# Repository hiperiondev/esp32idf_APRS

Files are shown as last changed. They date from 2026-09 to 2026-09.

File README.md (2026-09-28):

<p align="center">
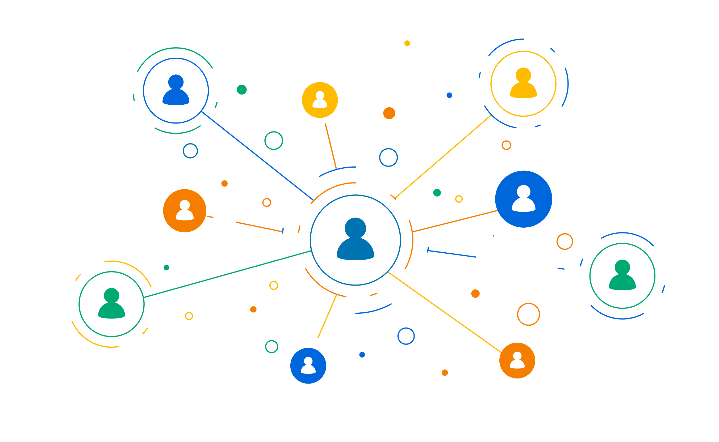
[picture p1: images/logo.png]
  
</p>

<div align="center">

# esp32idf_APRS

### A complete APRS station on a single ESP32 — native ESP-IDF, no Arduino.

**IGate · Digipeater · Tracker · Weather · Telemetry**, with a built-in web admin, an on-chip AFSK/FSK soft-modem, APRS-IS uplink, a runtime sensor-driver framework and OTA firmware updates.






**🌐 Languages:** **English** · [Español](README.es.md) · [Italiano](README.it.md)

</div>

---

## What is this?

`esp32idf_APRS` turns a bare **ESP32 DevKit** plus a cheap audio interface into a complete, self-contained **APRS** station. Everything runs on the ESP32 itself — there is no Arduino core, no PlatformIO, and no external DSP library. The entire signal chain, from the correlator demodulator through DPLL bit recovery, NRZI, the HDLC framer, the AX.25 codec and Reed–Solomon FX.25 forward error correction, executes on the microcontroller using only the SAR-ADC in continuous/DMA mode, the DAC, and a general-purpose timer.

In one sentence, the firmware **demodulates** AFSK/FSK audio from a radio's speaker or discriminator output, **decodes** HDLC/AX.25 (optionally FX.25 error-corrected) frames, **gates** them to APRS-IS over Wi-Fi, **digipeats** them back on RF, **beacons** its own position, weather and telemetry, **modulates** and transmits frames back through the ESP32's 8-bit DAC — and is configured entirely through a web admin served by the device itself. No serial console, no recompilation for ordinary settings.

> 📖 **The full, exhaustive documentation lives at [esp32idf-aprs.readthedocs.io](https://esp32idf-aprs.readthedocs.io/)** — trilingual (English / Español / Italiano), with getting-started guides, hardware wiring, the DSP signal chain, the configuration engine, HTTP routes and troubleshooting. **This README is only a presentation. For anything beyond a first look, go to the docs.**

---

## Highlights

- **On-chip soft-modem.** AFSK 1200 Bd Bell 202 (standard APRS) with up to twelve parallel demodulators (a multi-slicer set on four tilted prefilters covering about 33 dB of tone twist, from discriminator and speaker audio alike, tunable from the web admin, with a tone-band receive level meter), plus AFSK 1200 Bd V.23, AFSK 300 Bd, and **G3RUH 9600 Bd FSK** — all in pure C on the ESP32's own ADC/DAC.
- **FX.25 forward error correction.** Reed–Solomon FEC over AX.25, RX-only or RX+TX, for reliable decodes in weak-signal conditions.
- **Full APRS-IS IGate.** Bidirectional **RF→INET** and **INET→RF** gating with duplicate suppression, `qAR`/`qAO` construction, payload-type gating, callsign budlists, a local range gate (haversine distance), a prefix whitelist and, on the INET→RF side, a position requirement, a locally-heard source test and per-source spacing that keep a wide APRS-IS subscription off the local channel. Up to four APRS-IS servers can be listed, with automatic failover between the enabled ones.
- **BrandMeister APRS interconnect.** Recognises, gates and routes the APRS traffic BrandMeister injects, over the APRS-IS session the IGate already has — an `APBMxx` tocall, a `DMR` path alias or a named entry gateway identifies it. Its own page, off by default. **No DMR connection of any kind is involved.**
- **Digipeater.** A four-row n-N alias table (WIDE1-1 / WIDE2-2 / WIDE#-2 by default), each row with its own hop limit and trace/flood mode, plus hop-count trapping, fill-in-only operation and duplicate suppression.
- **Beacons, messaging & chat.** Fixed-position beacons for tracker/igate/digi, APRS text messaging with ack/retry (RF and/or INET), and an in-browser message chat UI.
- **GNSS receiver & live tracking.** An NMEA module on its own UART (RMC/GGA/GSA/GSV/VTG, multi-constellation) with a master switch, a live view page refreshed once a second, and a *Use GPS* control that fills any page's position fields from the current fix. The Tracker beacon can transmit the live fix instead of a fixed position, with SmartBeaconing making the interval speed-adaptive and pegging it on corners.
- **APRS query responder.** Answers the general `?APRS?`/`?WX?`/`?IGATE?`/`?QRU?` queries and the directed set (`?APRSD`/`?APRSH`/`?APRSM`/`?APRSO`/`?APRSP`/`?APRSS`/`?APRST`/`?PING?`), each with per-type and per-source rate limits, plus an optional periodic station-capabilities beacon.
- **Weather & telemetry.** On-air APRS Weather Reports with 1 Hz sensor refresh and per-field averaging, plus APRS Telemetry (analog A1–A5 + digital B1–B8) with `T#nnn` reports and metadata.
- **Winlink radio e-mail (APRSLink).** The station reads and writes its own `CALLSIGN@winlink.org` mail through the `WLNK-1` service — challenge/response login with the password never on the air, a paced one-command-at-a-time session, and a browser terminal whose mailbox listing carries per-message read/reply/forward/delete buttons — and, separately, relays a neighbouring RF station's own Winlink session through its IGate.
- **Objects, items & bulletins.** Up to five own-station APRS Objects/Items and five bulletins (BLN1–BLN5), each on RF and/or INET with expiry/decay control.
- **Telegram bot.** An optional bot alongside the APRS services — long polling, per-user and per-chat authorization, station-message and bulletin routing to Telegram, and a Mini App button — so the station can be checked on and lightly controlled from a phone.
- **Runtime sensor framework.** A dynamic, self-registering driver registry (`sensors_local`) — includes a BME280/BMP280 (I²C) driver out of the box, plus an optional BMP180 one on the same bus.
- **Web admin, 22 pages.** HTTP Basic auth with two accounts — an administrator and an optional read-only one that sees every page, changes nothing, and may only start and stop the console log viewer —, a live dashboard with a live traffic log (JSON long-poll) and a last-heard JSON feed, LittleFS file management (upload/download/delete/format), Wi-Fi AP/STA/AP+STA with scan and TX-power control, CPU frequency control (80/160/240 MHz), and an on-demand console log viewer that mirrors the serial output into the browser. The whole UI is responsive from one stylesheet — on a tablet or a phone the sidebar becomes a slide-in drawer, form rows collapse to a single column, wide tables scroll within the page and the controls grow to a touch size.
- **OTA updates with auto-rollback.** Dual `ota_0`/`ota_1` app slots; a failed image rolls back automatically on the next boot.
- **Trilingual UI.** English, Spanish and Italian (compile-time, one language per image).

---

## Feature matrix

| Area | Notes |
|---|---|
| AFSK 1200 Bd Bell 202 | Up to twelve parallel demodulators, default profile |
| AFSK 1200 Bd V.23 · AFSK 300 Bd · G3RUH 9600 Bd FSK | Multiple selectable modem profiles |
| HDLC / AX.25 UI frame RX + TX | Full soft-modem TX/RX path |
| FX.25 (Reed–Solomon FEC over AX.25) | RX-only / RX+TX modes |
| PTT keying | Compile-time GPIO + polarity, minimum-unkey hold |
| CSMA / TX time-slot / TXDelay preamble / TXTail | `preamble`, `tx_tail` (TXTail, default 20 ms), `tx_timeslot`, `csma_persist`, `csma_slot_ms` (SlotTime), `csma_busy_max_s` (busy-channel wait, 0 = unlimited) |
| Transmit duty-cycle limiter | Optional ceiling over a rolling 10-minute window |
| APRS-IS IGate RF→INET & INET→RF | Filters, dedup, budlist, third-party unwrap opt-in, INET→RF flood gates |
| APRS-IS multiserver failover | 4 server slots, circular retry over the enabled ones |
| Local range gate & prefix gate | Haversine distance + callsign-prefix whitelist |
| BrandMeister APRS interconnect | Recognition, gating and message routing over the existing APRS-IS session; no DMR link |
| Digipeater | Configurable n-N alias table (trace/flood), hop trapping, dup-suppression |
| Objects / Items · Bulletins | Up to 5 each, RF and/or INET, expiry/decay |
| Telegram bot | Long polling, per-user/chat authorization, message & bulletin routing, Mini App button |
| Messaging + ack/retry · Chat UI | RF and/or INET |
| Winlink radio e-mail (APRSLink) | Own mailbox over `WLNK-1`, plus gateway for local stations |
| GNSS receiver (NMEA, own UART) | Master switch, live view page, *Use GPS* position fill on every page |
| Live GPS tracking + SmartBeaconing | Tracker beacon only; speed-adaptive interval and corner-pegging |
| APRS query responder | General `?APRS?`/`?WX?`/`?IGATE?`/`?QRU?` + directed set, rate-limited; capabilities beacon |
| Weather Report | 1 Hz sensor refresh, optional averaging |
| Telemetry | Analog A1–A5 + digital B1–B8, `T#nnn` + metadata |
| Sensor driver framework | Dynamic registry, BME280/BMP280 driver included |
| Web admin | 22 pages, live dashboard, live traffic log + last-heard feed, console log viewer, per-option contextual help |
| Storage | LittleFS 512 KB, upload/download/delete/format |
| Networking | Wi-Fi AP/STA/AP+STA, scan, TX power, SNTP (UTC clock, selectable timezone for display) |
| CPU frequency control | 80 / 160 / 240 MHz |
| OTA update | `ota_0`/`ota_1` slots, auto-rollback |
| Localization | EN / ES / IT, compile-time, labels and help balloons alike |

---

## Hardware

- **Target:** ESP32 (classic, Xtensa dual-core), 4 MB flash. Dual-core is **required** — the ADC ISR and DAC sample clock are pinned to different cores on purpose.
- **Audio in (ADC):** default `GPIO33` (ADC1). **GPIO 32–39 only** — ADC2 is unusable while Wi-Fi is up.
- **Audio out (DAC):** default `GPIO25`. **GPIO 25 or 26 only** — the ESP32 DAC is hard-wired to those pads.
- **PTT:** default `GPIO26`, polarity selectable at compile time.
- **GNSS (optional):** UART2, default `GPIO16` (RX, from the module's TX) and `GPIO17` (TX). Set in `main/include/gps.h`. **Unusable on an ESP32-WROVER**, where those pins belong to the SPI PSRAM die.
- **Note:** ESP32-S3/C3/C6/H2 have **no DAC** and cannot run the TX path unmodified.

Board wiring (audio pins, PTT pin/polarity, ADC sample rate) is set as compile-time constants in the top-level `CMakeLists.txt`. A KiCad radio-interface schematic is included under `schematics/`.

The audio interface itself can be as small as one coupling capacitor and one level trimmer per direction: the Radiomodem page carries an **Audio interface** section that biases the ADC input from the pad's own pull resistors, sets the transmit output swing and sample rate, warns on receive over-range and bounds how long the transmitter may stay keyed. Every one of those settings defaults to the behaviour an interface board with its own bias network, attenuators and reconstruction filter expects, so an existing build is unaffected. Two buttons next to LOOP TEST — **RX LEVEL** and **TX TEST** — set the two trimmers once a transceiver has replaced the loopback jumper.

> Full pinout tables and wiring constraints are in the [Hardware chapter of the documentation](https://esp32idf-aprs.readthedocs.io/en/latest/en/hardware.html).

---

## Quick start

```bash
# Requires ESP-IDF v6.1 (tested and locked at 6.1)
idf.py set-target esp32
idf.py build
idf.py -p PORT flash monitor
```

On first boot the device brings up a Wi-Fi AP; connect and open the web admin to configure your callsign, radio and services. After the one-time USB/UART flash, all further updates can be done from the web admin's **About / Firmware** page over OTA.

> 📖 The step-by-step first-run guide is in [Getting Started](https://esp32idf-aprs.readthedocs.io/en/latest/en/getting-started.html).

---

## Documentation

**Everything is documented in full at 👉 [esp32idf-aprs.readthedocs.io](https://esp32idf-aprs.readthedocs.io/)**

The documentation is trilingual and organised into *Functionalities* (what the station does), *Capabilities* (cross-cutting properties), *Internals* (how it is built) and a *Reference* section:

- 🇬🇧 [English](https://esp32idf-aprs.readthedocs.io/en/latest/en/index.html)
- 🇪🇸 [Español](https://esp32idf-aprs.readthedocs.io/en/latest/es/index.html)
- 🇮🇹 [Italiano](https://esp32idf-aprs.readthedocs.io/en/latest/it/index.html)

This README is a presentation only — **please consult the documentation for installation, wiring, configuration and internals.**

---

## Credits & license

Created by **Emiliano Augusto González (LU3VEA)**.

Built on ideas from earlier projects — [VP-Digi](https://github.com/sq8vps/vp-digi), [ESP32APRS](https://github.com/nakhonthai/ESP32APRS_Audio) and [LibAPRS](https://github.com/markqvist/LibAPRS); please refer to their authors for more information.

Released under the **GNU General Public License v3**. See [LICENSE](LICENSE).

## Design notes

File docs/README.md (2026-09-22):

# esp32idf_APRS — Documentation

Exhaustive, trilingual (English / Español / Italiano) documentation for the
`esp32idf_APRS` firmware, built with [Sphinx](https://www.sphinx-doc.org/) and
the [Breeze](https://pypi.org/project/sphinx-breeze-theme/) theme, ready to
publish on Read the Docs.

## Layout

```
esp32_APRS_igate/
├── .readthedocs.yaml    Read the Docs build config (repo root, not docs/)
└── docs/
    ├── root/index.html      language-chooser landing page ("first page")
    ├── _shared/conf_base.py shared Sphinx config (theme, extensions, language switcher)
    ├── en/                  English source tree (conf.py + .rst + _static/)
    ├── es/                  Spanish source tree (conf.py + .rst + _static/)
    ├── it/                  Italian source tree (conf.py + .rst + _static/)
    ├── schematics/          radio-interface schematics (TX, RX, PTT) shared by the
    │                        three hardware.rst pages through ../schematics/
    ├── dataflow/, tuning/   master copies of the per-language data-flow and tuning
    │                        figures (each tree embeds its own copy from _static/)
    ├── _static/             master copies of custom.css and logo.png (not read by Sphinx)
    ├── requirements.txt     Sphinx + Breeze theme pins
    └── build_all.py         builds all three trees into ./_site
```
Each language tree carries its own `_static/` (identical copies of `custom.css`,
`logo.png` and `welcome_logo.png`, plus that language's `dataflow/` and `tuning/`
figures) since each is an independent Sphinx project and Sphinx only looks up
`html_static_path` inside its own source tree. The top-level `docs/_static/`,
`docs/dataflow/` and `docs/tuning/` folders are only the master copies those
trees are refreshed from; no build reads them, so an edited image or stylesheet
must be copied into each language's `_static/` to take effect. `logo.png` is the small top-bar brand
logo (set via `light_logo`/`dark_logo` in `_shared/conf_base.py`);
`welcome_logo.png` is the larger centered image at the top of each language's
Welcome page (`index.rst`). The two are independent by design.

Each language tree is a complete, independent Sphinx project. The three are
linked as **siblings** by the per-page language switcher (the globe menu in the
Breeze top bar): from any page in one language you can jump straight to the same
page in another. The `root/index.html` landing page lets a first-time visitor
pick a language.

The chapters are organised by **Functionality** (what the station does),
**Capability** (cross-cutting properties), and **Internals** (how it is built),
plus a **Reference** section.

## Build locally

```bash
python -m venv .venv && . .venv/bin/activate
pip install -r requirements.txt
python build_all.py
# open _site/index.html
```

Or build a single language on its own:

```bash
cd en && python -m sphinx -b html . _build   # then open _build/index.html
```

## Publish on Read the Docs

The included `.readthedocs.yaml` points its `sphinx:` block at the English tree
only to satisfy Read the Docs. Its `post_build` job then wipes that output and
rebuilds all three trees into sibling `en/`, `es/` and `it/` folders, placing
the landing page at the root — reproducing the sibling layout the switcher
needs, exactly like `build_all.py`. No dashboard configuration is required
beyond importing the repository.

Both `build_all.py` and the Read the Docs job run Sphinx with `-W`, so any
warning (a broken cross-reference, a missing image, a malformed table) fails
the build. Run `python build_all.py` locally before pushing a documentation
change.

## Requirements

* Python 3.10+
* Sphinx ≥ 8.1, < 9  (Sphinx 9 is not yet compatible with the Breeze theme)
* sphinx-breeze-theme 0.13.x

Both are pinned in `requirements.txt`.

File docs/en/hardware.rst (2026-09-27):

.. _en-hardware:

========
Hardware
========

Supported target
================

* **ESP32** (classic, Xtensa dual-core) — ``CONFIG_IDF_TARGET=esp32``, 4 MB
  flash.
* Dual-core is **not optional**: the ADC ISR and the DAC sample clock are
  pinned to *different* cores on purpose (see :ref:`en-dsp-signal-chain`).
* ESP32-S2 has DACs on GPIO17/18 and would need the config header adjusted.
  **ESP32-S3/C3/C6/H2 have no DAC at all** and cannot run the TX path
  unmodified.

Pinout / board definition
=========================

The board definition lives in the **top-level** ``CMakeLists.txt``, applied
*before* ``project()`` via ``idf_build_set_property(COMPILE_DEFINITIONS …
APPEND)``:

.. code-block:: cmake

   idf_build_set_property(COMPILE_DEFINITIONS "MODEM_ADC_GPIO=33"       APPEND)
   idf_build_set_property(COMPILE_DEFINITIONS "MODEM_DAC_GPIO=25"       APPEND)
   idf_build_set_property(COMPILE_DEFINITIONS "MODEM_PTT_GPIO=26"       APPEND)
   idf_build_set_property(COMPILE_DEFINITIONS "MODEM_PTT_ACTIVE_HIGH=1" APPEND)
   idf_build_set_property(COMPILE_DEFINITIONS "MODEM_LED_TX_GPIO=-1"    APPEND)
   idf_build_set_property(COMPILE_DEFINITIONS "MODEM_LED_RX_GPIO=-1"    APPEND)

.. list-table::
   :header-rows: 1
   :widths: 20 20 60

   * - Signal
     - Default
     - Hard constraints
   * - **Audio in (ADC)**
     - ``GPIO33`` (ADC1_CH5)
     - **32–39 only.** ADC2 is unusable while Wi-Fi is up, and this firmware
       always has Wi-Fi up. Enforced by a compile-time ``#error``.
   * - **Audio out (DAC)**
     - ``GPIO25`` (DAC_CHAN_0)
     - **25 or 26 only.** The ESP32 DAC is hard-wired to those pads and is not
       routable through the GPIO matrix. Enforced by ``#error``.
   * - **PTT**
     - ``GPIO26``
     - Any output-capable GPIO not equal to the ADC/DAC pins; rejects
       input-only GPIO34–39 and flash/PSRAM GPIO6–11. ``-1`` disables it.
       Both the pin **and its polarity** are compile-time constants.
   * - **TX / RX LEDs**
     - disabled (``-1``)
     - Any output-capable GPIO.
   * - **GNSS receive (UART RX)**
     - ``GPIO16``
     - Wired to the module's TX output. Any input-capable GPIO the UART
       matrix can reach. **Unusable on an ESP32-WROVER**, where GPIO16/17
       belong to the SPI PSRAM die. Set in ``main/include/gps.h``.
   * - **GNSS transmit (UART TX)**
     - ``GPIO17``
     - Wired to the module's RX input. Nothing is ever sent on it — the
       firmware never configures the receiver — but the pin is still
       reserved, since it is physically connected to that input.

Wiring to a radio
=================

Neither end of the audio link can be connected directly to the other. The
ESP32 side is a 3.3 V, DC-biased, sampled-data interface; the radio side is an
AC, ground-referenced, millivolt-level analogue interface. Three things have
to happen in between: **attenuate** (TX), **shift and clamp** (RX), and
**switch** (PTT).

What each end presents
----------------------

Every ESP32-side figure below is derived from the modem component's own
compile-time constants, not from a datasheet ideal.

.. list-table::
   :header-rows: 1
   :widths: 26 50 24

   * - Node
     - What is really there
     - From
   * - **GPIO25 (DAC), transmitting**
     - 1.65 V DC with a ≈1.97 Vpp swing on top ⇒ ≈0.70 Vrms for a sine, plus
       reconstruction images around 38.4 kHz
     - ``DAC_MID=128``, ``AMPLITUDE_PCT=60``, ``DAC_SAMPLERATE=38400``
   * - **GPIO33 (ADC)**
     - Window 0–3.1 V; AGC targets 310 mVrms at the pin, reaches it from as
       little as ≈39 mVrms, holds below ≈3.3 mVrms, clips above ≈1.1 Vrms
     - ``ADC_ATTEN_DB_12``, ``AGC_TARGET_RMS=0.2``
   * - Rig **MIC IN**
     - 5–20 mVrms, often pre-emphasised, DC bias for the electret
     - needs ≈30–40 dB of pad
   * - Rig **DATA IN** (mini-DIN-6)
     - ≈40 mVpp ⇒ ≈14 mVrms, flat, no pre-emphasis
     - needs ≈35 dB of pad
   * - Rig **SPKR / AF OUT**
     - 0.1–3 Vrms, volume-knob dependent, de-emphasised
     - needs a pad + bias
   * - Rig **DATA OUT / DISC**
     - 100–300 mVrms, fixed level, squelch-independent, flat
     - needs bias only — this is the good one

Two consequences worth internalising before soldering:

* **The DAC is ~35 dB too hot** for anything on the radio. A direct
  connection will not merely over-deviate, it will splatter.
* **A DATA OUT port is already inside the AGC window** (100–300 mVrms vs. the
  39 mVrms–1.1 Vrms usable range). If your rig has a data jack, the RX side is
  a bias network and nothing else — no pot, no gain.

Minimal functional schematic
----------------------------

Passive, ~15 parts, no op-amps.

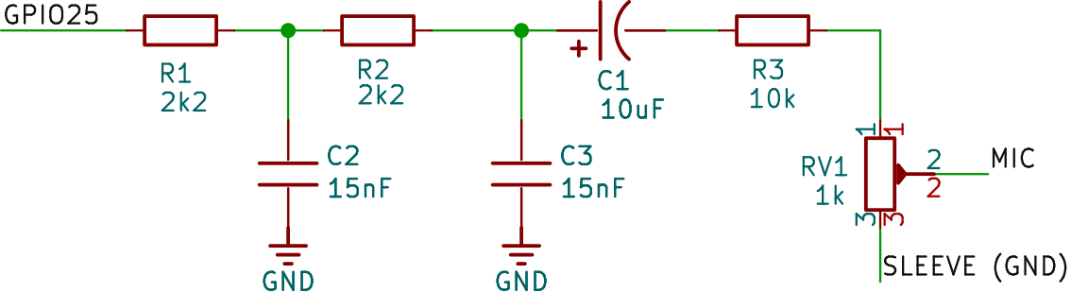
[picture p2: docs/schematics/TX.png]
TX schematic — ESP32 DAC to rig audio input


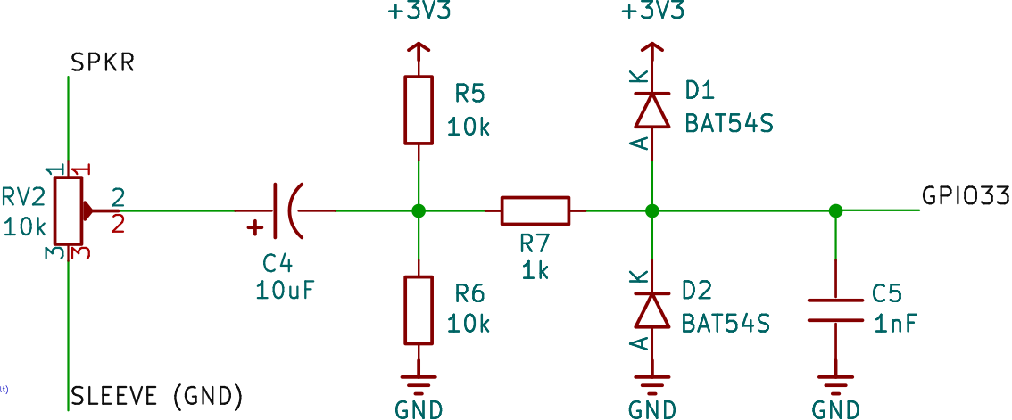
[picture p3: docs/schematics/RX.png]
RX schematic — rig audio output to ESP32 ADC


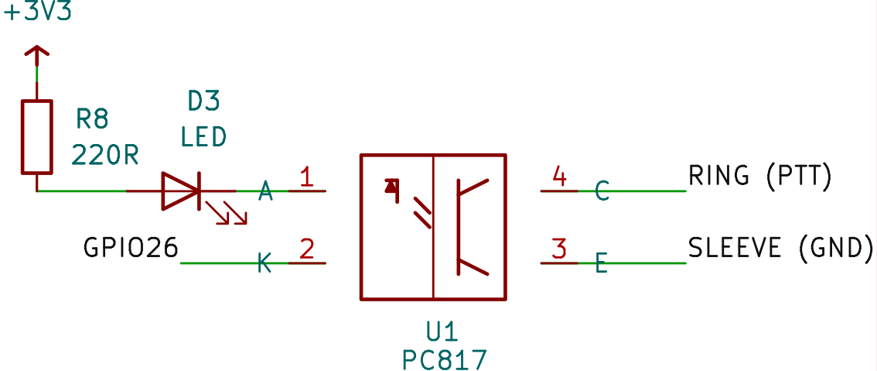
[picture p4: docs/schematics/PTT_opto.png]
PTT schematic, option A — optocoupler (PC817), isolated


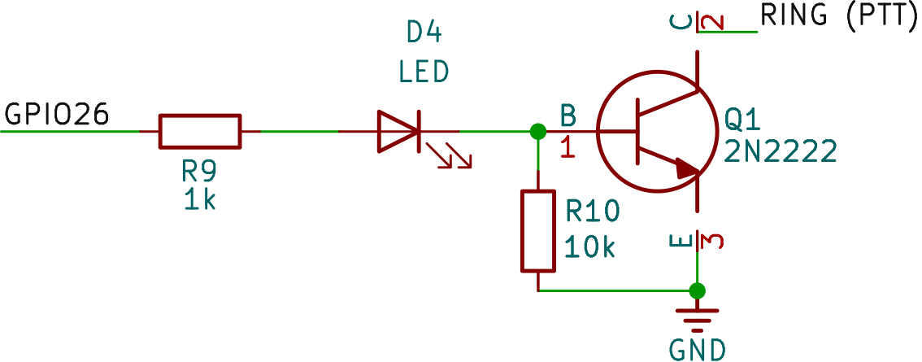
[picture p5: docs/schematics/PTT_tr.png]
PTT schematic, option B — NPN transistor (2N2222/BC547), non-isolated


Key component roles: R1/R2 + C2/C3 form a two-pole reconstruction low-pass
(fc ≈ 4.8 kHz) that kills the 38.4 kHz DAC images; C1 blocks the DAC's 1.65 V
idle bias from the mic input; R3/RV1 pad and trim the TX level; R5/R6 set a
mid-rail 1.65 V bias for the ADC; R7/C5 snubs the SAR sampling-cap charge
kick; D1/D2 clamp the ADC pin to the rails. For **9600 Bd G3RUH** replace
C2/C3 with 10 nF (fc ≈ 7.2 kHz) to keep the audio flat past ~5 kHz.

.. warning::

   **The PTT default is a trap.** The shipped board definition is
   ``MODEM_PTT_ACTIVE_HIGH=1`` in this revision. Pick a PTT driver whose
   polarity matches the config, or change the config to match your driver. An
   opto (option A) inverts and suits ``ACTIVE_HIGH=0``; a plain NPN low-side
   switch (option B) does not invert and needs ``ACTIVE_HIGH=1``. Always
   verify with a meter that the PTT line is *open* through reset, through the
   whole ~5 s boot, and while idle **before connecting the radio** —
   ``modem_init()`` blocks ~5 s calibrating the ADC clock and beacons transmit
   on entry, so a wrong-polarity PTT gives you seconds of unmodulated carrier.
   The firmware drives the PTT pin to its idle level as the first step of
   ``app_main()``. Before that — through the ROM and the second-stage
   bootloader, about 0.3–0.5 s after every reset (EN pin, brownout, OTA or
   remote reboot) — the pin is an unconfigured input with no pull, and only the
   keying stage's own bias on its control input keeps the radio unkeyed.

Reduced interface: one capacitor and one trimmer per direction
--------------------------------------------------------------

The schematic above is the reference build. A reduced interface is also
supported, carrying nothing but a coupling capacitor and a level trimmer in
each audio direction, with PTT unchanged. What the removed parts used to do
is either taken over by a setting on the Radiomodem page or accepted as a
limitation:

.. list-table::
   :header-rows: 1
   :widths: 30 70

   * - Removed
     - Replacement
   * - R5/R6 (ADC bias)
     - **ADC input self-bias**, which connects the pad's own pull-up and
       pull-down in series
   * - R3 (TX pad)
     - the trimmer alone, optionally with **Transmit output swing** lowered to
       spread its useful range
   * - R1/R2 + C2/C3 (reconstruction filter)
     - **Transmit sample rate** set to 76800 Hz, which moves the images an
       octave up
   * - D1/D2 (input clamp)
     - nothing: **Warn on receive over-range** reports the condition, the
       receive trimmer is what limits the fault current
   * - R7/C5 (ADC snubber)
     - nothing; expect slightly more noise

Wiring, per direction: the transmit trimmer is a divider between GPIO25 and
ground with its wiper feeding the coupling capacitor, and the receive trimmer
is a divider across the transceiver's speaker output with its wiper feeding
the other capacitor. **The capacitor goes after the trimmer on both sides.**
Ahead of it the trimmer's lower leg would tie the ADC pin to ground, which
defeats the self-bias, and on the transmit side it would collapse the
microphone input's own bias.

The transmit capacitor should be 1 µF or larger. The receive capacitor forms
a first-order high-pass with the self-bias resistors (about 22 kΩ between the
pad's pull-up and pull-down, which vary from part to part), and its value
depends on the audio the transceiver delivers:

* **Flat (discriminator / data) audio: 1 µF or larger**, corner about 7 Hz.
  The input is left as it is.
* **De-emphasized (speaker) audio: 10 nF**, corner about 700 Hz (roughly
  500–900 Hz with the spread of the internal resistors). De-emphasis lifts
  everything below the tones by 6 dB per octave, so a speaker output carries
  bass well above the tones; through a large capacitor that bass fills the
  converter's range and leaves the tones only a few counts above the ADC's own
  noise, which the high-pass on the Radiomodem page cannot recover because it
  runs after the converter. Ahead of the ADC the 10 nF capacitor removes it,
  and at the same time it takes 1.3 dB off the 1200 Hz mark tone and 0.4 dB off
  the 2200 Hz space tone, a little of the space-tone lift de-emphasized audio
  needs. Use a ceramic or film part: it has no polarity.

A 100 nF capacitor puts the corner at about 70 Hz, which keeps the bass and so
behaves like the 1 µF one.

Use 10 kΩ trimmers: on the transmit side that keeps the load on the DAC
output light, and the attenuation needed there puts the wiper at roughly 1.4 %
of travel, so a multiturn trimmer is what makes it settable at all.

Set the levels with the two buttons next to LOOP TEST, which is what the loop
test cannot do once a transceiver has replaced the jumper: **RX LEVEL**
measures without transmitting — aim for the **good** verdict, a tone-band
level of at least 20 mV RMS (on a flat input, 250 to 350 mV RMS wideband is
a comfortable level), with the raw range well clear of 0 and 4095, and with the self-bias on expect a DC offset between
1200 and 2000 mV — and **TX TEST** keys up so the deviation can be read on
other equipment and trimmed to 2.5 to 3.5 kHz.

.. warning::

   Without D1/D2 the receive trimmer is the only thing limiting current into
   the ADC pin. A hand-held's speaker output at full volume is far outside
   0 to 3.3 V, so set the volume low before plugging in and never wire the
   speaker output to GPIO33 through the capacitor alone.

Baofeng UV-5R and K-plug HTs
----------------------------

The UV-5R (and Kenwood-K1-style two-pin clones: UV-82, BF-888, GT-3, RT-5R…)
exposes two plugs rather than a combined jack:

.. list-table::
   :header-rows: 1
   :widths: 22 22 56

   * - Plug
     - Size
     - Signal
   * - Large
     - 3.5 mm TS
     - Tip = SPKR audio out, Sleeve = GND
   * - Small
     - 2.5 mm TRS
     - Tip = MIC in, Ring = PTT (short to sleeve to key), Sleeve = GND

There is **no separate UV-5R circuit** — build the minimal schematic exactly
as above; only where the three off-board leads land changes, because the rig
splits "rig" across two plugs. Note that these HTs have **no discriminator
jack**, so 9600 Bd G3RUH is out of reach; **AFSK 1200 Bd Bell 202 is the
realistic ceiling** through the stock 2-pin connector. Verify the plug pinout
with a meter before soldering — cheap aftermarket cables sometimes swap mic
and PTT.

Bring-up order
==============

#. **Loop test first, no radio.** Wire GPIO25 → GPIO33 with a plain wire (see
   :ref:`en-web-admin` and the LOOP TEST). If that fails, no external circuit
   will help.
#. **RX next, still no TX.** Open the squelch, feed real traffic in, and watch
   the **AUDIO** column of the live traffic table (the modem's own mVrms at
   the pin). Trim RV2 for **≈300 mVrms on packets** — the AGC's target, where
   the loop sits at unity with the most headroom.
#. **TX last, into a dummy load.** Set RV1 for **≈3.0 kHz deviation**
   (2.5–3.5 kHz). Over-deviation is the single most common cause of "my igate
   hears everyone but nobody hears me".
#. **9600 Bd G3RUH** needs the flat/discriminator path at both ends: DATA
   IN/DATA OUT, 10 nF in C2/C3, and the *Flat / discriminator audio input*
   checkbox ticked.

Isolation and ground loops
==========================

The passive circuit shares a ground with the radio, the normal source of hum,
alternator whine and "it works until I transmit". If you hear any of that, use
600:600 Ω audio isolation transformers in place of C1 and C4, keep the opto
(option A) so the PTT return does not re-create the ground you just broke, and
fight RF ingress with shielded cable, short leads, a clamp-on ferrite at the
rig connector and 47–100 pF from each audio line to the rig's chassis.

.. _en-loop-test-tuning:

Tuning procedure
=================

Reference points
-----------------

.. list-table::
   :header-rows: 1
   :widths: 34 20 46

   * - Signal
     - GPIO
     - Function
   * - DAC (TX audio out)
     - GPIO25
     - AFSK transmit audio
   * - ADC (RX audio in)
     - GPIO33
     - AFSK receive audio
   * - PTT out
     - GPIO26
     - Radio keying

.. list-table::
   :header-rows: 1
   :widths: 12 12 30 46

   * - Trimmer
     - Value
     - Location
     - Function
   * - **RV1**
     - 1 kΩ
     - Between DAC and the interface's ``MIC`` output terminal
     - **TX audio level** — sets drive strength into the radio's mic/audio-in
   * - **RV2**
     - 10 kΩ
     - Between the interface's ``SPKR`` input terminal and the ADC
     - **RX audio level** — attenuates the radio's speaker/audio-out down to
       what the ADC expects

1. Method A — Bare modem loopback test
----------------------------------------

Use this to verify the ESP32's own DAC/ADC/AX.25 chain in isolation, before
involving the interface board.

1.1 Minimal schematic
^^^^^^^^^^^^^^^^^^^^^^

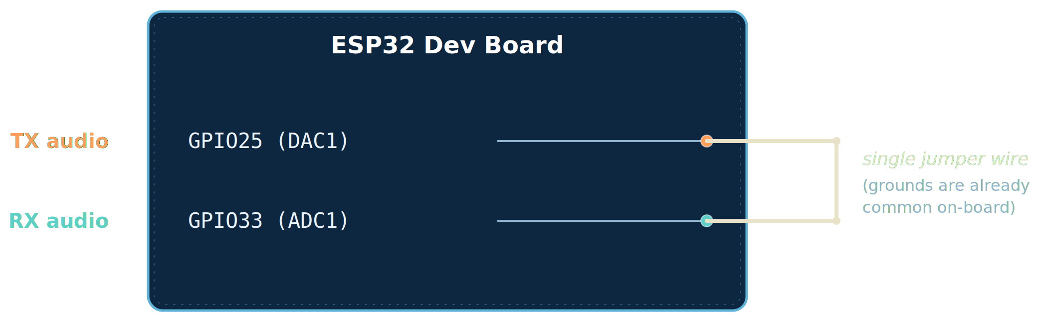
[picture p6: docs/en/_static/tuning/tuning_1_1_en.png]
Minimal loopback schematic — ESP32 GPIO25 (DAC1) jumpered to GPIO33 (ADC1)


One jumper wire, GPIO25 → GPIO33. Both pins are 0–3.3 V single-ended and
share the board's ground plane, so no coupling capacitor or attenuator is
required for a pass/fail result.

1.2 Procedure
^^^^^^^^^^^^^^

#. Wire the jumper as above (power off first).
#. Enable the audio modem in the web UI (Radio/Modem page → "Enable audio
   ADC/DAC modem" → Save → reboot).
#. Open the serial console to observe results.
#. Run the self-test from the Radio/Modem page's **LOOP TEST** button (or the
   equivalent web endpoint).
#. Read the resulting ``PASS``/``FAIL`` line, which reports RX level (mV
   RMS), raw ADC swing, and AGC gain, plus — on failure — a specific
   stage-by-stage diagnosis.
#. Repeat 3–5 times to rule out an intermittent connection before drawing
   conclusions.

1.3 Interpreting the result
^^^^^^^^^^^^^^^^^^^^^^^^^^^^

.. list-table::
   :header-rows: 1
   :widths: 34 66

   * - Result
     - Meaning
   * - ``PASS``
     - Full TX→RX→HDLC→CRC path is functionally correct
   * - ``FAIL``, ADC never sampled
     - ADC driver/init issue, not the jumper
   * - ``FAIL``, flat/near-DC line
     - No signal reaching the ADC — check the jumper and grounds
   * - ``FAIL``, signal present but no lock
     - Tone reaches the ADC but the demodulator's PLL never syncs — check AGC
       gain (near 1.0× points at the AGC path) or the baud-rate/modem-type
       setting
   * - ``FAIL``, PLL locked, no frame (stage < FRAME)
     - Bit-sync never starts a frame — deeper bit-recovery issue
   * - ``FAIL``, PLL locked, no frame (stage = FRAME)
     - Framing works but CRC fails — marginal signal/clipping
   * - ``FAIL``, content mismatch
     - Frame received but corrupted — distortion, clipping, or a loose
       loopback wire

2. Method B — Interface-board loopback (through RV1/RV2)
-----------------------------------------------------------

Use this to validate — and tune — the actual audio interface board,
including both level trimmers, with no radio attached.

2.1 Minimal schematic
^^^^^^^^^^^^^^^^^^^^^^

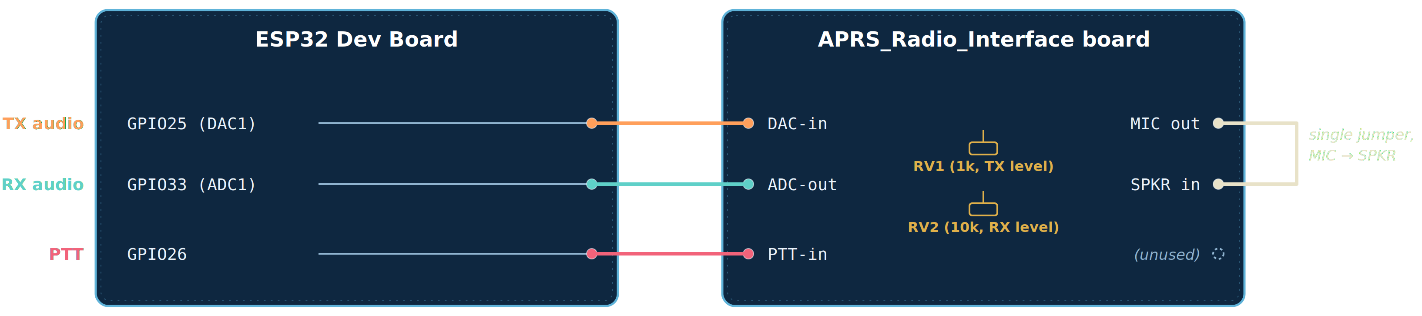
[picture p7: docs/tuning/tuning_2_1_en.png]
Minimal interface-board loopback schematic — ESP32 DAC/ADC/PTT wired to the APRS_Radio_Interface board, with a jumper from MIC out to SPKR in


Wire the interface board to the ESP32 exactly as for normal operation
(DAC/ADC/PTT), then add **one extra jumper on the interface board itself,
from its** ``MIC`` **output terminal to its** ``SPKR`` **input terminal.**
No radio is connected. This closes the loop through the full analog chain —
both trimmers, coupling caps, and level networks.

2.2 What to read
^^^^^^^^^^^^^^^^^^

Each self-test run (§1.2, step 4) now reports, whether it passes or fails:

* **RX level**, in mV RMS
* **Raw ADC swing** (min–max, out of a 0–4095 12-bit range) — the
  clipping-margin indicator
* **AGC peak gain**

These three numbers are what stand in for an oscilloscope trace when tuning
the trimmers below.

3. Trimmer tuning procedure (RV1 then RV2)
----------------------------------------------

Perform this with the loop wired as in §2.1, running the self-test after
every adjustment.

#. **Start low.** Set RV1 (TX level) near minimum and RV2 (RX level) at
   roughly mid-travel.
#. **Sweep RV1 upward**, running the test at each step:

   * **Too low:** ``FAIL`` — weak/no PLL lock, small raw ADC swing, low RMS.
   * **Too high:** raw ADC swing approaches the rails (toward 0 and/or
     4095), eventually causing a content-mismatch or CRC failure.
   * Note the **range of RV1 positions that give a clean** ``PASS`` with the
     swing comfortably clear of both rails.

#. **Set RV1 to the middle of that passing range** — not an edge — so
   there's equal margin against a weak connection on one side and clipping
   on the other.
#. **With RV1 fixed, sweep RV2** the same way:

   * **Too low:** weak RMS, marginal or absent DCD lock.
   * **Too high:** swing nears the rails, distortion/CRC failures.
   * Set RV2 to the middle of its own passing range.

#. **Re-verify.** Run the self-test 3–5 times back to back at the chosen
   settings. All runs should ``PASS``, with the swing staying clear of both
   rails and RMS comfortably above the "no lock" threshold seen during the
   sweep.
#. **Record the final positions** (e.g. "RV1: 40% from minimum, RV2: 55%
   from minimum") for future reference, since trimmers can drift or get
   bumped.

No scope is needed at any point: the swing/RMS/AGC readings from each
self-test run substitute for it, and the PASS/FAIL boundary itself marks the
edges of each trimmer's usable window.

Partition table
===============

The firmware ships an OTA-enabled 4 MB layout (``partitions.csv``):

.. list-table::
   :header-rows: 1
   :widths: 20 12 12 16 14 26

   * - Name
     - Type
     - SubType
     - Offset
     - Size
     - Notes
   * - ``nvs``
     - data
     - nvs
     - 0x9000
     - 24 K
     -
   * - ``otadata``
     - data
     - ota
     - 0xF000
     - 8 K
     -
   * - ``phy_init``
     - data
     - phy
     - 0x11000
     - 4 K
     -
   * - ``ota_0``
     - app
     - ota_0
     - 0x20000
     - **1728 K**
     - first app slot
   * - ``ota_1``
     - app
     - ota_1
     - 0x1D0000
     - **1728 K**
     - second app slot
   * - ``storage``
     - data
     - spiffs
     - 0x380000
     - **512 K**
     - mounted as **LittleFS** at ``/storage``

Two app slots let the web-admin OTA update flash whichever slot is not
currently running and roll back automatically if the new image fails the
post-boot self-check. A device still on the old single-``factory`` table needs
one serial reflash to migrate onto this layout; every update after that can go
through the web admin.

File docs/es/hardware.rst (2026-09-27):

.. _es-hardware:

========
Hardware
========

Objetivo soportado
==================

* **ESP32** (clásico, Xtensa de doble núcleo) — ``CONFIG_IDF_TARGET=esp32``,
  4 MB de flash.
* El doble núcleo **no es opcional**: la ISR del ADC y el reloj de muestreo del
  DAC se fijan a *núcleos distintos* a propósito (véase
  :ref:`es-dsp-signal-chain`).
* El ESP32-S2 tiene DAC en GPIO17/18 y requeriría ajustar la cabecera de
  configuración. **El ESP32-S3/C3/C6/H2 no tiene DAC** y no puede ejecutar la
  ruta de TX sin modificar.

Pinout / definición de placa
============================

La definición de placa vive en el ``CMakeLists.txt`` **de nivel superior**,
aplicada *antes* de ``project()`` mediante
``idf_build_set_property(COMPILE_DEFINITIONS … APPEND)``:

.. code-block:: cmake

   idf_build_set_property(COMPILE_DEFINITIONS "MODEM_ADC_GPIO=33"       APPEND)
   idf_build_set_property(COMPILE_DEFINITIONS "MODEM_DAC_GPIO=25"       APPEND)
   idf_build_set_property(COMPILE_DEFINITIONS "MODEM_PTT_GPIO=26"       APPEND)
   idf_build_set_property(COMPILE_DEFINITIONS "MODEM_PTT_ACTIVE_HIGH=1" APPEND)
   idf_build_set_property(COMPILE_DEFINITIONS "MODEM_LED_TX_GPIO=-1"    APPEND)
   idf_build_set_property(COMPILE_DEFINITIONS "MODEM_LED_RX_GPIO=-1"    APPEND)

.. list-table::
   :header-rows: 1
   :widths: 20 20 60

   * - Señal
     - Por defecto
     - Restricciones estrictas
   * - **Audio in (ADC)**
     - ``GPIO33`` (ADC1_CH5)
     - **Solo 32–39.** El ADC2 es inutilizable con Wi-Fi activo, y este firmware
       siempre tiene Wi-Fi activo. Forzado por un ``#error`` de compilación.
   * - **Audio out (DAC)**
     - ``GPIO25`` (DAC_CHAN_0)
     - **Solo 25 o 26.** El DAC del ESP32 está cableado a esos pads y no es
       enrutable por la matriz GPIO. Forzado por ``#error``.
   * - **PTT**
     - ``GPIO26``
     - Cualquier GPIO de salida distinto de los pines ADC/DAC; rechaza los
       GPIO34–39 solo-entrada y GPIO6–11 flash/PSRAM. ``-1`` lo deshabilita.
       Tanto el pin **como su polaridad** son constantes de compilación.
   * - **LEDs TX / RX**
     - deshabilitados (``-1``)
     - Cualquier GPIO de salida.
   * - **Recepción GNSS (UART RX)**
     - ``GPIO16``
     - Cableado a la salida TX del módulo. Cualquier GPIO de entrada que
       alcance la matriz UART. **Inutilizable en un ESP32-WROVER**, donde
       GPIO16/17 pertenecen al die de PSRAM SPI. Se fija en
       ``main/include/gps.h``.
   * - **Transmisión GNSS (UART TX)**
     - ``GPIO17``
     - Cableado a la entrada RX del módulo. Nunca se envía nada por él — el
       firmware jamás configura el receptor — pero el pin queda igualmente
       reservado, porque está físicamente conectado a esa entrada.

Cableado a una radio
====================

Ningún extremo del enlace de audio puede conectarse directamente al otro. El
lado del ESP32 es una interfaz de 3,3 V, polarizada en DC y de datos
muestreados; el lado de la radio es una interfaz analógica de AC, referida a
tierra y de nivel milivoltio. Tres cosas deben ocurrir en medio: **atenuar**
(TX), **desplazar y limitar** (RX) y **conmutar** (PTT).

Qué presenta cada extremo
-------------------------

Cada cifra del lado del ESP32 se deriva de las propias constantes de
compilación del componente de módem, no de un ideal de hoja de datos.

.. list-table::
   :header-rows: 1
   :widths: 26 50 24

   * - Nodo
     - Qué hay realmente
     - De
   * - **GPIO25 (DAC), transmitiendo**
     - 1,65 V DC con una oscilación ≈1,97 Vpp encima ⇒ ≈0,70 Vrms para una
       sinusoide, más imágenes de reconstrucción en torno a 38,4 kHz
     - ``DAC_MID=128``, ``AMPLITUDE_PCT=60``, ``DAC_SAMPLERATE=38400``
   * - **GPIO33 (ADC)**
     - Ventana 0–3,1 V; el AGC apunta a 310 mVrms en el pin, lo alcanza desde
       tan solo ≈39 mVrms, se mantiene por debajo de ≈3,3 mVrms, recorta por
       encima de ≈1,1 Vrms
     - ``ADC_ATTEN_DB_12``, ``AGC_TARGET_RMS=0.2``
   * - Radio **MIC IN**
     - 5–20 mVrms, a menudo con preénfasis y polarización DC para el electret
     - necesita ≈30–40 dB de atenuación
   * - Radio **DATA IN** (mini-DIN-6)
     - ≈40 mVpp ⇒ ≈14 mVrms, plano, sin preénfasis
     - necesita ≈35 dB de atenuación
   * - Radio **SPKR / AF OUT**
     - 0,1–3 Vrms, dependiente del volumen, con deénfasis
     - necesita atenuación + polarización
   * - Radio **DATA OUT / DISC**
     - 100–300 mVrms, nivel fijo, independiente del squelch, plano
     - solo necesita polarización — este es el bueno

Dos consecuencias que conviene interiorizar antes de soldar:

* **El DAC está ~35 dB demasiado caliente** para cualquier cosa de la radio.
  Una conexión directa no solo sobredesviará, sino que provocará *splatter*.
* **Un puerto DATA OUT ya está dentro de la ventana del AGC** (100–300 mVrms
  frente al rango útil 39 mVrms–1,1 Vrms). Si tu equipo tiene toma de datos, el
  lado de RX es solo una red de polarización — sin potenciómetro, sin ganancia.

Esquema funcional mínimo
------------------------

Pasivo, ~15 componentes, sin amplificadores operacionales.

Esquema TX — DAC del ESP32 a la entrada de audio de la radio

Esquema RX — salida de audio de la radio al ADC del ESP32

Esquema de PTT, opción A — optoacoplador (PC817), aislado

Esquema de PTT, opción B — transistor NPN (2N2222/BC547), no aislado

Funciones clave: R1/R2 + C2/C3 forman un paso-bajo de reconstrucción de dos
polos (fc ≈ 4,8 kHz) que elimina las imágenes del DAC a 38,4 kHz; C1 bloquea la
polarización de reposo de 1,65 V del DAC hacia la entrada de micrófono; R3/RV1
atenúan y ajustan el nivel de TX; R5/R6 fijan una polarización a media tensión
de 1,65 V para el ADC; R7/C5 amortiguan el pico de carga del condensador de
muestreo del SAR; D1/D2 limitan el pin del ADC a los raíles. Para **9600 Bd
G3RUH** reemplaza C2/C3 por 10 nF (fc ≈ 7,2 kHz) para mantener el audio plano
más allá de ~5 kHz.

.. warning::

   **El valor por defecto de PTT es una trampa.** La definición de placa que se
   distribuye es ``MODEM_PTT_ACTIVE_HIGH=1`` en esta revisión. Elige un
   controlador de PTT cuya polaridad coincida con la configuración, o cambia la
   configuración para que coincida con tu controlador. Un opto (opción A)
   invierte y encaja con ``ACTIVE_HIGH=0``; un simple NPN de conmutación por
   lado bajo (opción B) no invierte y necesita ``ACTIVE_HIGH=1``. Verifica
   siempre con un polímetro que la línea de PTT esté *abierta* durante el reset,
   durante todo el arranque de ~5 s, y en reposo **antes de conectar la radio**
   — ``modem_init()`` se bloquea ~5 s calibrando el reloj del ADC y las balizas
   transmiten al entrar, por lo que una polaridad de PTT equivocada te dará
   segundos de portadora sin modular. El firmware lleva el pin de PTT a su
   nivel de reposo como primer paso de ``app_main()``. Antes de eso — durante la
   ROM y el bootloader de segunda etapa, unos 0,3–0,5 s después de cada reset
   (pin EN, brownout, OTA o reinicio remoto) — el pin es una entrada sin
   configurar y sin pull, y solo la polarización propia de la etapa de
   conmutación en su entrada de control mantiene la radio sin transmitir.

Interfaz reducida: un capacitor y un trimmer por sentido
--------------------------------------------------------

El esquema anterior es la versión de referencia. También se admite una
interfaz reducida, que no lleva más que un capacitor de acoplamiento y un
trimmer de nivel en cada sentido de audio, con el PTT sin cambios. Lo que
hacían las piezas suprimidas lo asume un ajuste de la página Radiomodem o se
acepta como limitación:

.. list-table::
   :header-rows: 1
   :widths: 30 70

   * - Suprimido
     - Reemplazo
   * - R5/R6 (polarización del ADC)
     - **Polarización interna de la entrada del ADC**, que conecta en serie el
       pull-up y el pull-down del propio pad
   * - R3 (atenuador de TX)
     - solo el trimmer, opcionalmente con la **Amplitud de salida de
       transmisión** reducida para repartir su rango útil
   * - R1/R2 + C2/C3 (filtro de reconstrucción)
     - **Frecuencia de muestreo de transmisión** en 76800 Hz, que sube una
       octava las imágenes
   * - D1/D2 (recorte de entrada)
     - nada: **Avisar cuando el audio recibido se sale de rango** informa la
       condición y el trimmer de recepción es lo que limita la corriente de
       falla
   * - R7/C5 (amortiguador del ADC)
     - nada; espere algo más de ruido

Cableado, por sentido: el trimmer de transmisión es un divisor entre GPIO25 y
masa cuyo cursor alimenta el capacitor de acoplamiento, y el trimmer de
recepción es un divisor sobre la salida de altavoz del equipo cuyo cursor
alimenta el otro capacitor. **El capacitor va después del trimmer en ambos
lados.** Delante de él, la pata inferior del trimmer dejaría el pin del ADC a
masa, lo que anula la polarización interna, y del lado de transmisión hundiría
la polarización propia de la entrada de micrófono.

El capacitor de transmisión debe ser de 1 µF o más. El de recepción forma un
pasa-altos de primer orden con las resistencias de la autopolarización (unos
22 kΩ entre el pull-up y el pull-down del pad, que varían de una pieza a otra),
y su valor depende del audio que entrega el equipo:

* **Audio plano (discriminador / datos): 1 µF o más**, corte en unos 7 Hz. La
  entrada queda como está.
* **Audio con deénfasis (parlante): 10 nF**, corte en unos 700 Hz (entre 500 y
  900 Hz, según la dispersión de las resistencias internas). El deénfasis
  levanta todo lo que está por debajo de los tonos 6 dB por octava, así que una
  salida de parlante trae graves muy por encima de los tonos; a través de un
  capacitor grande esos graves ocupan el rango del conversor y dejan los tonos
  apenas unas cuentas por encima del propio ruido del ADC, algo que el
  pasa-altos de la página Radiomodem no puede recuperar porque actúa después
  del conversor. Delante del ADC el capacitor de 10 nF los elimina, y a la vez
  quita 1,3 dB al tono de marca de 1200 Hz y 0,4 dB al de espacio de 2200 Hz,
  un poco del realce del tono de espacio que necesita el audio con deénfasis.
  Use uno cerámico o de película: no tiene polaridad.

Un capacitor de 100 nF pone el corte en unos 70 Hz, que conserva los graves y
por lo tanto se comporta como el de 1 µF.

Use trimmers de 10 kΩ: del lado de
transmisión mantienen liviana la carga sobre la salida del DAC, y la
atenuación necesaria deja el cursor cerca del 1,4 % del recorrido, así que un
trimmer multivuelta es lo que lo hace ajustable.

Ajuste los niveles con los dos botones junto a PRUEBA DE BUCLE, que es lo que
el loop test no puede hacer una vez que un equipo reemplaza el puente:
**NIVEL RX** mide sin transmitir — apunte al veredicto **bueno**, un nivel de
la banda de tonos de al menos 20 mV RMS (con una entrada plana, 250 a 350 mV RMS
de banda ancha es un nivel cómodo), con el rango crudo bien lejos de 0 y 4095, y con la polarización interna activada espere un
offset de continua entre 1200 y 2000 mV — y **PRUEBA TX** activa el
transmisor para poder leer la desviación en otro instrumento y ajustarla a
2,5 a 3,5 kHz.

.. warning::

   Sin D1/D2, el trimmer de recepción es lo único que limita la corriente
   hacia el pin del ADC. La salida de altavoz de un portátil a todo volumen
   queda muy fuera de 0 a 3,3 V, así que baje el volumen antes de conectar y
   nunca lleve la salida de altavoz a GPIO33 solo a través del capacitor.

Baofeng UV-5R y HT de conector K
--------------------------------

El UV-5R (y los clones de dos pines estilo Kenwood-K1: UV-82, BF-888, GT-3,
RT-5R…) expone dos conectores en lugar de una toma combinada:

.. list-table::
   :header-rows: 1
   :widths: 22 22 56

   * - Conector
     - Tamaño
     - Señal
   * - Grande
     - 3,5 mm TS
     - Punta = salida de audio SPKR, Manguito = GND
   * - Pequeño
     - 2,5 mm TRS
     - Punta = MIC in, Anillo = PTT (cortocircuitar a manguito para transmitir),
       Manguito = GND

**No hay circuito específico para el UV-5R** — construye el esquema mínimo tal
cual; solo cambia dónde aterrizan los tres cables externos, porque el equipo
divide la "radio" en dos conectores. Estos HT **no tienen toma de
discriminador**, así que el 9600 Bd G3RUH queda fuera de alcance; **AFSK 1200 Bd
Bell 202 es el techo realista** por el conector de 2 pines de serie. Verifica el
pinout del conector con un polímetro antes de soldar — los cables de terceros
baratos a veces intercambian mic y PTT.

Orden de puesta en marcha
=========================

#. **Primero el test de bucle, sin radio.** Cablea GPIO25 → GPIO33 con un cable
   simple (véase :ref:`es-web-admin` y el LOOP TEST). Si eso falla, ningún
   circuito externo ayudará.
#. **Luego el RX, aún sin TX.** Abre el squelch, inyecta tráfico real y observa
   la columna **AUDIO** de la tabla de tráfico en vivo (los mVrms del propio
   módem en el pin). Ajusta RV2 para **≈300 mVrms en los paquetes** — el
   objetivo del AGC, donde el lazo queda en la unidad con el máximo margen.
#. **Por último el TX, sobre una carga fantasma.** Ajusta RV1 para **≈3,0 kHz de
   desviación** (2,5–3,5 kHz). La sobredesviación es la causa más común de "mi
   igate escucha a todos pero nadie me escucha a mí".
#. **9600 Bd G3RUH** necesita la ruta plana/de discriminador en ambos extremos:
   DATA IN/DATA OUT, 10 nF en C2/C3, y la casilla *Entrada de audio plana / de
   discriminador* marcada.

Aislamiento y bucles de tierra
==============================

El circuito pasivo comparte tierra con la radio, la fuente habitual de zumbido,
ruido del alternador y "funciona hasta que transmito". Si oyes algo de eso, usa
transformadores de aislamiento de audio 600:600 Ω en lugar de C1 y C4, mantén el
opto (opción A) para que el retorno de PTT no recree la tierra que acabas de
romper, y combate la entrada de RF con cable apantallado, cables cortos, una
ferrita de pinza en el conector del equipo y 47–100 pF de cada línea de audio al
chasis de la radio.

.. _es-loop-test-tuning:

Procedimiento de ajuste
=========================

Puntos de referencia
----------------------

.. list-table::
   :header-rows: 1
   :widths: 34 20 46

   * - Señal
     - GPIO
     - Función
   * - DAC (salida de audio TX)
     - GPIO25
     - Audio de transmisión AFSK
   * - ADC (entrada de audio RX)
     - GPIO33
     - Audio de recepción AFSK
   * - Salida PTT
     - GPIO26
     - Conmutación del equipo de radio

.. list-table::
   :header-rows: 1
   :widths: 12 12 30 46

   * - Trimmer
     - Valor
     - Ubicación
     - Función
   * - **RV1**
     - 1 kΩ
     - Entre el DAC y el terminal de salida ``MIC`` de la interfaz
     - **Nivel de audio TX** — ajusta la fuerza de excitación hacia la
       entrada de micrófono/audio del equipo de radio
   * - **RV2**
     - 10 kΩ
     - Entre el terminal de entrada ``SPKR`` de la interfaz y el ADC
     - **Nivel de audio RX** — atenúa la salida de altavoz/audio del equipo
       de radio hasta el nivel que espera el ADC

1. Método A — Prueba de bucle del módem sin interfaz
--------------------------------------------------------

Úsalo para verificar de forma aislada la propia cadena DAC/ADC/AX.25 del
ESP32, antes de involucrar la placa de interfaz.

1.1 Esquema mínimo
^^^^^^^^^^^^^^^^^^^^

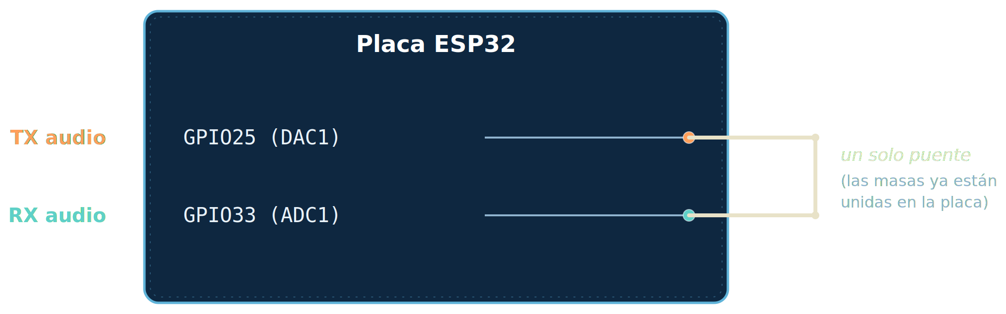
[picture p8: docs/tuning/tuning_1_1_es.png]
Esquema mínimo de bucle — GPIO25 (DAC1) puenteado a GPIO33 (ADC1) en la placa ESP32


Un solo puente, GPIO25 → GPIO33. Ambos pines son de 0–3,3 V asimétricos y
comparten el plano de masa de la placa, por lo que no hace falta ningún
condensador de acoplo ni atenuador para obtener un resultado apto/no apto.

1.2 Procedimiento
^^^^^^^^^^^^^^^^^^^

#. Cablea el puente como se indica arriba (apaga la alimentación primero).
#. Activa el módem de audio en la interfaz web (página Radio/Módem →
   "Habilitar módem ADC/DAC de audio" → Guardar → reiniciar).
#. Abre la consola serie para observar los resultados.
#. Ejecuta la autoprueba desde el botón **LOOP TEST** de la página
   Radio/Módem (o el endpoint web equivalente).
#. Lee la línea resultante ``PASS``/``FAIL``, que informa del nivel RX (mV
   RMS), la excursión bruta del ADC y la ganancia del AGC, además de — en
   caso de fallo — un diagnóstico específico por etapas.
#. Repite la prueba de 3 a 5 veces para descartar una conexión intermitente
   antes de sacar conclusiones.

1.3 Interpretación del resultado
^^^^^^^^^^^^^^^^^^^^^^^^^^^^^^^^^^

.. list-table::
   :header-rows: 1
   :widths: 34 66

   * - Resultado
     - Significado
   * - ``PASS``
     - La cadena completa TX→RX→HDLC→CRC funciona correctamente
   * - ``FAIL``, el ADC nunca muestreó
     - Problema del controlador/inicialización del ADC, no del puente
   * - ``FAIL``, línea plana / casi continua
     - No llega señal al ADC — revisa el puente y las masas
   * - ``FAIL``, hay señal pero no hay enganche
     - El tono llega al ADC, pero el PLL del demodulador nunca se sincroniza
       — revisa la ganancia del AGC (los puntos cercanos a 1,0× indican la
       ruta del AGC) o el ajuste de velocidad en baudios/tipo de módem
   * - ``FAIL``, PLL enganchado, sin trama (etapa < FRAME)
     - La sincronización de bits nunca inicia una trama — problema más
       profundo de recuperación de bits
   * - ``FAIL``, PLL enganchado, sin trama (etapa = FRAME)
     - El encuadre funciona pero falla el CRC — señal marginal o recorte
   * - ``FAIL``, contenido no coincide
     - Se recibió la trama pero está corrupta — distorsión, recorte o un
       puente de bucle flojo

2. Método B — Bucle a través de la placa de interfaz (por RV1/RV2)
------------------------------------------------------------------------

Úsalo para validar — y ajustar — la propia placa de interfaz de audio,
incluidos ambos trimmers de nivel, sin ningún equipo de radio conectado.

2.1 Esquema mínimo
^^^^^^^^^^^^^^^^^^^^

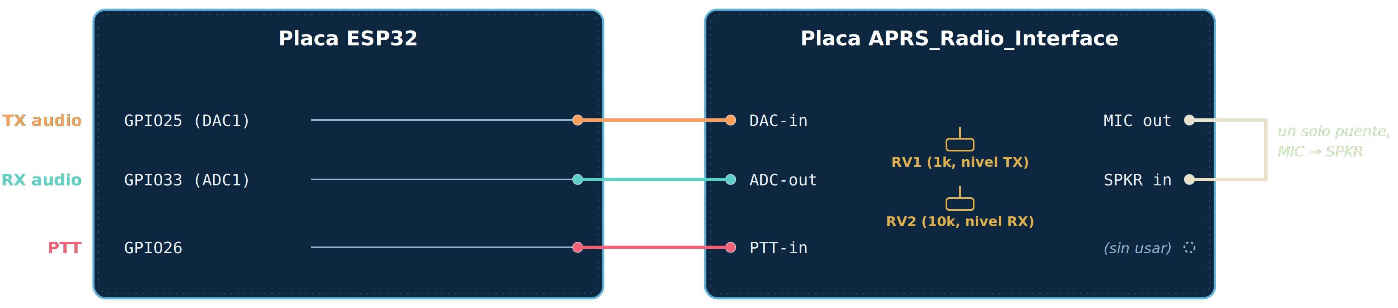
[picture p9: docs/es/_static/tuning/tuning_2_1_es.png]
Esquema mínimo de bucle por la placa de interfaz — ESP32 DAC/ADC/PTT conectados a la placa APRS_Radio_Interface, con un puente de MIC out a SPKR in


Cablea la placa de interfaz al ESP32 exactamente como en el funcionamiento
normal (DAC/ADC/PTT), y añade **un puente adicional en la propia placa de
interfaz, desde su terminal de salida** ``MIC`` **hasta su terminal de
entrada** ``SPKR``. No se conecta ningún equipo de radio. Esto cierra el
lazo a través de toda la cadena analógica — ambos trimmers, condensadores de
acoplo y redes de nivel.

2.2 Qué leer
^^^^^^^^^^^^^^

Cada ejecución de la autoprueba (§1.2, paso 4) informa ahora, tanto si pasa
como si falla:

* **Nivel RX**, en mV RMS
* **Excursión bruta del ADC** (mín-máx, sobre un rango de 12 bits, 0–4095) —
  el indicador de margen frente al recorte
* **Ganancia de pico del AGC**

Estos tres valores son los que sustituyen a una traza de osciloscopio a la
hora de ajustar los trimmers a continuación.

3. Procedimiento de ajuste de los trimmers (primero RV1, luego RV2)
--------------------------------------------------------------------------

Realiza esto con el bucle cableado como en el §2.1, ejecutando la autoprueba
después de cada ajuste.

#. **Empieza bajo.** Pon RV1 (nivel TX) cerca del mínimo y RV2 (nivel RX) a
   aproximadamente la mitad de su recorrido.
#. **Barre RV1 hacia arriba**, ejecutando la prueba en cada paso:

   * **Demasiado bajo:** ``FAIL`` — enganche del PLL débil o nulo, excursión
     bruta del ADC pequeña, RMS bajo.
   * **Demasiado alto:** la excursión bruta del ADC se acerca a los raíles
     (hacia 0 y/o 4095), provocando finalmente un fallo de contenido no
     coincidente o de CRC.
   * Anota el **rango de posiciones de RV1 que dan un** ``PASS`` **limpio**
     con la excursión claramente alejada de ambos raíles.

#. **Fija RV1 en el centro de ese rango válido** — no en un extremo — para
   tener el mismo margen frente a una conexión débil por un lado y frente al
   recorte por el otro.
#. **Con RV1 fijo, barre RV2** de la misma forma:

   * **Demasiado bajo:** RMS bajo, enganche DCD marginal o ausente.
   * **Demasiado alto:** la excursión se acerca a los raíles, fallos de
     distorsión/CRC.
   * Fija RV2 en el centro de su propio rango válido.

#. **Vuelve a verificar.** Ejecuta la autoprueba de 3 a 5 veces seguidas con
   los ajustes elegidos. Todas las ejecuciones deben dar ``PASS``, con la
   excursión manteniéndose alejada de ambos raíles y el RMS cómodamente por
   encima del umbral de "sin enganche" observado durante el barrido.
#. **Registra las posiciones finales** (por ejemplo, "RV1: 40% desde el
   mínimo, RV2: 55% desde el mínimo") para referencia futura, ya que los
   trimmers pueden desajustarse o recibir golpes.

No hace falta osciloscopio en ningún momento: las lecturas de
excursión/RMS/AGC de cada ejecución de la autoprueba lo sustituyen, y el
propio límite entre PASS y FAIL marca los bordes de la ventana utilizable de
cada trimmer.

Tabla de particiones
====================

El firmware distribuye una disposición de 4 MB con OTA habilitado
(``partitions.csv``):

.. list-table::
   :header-rows: 1
   :widths: 20 12 12 16 14 26

   * - Nombre
     - Tipo
     - SubTipo
     - Offset
     - Tamaño
     - Notas
   * - ``nvs``
     - data
     - nvs
     - 0x9000
     - 24 K
     -
   * - ``otadata``
     - data
     - ota
     - 0xF000
     - 8 K
     -
   * - ``phy_init``
     - data
     - phy
     - 0x11000
     - 4 K
     -
   * - ``ota_0``
     - app
     - ota_0
     - 0x20000
     - **1728 K**
     - primera ranura de app
   * - ``ota_1``
     - app
     - ota_1
     - 0x1D0000
     - **1728 K**
     - segunda ranura de app
   * - ``storage``
     - data
     - spiffs
     - 0x380000
     - **512 K**
     - montada como **LittleFS** en ``/storage``

Dos ranuras de app permiten que la actualización OTA de la administración web
grabe la ranura que no está en ejecución y revierta automáticamente si la nueva
imagen falla la autocomprobación posterior al arranque. Un dispositivo aún en la
antigua tabla de ``factory`` único necesita una regrabación por serie para migrar
a esta disposición; todas las actualizaciones posteriores pueden ir por la web.

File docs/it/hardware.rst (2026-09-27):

.. _it-hardware:

========
Hardware
========

Target supportato
=================

* **ESP32** (classico, Xtensa dual-core) — ``CONFIG_IDF_TARGET=esp32``, 4 MB
  di flash.
* Il dual-core **non è opzionale**: l'ISR dell'ADC e il clock di campionamento
  del DAC sono fissati su core *diversi* di proposito (vedi
  :ref:`it-dsp-signal-chain`).
* L'ESP32-S2 ha i DAC su GPIO17/18 e richiederebbe l'adattamento dell'header di
  configurazione. **ESP32-S3/C3/C6/H2 non hanno alcun DAC** e non possono
  eseguire il percorso TX senza modifiche.

Pinout / definizione di scheda
==============================

La definizione di scheda risiede nel ``CMakeLists.txt`` di **livello superiore**,
applicata *prima* di ``project()`` tramite ``idf_build_set_property(COMPILE_DEFINITIONS …
APPEND)``:

.. code-block:: cmake

   idf_build_set_property(COMPILE_DEFINITIONS "MODEM_ADC_GPIO=33"       APPEND)
   idf_build_set_property(COMPILE_DEFINITIONS "MODEM_DAC_GPIO=25"       APPEND)
   idf_build_set_property(COMPILE_DEFINITIONS "MODEM_PTT_GPIO=26"       APPEND)
   idf_build_set_property(COMPILE_DEFINITIONS "MODEM_PTT_ACTIVE_HIGH=1" APPEND)
   idf_build_set_property(COMPILE_DEFINITIONS "MODEM_LED_TX_GPIO=-1"    APPEND)
   idf_build_set_property(COMPILE_DEFINITIONS "MODEM_LED_RX_GPIO=-1"    APPEND)

.. list-table::
   :header-rows: 1
   :widths: 20 20 60

   * - Segnale
     - Predefinito
     - Vincoli assoluti
   * - **Ingresso audio (ADC)**
     - ``GPIO33`` (ADC1_CH5)
     - **Solo 32–39.** L'ADC2 è inutilizzabile mentre il Wi-Fi è attivo, e
       questo firmware ha sempre il Wi-Fi attivo. Imposto da un ``#error`` in
       compilazione.
   * - **Uscita audio (DAC)**
     - ``GPIO25`` (DAC_CHAN_0)
     - **Solo 25 o 26.** Il DAC dell'ESP32 è cablato in modo fisso a quei pad e
       non è instradabile attraverso la matrice GPIO. Imposto da ``#error``.
   * - **PTT**
     - ``GPIO26``
     - Qualsiasi GPIO capace di uscita diverso dai pin ADC/DAC; rifiuta i GPIO
       solo-ingresso 34–39 e i GPIO flash/PSRAM 6–11. ``-1`` lo disabilita.
       Sia il pin **sia la sua polarità** sono costanti di compilazione.
   * - **LED TX / RX**
     - disabilitati (``-1``)
     - Qualsiasi GPIO capace di uscita.
   * - **Ricezione GNSS (UART RX)**
     - ``GPIO16``
     - Cablato all'uscita TX del modulo. Qualsiasi GPIO capace di ingresso
       raggiungibile dalla matrice UART. **Inutilizzabile su un
       ESP32-WROVER**, dove i GPIO16/17 appartengono al die della PSRAM SPI.
       Impostato in ``main/include/gps.h``.
   * - **Trasmissione GNSS (UART TX)**
     - ``GPIO17``
     - Cablato all'ingresso RX del modulo. Non vi si invia mai nulla — il
       firmware non configura mai il ricevitore — ma il pin resta comunque
       riservato, perché è fisicamente collegato a quell'ingresso.

Cablaggio a una radio
=====================

Nessuna delle due estremità del collegamento audio può essere connessa
direttamente all'altra. Il lato ESP32 è un'interfaccia a 3,3 V, polarizzata in
DC, a dati campionati; il lato radio è un'interfaccia analogica in AC,
riferita a massa, a livello di millivolt. Tre cose devono avvenire in mezzo:
**attenuare** (TX), **traslare e limitare** (RX) e **commutare** (PTT).

Cosa presenta ciascuna estremità
--------------------------------

Ogni cifra del lato ESP32 qui sotto è derivata dalle costanti di compilazione
del componente modem stesso, non da un ideale da datasheet.

.. list-table::
   :header-rows: 1
   :widths: 26 50 24

   * - Nodo
     - Cosa c'è davvero
     - Da
   * - **GPIO25 (DAC), in trasmissione**
     - 1,65 V DC con un'oscillazione ≈1,97 Vpp sopra ⇒ ≈0,70 Vrms per una
       sinusoide, più immagini di ricostruzione intorno ai 38,4 kHz
     - ``DAC_MID=128``, ``AMPLITUDE_PCT=60``, ``DAC_SAMPLERATE=38400``
   * - **GPIO33 (ADC)**
     - Finestra 0–3,1 V; l'AGC punta a 310 mVrms al pin, la raggiunge da appena
       ≈39 mVrms, la mantiene sotto ≈3,3 mVrms, satura sopra ≈1,1 Vrms
     - ``ADC_ATTEN_DB_12``, ``AGC_TARGET_RMS=0.2``
   * - **MIC IN** dell'apparato
     - 5–20 mVrms, spesso pre-enfatizzato, bias DC per l'electret
     - richiede ≈30–40 dB di attenuazione
   * - **DATA IN** dell'apparato (mini-DIN-6)
     - ≈40 mVpp ⇒ ≈14 mVrms, piatto, senza pre-enfasi
     - richiede ≈35 dB di attenuazione
   * - **SPKR / AF OUT** dell'apparato
     - 0,1–3 Vrms, dipendente dalla manopola del volume, de-enfatizzato
     - richiede attenuazione + bias
   * - **DATA OUT / DISC** dell'apparato
     - 100–300 mVrms, livello fisso, indipendente dallo squelch, piatto
     - richiede solo bias — questa è quella buona

Due conseguenze da interiorizzare prima di saldare:

* **Il DAC è ~35 dB troppo forte** per qualsiasi cosa sulla radio. Una
  connessione diretta non solo sovra-devia, ma spruzza.
* **Una porta DATA OUT è già dentro la finestra dell'AGC** (100–300 mVrms
  contro il range utile 39 mVrms–1,1 Vrms). Se il tuo apparato ha un jack dati,
  il lato RX è una rete di bias e niente altro — nessun potenziometro, nessun
  guadagno.

Schema funzionale minimo
------------------------

Passivo, ~15 parti, senza amplificatori operazionali.

Schema TX — DAC dell'ESP32 verso l'ingresso audio dell'apparato

Schema RX — uscita audio dell'apparato verso l'ADC dell'ESP32

Schema PTT, opzione A — optoisolatore (PC817), isolato

Schema PTT, opzione B — transistor NPN (2N2222/BC547), non isolato

Ruoli chiave dei componenti: R1/R2 + C2/C3 formano un passa-basso di
ricostruzione a due poli (fc ≈ 4,8 kHz) che elimina le immagini del DAC a
38,4 kHz; C1 blocca il bias di riposo a 1,65 V del DAC dall'ingresso microfono;
R3/RV1 attenuano e regolano il livello TX; R5/R6 impostano un bias a metà
raglio di 1,65 V per l'ADC; R7/C5 smorza il colpo di carica del condensatore di
campionamento SAR; D1/D2 limitano il pin dell'ADC ai rail. Per **9600 Bd
G3RUH** sostituisci C2/C3 con 10 nF (fc ≈ 7,2 kHz) per mantenere l'audio piatto
oltre i ~5 kHz.

.. warning::

   **Il predefinito del PTT è una trappola.** La definizione di scheda fornita
   è ``MODEM_PTT_ACTIVE_HIGH=1`` in questa revisione. Scegli un driver di PTT la
   cui polarità corrisponda alla configurazione, o cambia la configurazione per
   corrispondere al tuo driver. Un opto (opzione A) inverte e si adatta a
   ``ACTIVE_HIGH=0``; un semplice interruttore NPN low-side (opzione B) non
   inverte e richiede ``ACTIVE_HIGH=1``. Verifica sempre con un multimetro che la
   linea PTT sia *aperta* durante il reset, per tutto l'avvio di ~5 s, e mentre è
   in riposo **prima di connettere la radio** — ``modem_init()`` si blocca ~5 s
   calibrando il clock dell'ADC e i beacon trasmettono all'ingresso, quindi un
   PTT di polarità errata ti dà secondi di portante non modulata. Il firmware
   porta il pin PTT al livello di riposo come primo passo di ``app_main()``.
   Prima di allora — durante la ROM e il bootloader di secondo stadio, circa
   0,3–0,5 s dopo ogni reset (pin EN, brownout, OTA o riavvio remoto) — il pin è
   un ingresso non configurato e senza pull, e solo la polarizzazione propria
   dello stadio di commutazione sul suo ingresso di controllo tiene la radio non
   in trasmissione.

Interfaccia ridotta: un condensatore e un trimmer per direzione
----------------------------------------------------------------

Lo schema qui sopra è la versione di riferimento. È supportata anche
un'interfaccia ridotta, che non porta altro che un condensatore di
accoppiamento e un trimmer di livello in ciascuna direzione audio, con il PTT
invariato. Quello che facevano le parti rimosse viene assunto da
un'impostazione della pagina Radiomodem oppure accettato come limite:

.. list-table::
   :header-rows: 1
   :widths: 30 70

   * - Rimosso
     - Sostituzione
   * - R5/R6 (polarizzazione dell'ADC)
     - **Polarizzazione interna dell'ingresso ADC**, che collega in serie il
       pull-up e il pull-down del pad stesso
   * - R3 (attenuatore di TX)
     - il solo trimmer, eventualmente con l'**Ampiezza di uscita in
       trasmissione** ridotta per distribuirne la corsa utile
   * - R1/R2 + C2/C3 (filtro di ricostruzione)
     - **Frequenza di campionamento in trasmissione** a 76800 Hz, che sposta
       le immagini di un'ottava
   * - D1/D2 (clamp di ingresso)
     - niente: **Avvisa quando l'audio ricevuto esce dal fondo scala** segnala
       la condizione e il trimmer di ricezione è ciò che limita la corrente di
       guasto
   * - R7/C5 (snubber dell'ADC)
     - niente; è da attendersi un po' più di rumore

Cablaggio, per direzione: il trimmer di trasmissione è un partitore fra GPIO25
e massa con il cursore che alimenta il condensatore di accoppiamento, e il
trimmer di ricezione è un partitore sull'uscita altoparlante dell'apparato con
il cursore che alimenta l'altro condensatore. **Il condensatore va dopo il
trimmer su entrambi i lati.** Prima di esso la gamba inferiore del trimmer
porterebbe a massa il pin dell'ADC, vanificando la polarizzazione interna, e
sul lato trasmissione affosserebbe la polarizzazione propria dell'ingresso
microfonico.

Il condensatore di trasmissione deve essere da 1 µF o più. Quello di
ricezione forma un passa-alto del primo ordine con le resistenze
dell'autopolarizzazione (circa 22 kΩ tra il pull-up e il pull-down del pad,
che variano da un esemplare all'altro), e il suo valore dipende dall'audio
fornito dall'apparato:

* **Audio piatto (discriminatore / dati): 1 µF o più**, taglio a circa 7 Hz.
  L'ingresso resta com'è.
* **Audio de-enfatizzato (altoparlante): 10 nF**, taglio a circa 700 Hz (tra
  500 e 900 Hz secondo la dispersione delle resistenze interne). La de-enfasi
  solleva tutto ciò che sta sotto i toni di 6 dB per ottava, quindi un'uscita
  altoparlante porta bassi ben sopra i toni; attraverso un condensatore grande
  quei bassi occupano la gamma del convertitore e lasciano i toni appena
  qualche conteggio sopra il rumore proprio dell'ADC, cosa che il passa-alto
  della pagina Radiomodem non può recuperare perché agisce dopo il
  convertitore. Davanti all'ADC il condensatore da 10 nF li elimina, e insieme
  toglie 1,3 dB al tono di mark a 1200 Hz e 0,4 dB a quello di space a
  2200 Hz, un po' dell'esaltazione del tono di space di cui l'audio
  de-enfatizzato ha bisogno. Usare un condensatore ceramico o a film: non ha
  polarità.

Un condensatore da 100 nF porta il taglio a circa 70 Hz, che conserva i bassi
e quindi si comporta come quello da 1 µF.

Usare trimmer da 10 kΩ: sul lato
trasmissione mantengono leggero il carico sull'uscita del DAC, e
l'attenuazione necessaria porta il cursore intorno all'1,4 % della corsa, per
cui è un trimmer multigiro a renderlo regolabile.

Regolare i livelli con i due pulsanti accanto a TEST LOOP, che è ciò che il
loop test non può fare una volta che un apparato ha sostituito il ponticello:
**LIVELLO RX** misura senza trasmettere — puntare al verdetto **buono**, un
livello della banda dei toni di almeno 20 mV RMS (con un ingresso piatto,
250-350 mV RMS a banda larga è un livello comodo), con la gamma grezza ben lontana da 0 e
4095, e con la polarizzazione interna attiva
aspettarsi un offset di continua fra 1200 e 2000 mV — e **TEST TX** manda in
trasmissione per poter leggere la deviazione su altra strumentazione e
regolarla a 2,5-3,5 kHz.

.. warning::

   Senza D1/D2 il trimmer di ricezione è l'unica cosa che limita la corrente
   verso il pin dell'ADC. L'uscita altoparlante di un portatile a tutto volume
   è ben fuori da 0-3,3 V, quindi abbassare il volume prima di collegare e non
   portare mai l'uscita altoparlante a GPIO33 con il solo condensatore.

Baofeng UV-5R e HT con connettore K
-----------------------------------

L'UV-5R (e i cloni a due pin stile Kenwood-K1: UV-82, BF-888, GT-3, RT-5R…)
espone due spine invece di un jack combinato:

.. list-table::
   :header-rows: 1
   :widths: 22 22 56

   * - Spina
     - Dimensione
     - Segnale
   * - Grande
     - 3,5 mm TS
     - Punta = uscita audio SPKR, Manica = GND
   * - Piccola
     - 2,5 mm TRS
     - Punta = MIC in, Anello = PTT (cortocircuita alla manica per attivare),
       Manica = GND

**Non esiste un circuito UV-5R separato** — costruisci lo schema minimo
esattamente come sopra; cambia solo dove atterrano i tre fili fuori scheda,
perché l'apparato divide "rig" su due spine. Nota che questi HT **non hanno un
jack discriminatore**, quindi 9600 Bd G3RUH è irraggiungibile; **AFSK 1200 Bd
Bell 202 è il tetto realistico** attraverso il connettore a 2 pin di serie.
Verifica il pinout della spina con un multimetro prima di saldare — i cavi
economici aftermarket a volte scambiano mic e PTT.

Ordine di messa in funzione
===========================

#. **Prima il loop test, senza radio.** Cabla GPIO25 → GPIO33 con un semplice
   filo (vedi :ref:`it-web-admin` e il LOOP TEST). Se questo fallisce, nessun
   circuito esterno aiuterà.
#. **Poi RX, ancora senza TX.** Apri lo squelch, immetti traffico reale, e
   osserva la colonna **AUDIO** della tabella di traffico in tempo reale (i
   mVrms del modem stesso al pin). Regola RV2 per **≈300 mVrms sui pacchetti** —
   il target dell'AGC, dove il loop si trova all'unità con il massimo margine.
#. **TX per ultimo, su un carico fittizio.** Imposta RV1 per **≈3,0 kHz di
   deviazione** (2,5–3,5 kHz). La sovra-deviazione è la causa singola più comune
   di "il mio igate sente tutti ma nessuno sente me".
#. **9600 Bd G3RUH** richiede il percorso piatto/discriminatore a entrambe le
   estremità: DATA IN/DATA OUT, 10 nF in C2/C3, e la casella *Ingresso audio
   piatto / da discriminatore* spuntata.

Isolamento e loop di massa
==========================

Il circuito passivo condivide una massa con la radio, la normale fonte di ronzio,
sibilo dell'alternatore e "funziona finché non trasmetto". Se senti qualcosa di
tutto ciò, usa trasformatori di isolamento audio 600:600 Ω al posto di C1 e C4,
mantieni l'opto (opzione A) così che il ritorno del PTT non ricrei la massa che
hai appena spezzato, e combatti l'ingresso RF con cavo schermato, fili corti, una
ferrite a clip sul connettore dell'apparato e 47–100 pF da ciascuna linea audio
al telaio dell'apparato.

.. _it-loop-test-tuning:

Procedura di taratura
=======================

Punti di riferimento
----------------------

.. list-table::
   :header-rows: 1
   :widths: 34 20 46

   * - Segnale
     - GPIO
     - Funzione
   * - DAC (uscita audio TX)
     - GPIO25
     - Audio di trasmissione AFSK
   * - ADC (ingresso audio RX)
     - GPIO33
     - Audio di ricezione AFSK
   * - Uscita PTT
     - GPIO26
     - Commutazione dell'apparato radio

.. list-table::
   :header-rows: 1
   :widths: 12 12 30 46

   * - Trimmer
     - Valore
     - Posizione
     - Funzione
   * - **RV1**
     - 1 kΩ
     - Tra il DAC e il terminale di uscita ``MIC`` dell'interfaccia
     - **Livello audio TX** — imposta la forza di pilotaggio verso
       l'ingresso microfono/audio dell'apparato radio
   * - **RV2**
     - 10 kΩ
     - Tra il terminale di ingresso ``SPKR`` dell'interfaccia e l'ADC
     - **Livello audio RX** — attenua l'uscita altoparlante/audio
       dell'apparato radio fino al livello atteso dall'ADC

1. Metodo A — Test in loopback del solo modem
------------------------------------------------

Usalo per verificare in isolamento la catena DAC/ADC/AX.25 propria
dell'ESP32, prima di coinvolgere la scheda di interfaccia.

1.1 Schema minimo
^^^^^^^^^^^^^^^^^^^

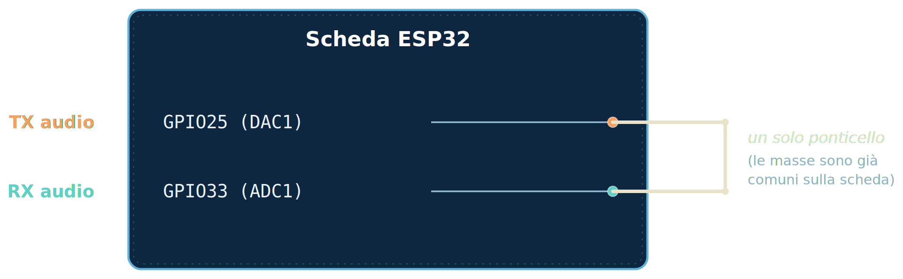
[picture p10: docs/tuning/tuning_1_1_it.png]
Schema minimo di loopback — GPIO25 (DAC1) ponticellato a GPIO33 (ADC1) sulla scheda ESP32


Un solo ponticello, GPIO25 → GPIO33. Entrambi i pin sono a 0–3,3 V
sbilanciati e condividono il piano di massa della scheda, quindi non serve
alcun condensatore di accoppiamento o attenuatore per ottenere un risultato
superato/non superato.

1.2 Procedura
^^^^^^^^^^^^^^

#. Cabla il ponticello come sopra (spegni l'alimentazione prima).
#. Abilita il modem audio nell'interfaccia web (pagina Radio/Modem →
   "Abilita modem ADC/DAC audio" → Salva → riavvia).
#. Apri la console seriale per osservare i risultati.
#. Esegui l'autotest dal pulsante **LOOP TEST** della pagina Radio/Modem (o
   dall'endpoint web equivalente).
#. Leggi la riga ``PASS``/``FAIL`` risultante, che riporta il livello RX (mV
   RMS), l'escursione grezza dell'ADC e il guadagno AGC, più — in caso di
   fallimento — una diagnosi specifica per fasi.
#. Ripeti 3-5 volte per escludere una connessione intermittente prima di
   trarre conclusioni.

1.3 Interpretazione del risultato
^^^^^^^^^^^^^^^^^^^^^^^^^^^^^^^^^^^

.. list-table::
   :header-rows: 1
   :widths: 34 66

   * - Risultato
     - Significato
   * - ``PASS``
     - L'intero percorso TX→RX→HDLC→CRC è funzionalmente corretto
   * - ``FAIL``, l'ADC non ha mai campionato
     - Problema del driver/inizializzazione dell'ADC, non del ponticello
   * - ``FAIL``, linea piatta / quasi continua
     - Nessun segnale raggiunge l'ADC — controlla il ponticello e le masse
   * - ``FAIL``, segnale presente ma nessun aggancio
     - Il tono raggiunge l'ADC ma il PLL del demodulatore non si sincronizza
       mai — controlla il guadagno AGC (i punti vicini a 1,0× indicano il
       percorso dell'AGC) o l'impostazione di velocità in baud/tipo di modem
   * - ``FAIL``, PLL agganciato, nessuna trama (fase < FRAME)
     - La sincronizzazione dei bit non avvia mai una trama — problema più
       profondo di recupero dei bit
   * - ``FAIL``, PLL agganciato, nessuna trama (fase = FRAME)
     - Il framing funziona ma il CRC fallisce — segnale marginale o clipping
   * - ``FAIL``, contenuto non corrispondente
     - Trama ricevuta ma corrotta — distorsione, clipping o un ponticello di
       loopback allentato

2. Metodo B — Loopback attraverso la scheda di interfaccia (via RV1/RV2)
------------------------------------------------------------------------------

Usalo per validare — e tarare — la scheda di interfaccia audio vera e
propria, inclusi entrambi i trimmer di livello, senza alcun apparato radio
collegato.

2.1 Schema minimo
^^^^^^^^^^^^^^^^^^^

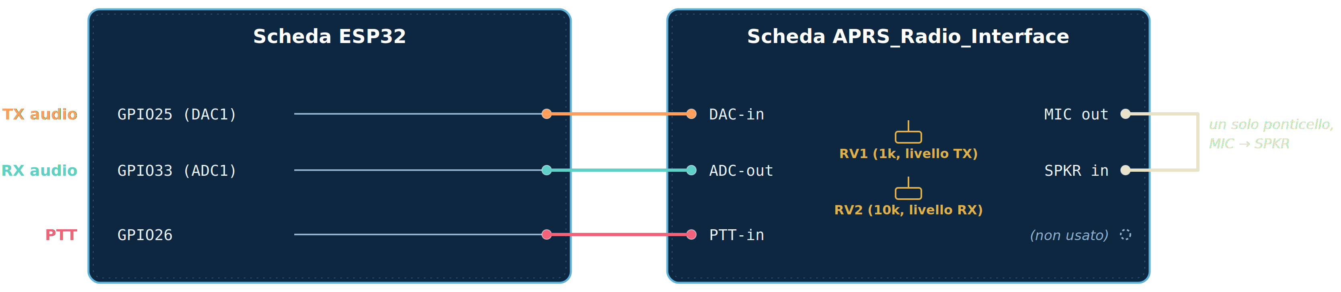
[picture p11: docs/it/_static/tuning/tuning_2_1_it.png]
Schema minimo di loopback tramite la scheda di interfaccia — DAC/ADC/PTT dell'ESP32 collegati alla scheda APRS_Radio_Interface, con un ponticello da MIC out a SPKR in


Cabla la scheda di interfaccia all'ESP32 esattamente come per il
funzionamento normale (DAC/ADC/PTT), poi aggiungi **un ponticello
aggiuntivo sulla scheda di interfaccia stessa, dal suo terminale di uscita**
``MIC`` **al suo terminale di ingresso** ``SPKR``. Nessun apparato radio è
collegato. Questo chiude l'anello attraverso l'intera catena analogica —
entrambi i trimmer, i condensatori di accoppiamento e le reti di livello.

2.2 Cosa leggere
^^^^^^^^^^^^^^^^^^

Ogni esecuzione dell'autotest (§1.2, punto 4) ora riporta, sia che superi
il test sia che fallisca:

* **Livello RX**, in mV RMS
* **Escursione grezza dell'ADC** (min-max, su un intervallo a 12 bit,
  0–4095) — l'indicatore del margine dal clipping
* **Guadagno di picco dell'AGC**

Questi tre valori sostituiscono una traccia dell'oscilloscopio quando si
tarano i trimmer descritti di seguito.

3. Procedura di taratura dei trimmer (prima RV1, poi RV2)
---------------------------------------------------------------

Esegui questa procedura con l'anello cablato come al §2.1, eseguendo
l'autotest dopo ogni regolazione.

#. **Parti dal basso.** Porta RV1 (livello TX) vicino al minimo e RV2
   (livello RX) a circa metà corsa.
#. **Scorri RV1 verso l'alto**, eseguendo il test a ogni passo:

   * **Troppo basso:** ``FAIL`` — aggancio del PLL debole o assente,
     escursione grezza dell'ADC ridotta, RMS basso.
   * **Troppo alto:** l'escursione grezza dell'ADC si avvicina ai binari
     (verso 0 e/o 4095), causando infine un fallimento di contenuto non
     corrispondente o di CRC.
   * Annota l'**intervallo di posizioni di RV1 che dà un** ``PASS`` **pulito**
     con l'escursione chiaramente lontana da entrambi i binari.

#. **Fissa RV1 al centro di quell'intervallo valido** — non a un estremo —
   in modo da avere lo stesso margine sia contro una connessione debole sia
   contro il clipping.
#. **Con RV1 fisso, scorri RV2** allo stesso modo:

   * **Troppo basso:** RMS debole, aggancio DCD marginale o assente.
   * **Troppo alto:** l'escursione si avvicina ai binari, fallimenti di
     distorsione/CRC.
   * Fissa RV2 al centro del suo intervallo valido.

#. **Riverifica.** Esegui l'autotest 3-5 volte di seguito con le
   impostazioni scelte. Tutte le esecuzioni dovrebbero dare ``PASS``, con
   l'escursione che resta lontana da entrambi i binari e l'RMS ben al di
   sopra della soglia di "nessun aggancio" osservata durante la scansione.
#. **Registra le posizioni finali** (ad es. "RV1: 40% dal minimo, RV2: 55%
   dal minimo") per riferimento futuro, poiché i trimmer possono spostarsi o
   subire urti.

Non serve mai un oscilloscopio: le letture di escursione/RMS/AGC di ogni
esecuzione dell'autotest lo sostituiscono, e il confine stesso tra PASS e
FAIL segna i bordi della finestra utilizzabile di ciascun trimmer.

Tabella delle partizioni
========================

Il firmware distribuisce un layout da 4 MB abilitato all'OTA (``partitions.csv``):

.. list-table::
   :header-rows: 1
   :widths: 20 12 12 16 14 26

   * - Nome
     - Tipo
     - SubType
     - Offset
     - Dimensione
     - Note
   * - ``nvs``
     - data
     - nvs
     - 0x9000
     - 24 K
     -
   * - ``otadata``
     - data
     - ota
     - 0xF000
     - 8 K
     -
   * - ``phy_init``
     - data
     - phy
     - 0x11000
     - 4 K
     -
   * - ``ota_0``
     - app
     - ota_0
     - 0x20000
     - **1728 K**
     - primo slot app
   * - ``ota_1``
     - app
     - ota_1
     - 0x1D0000
     - **1728 K**
     - secondo slot app
   * - ``storage``
     - data
     - spiffs
     - 0x380000
     - **512 K**
     - montata come **LittleFS** su ``/storage``

Due slot app permettono all'OTA dell'amministrazione web di scrivere lo slot che
non è attualmente in esecuzione e di eseguire il rollback automaticamente se la
nuova immagine fallisce l'autotest post-avvio. Un dispositivo ancora sulla vecchia
tabella a singolo ``factory`` necessita di una riscrittura seriale per migrare a
questo layout; ogni aggiornamento successivo può passare per l'amministrazione
web.

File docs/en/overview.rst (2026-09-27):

.. _en-overview:

========
Overview
========

What this is
============

``esp32idf_APRS`` is an ESP-IDF **v6.x** project (tested and locked at IDF
**6.1**) that turns a bare ESP32 DevKit plus a cheap audio interface into a
complete, self-contained APRS station. Everything runs on the ESP32 itself —
there is no Arduino core, no ``String``, no PlatformIO, and no external DSP
library. The whole signal chain, from the correlator demodulator through the
DPLL bit recovery, NRZI, HDLC framer, AX.25 codec and Reed–Solomon FX.25
forward-error-correction, executes on the microcontroller using only the
SAR-ADC in continuous/DMA mode, the DAC, and a general-purpose timer.

In one sentence: the firmware

* **demodulates** AFSK/FSK audio from a radio's speaker or discriminator
  output on **ADC1**,
* **decodes** HDLC/AX.25 (optionally FX.25 forward-error-corrected) frames,
* **gates** them to APRS-IS over Wi-Fi (``qAR``/``qAO``),
* **digipeats** them back on RF (WIDEn-N, via an operator-configurable alias
  table),
* **beacons** its own position, weather and telemetry,
* **modulates** and transmits frames back out through the ESP32's **8-bit
  DAC**, keying the radio via a PTT GPIO,
* and is configured entirely through an **HTTP web admin** served by the
  device itself — no serial console, no recompilation for ordinary settings.

Feature matrix
==============

.. list-table::
   :header-rows: 1
   :widths: 40 12 48

   * - Area
     - Status
     - Notes
   * - AFSK 1200 Bd Bell 202 (standard APRS)
     - ✅
     - up to three parallel demodulators, default profile
   * - AFSK 1200 Bd ITU V.23 (1300/2100 Hz)
     - ✅
     -
   * - AFSK 300 Bd (1600/1800 Hz)
     - ✅
     - HF-style
   * - G3RUH FSK 9600 Bd
     - ✅
     - needs flat/discriminator audio
   * - HDLC / AX.25 UI frame RX+TX
     - ✅
     - ``AX25_FRAME_MAX_SIZE = 329``
   * - FX.25 (RS FEC over AX.25)
     - ✅
     - RX-only / RX+TX modes
   * - PTT keying (compile-time GPIO + polarity)
     - ✅
     - validated GPIO; runtime **minimum-unkey** hold time
   * - CSMA / TX time-slot / p-persistence / TXDelay preamble / TXTail
     - ✅
     - ``preamble``, ``tx_tail``, ``tx_timeslot``, ``csma_persist``, ``csma_slot_ms``,
       ``csma_busy_max_s``
   * - DCD (data carrier detect)
     - ✅
     - demodulator-derived; no hardware squelch input
   * - APRS-IS IGate RF→INET
     - ✅
     - filters, dedup, ``qAR``/``qAO``
   * - APRS-IS IGate INET→RF
     - ✅
     - payload-type gating + budlist + third-party unwrap opt-in
   * - BrandMeister APRS interconnect (no DMR link)
     - ✅
     - recognition, gating and message routing over the existing APRS-IS
       session; own page, off by default
   * - Local RF→INET range gate & prefix gate
     - ✅
     - haversine distance + callsign-prefix whitelist
   * - Callsign whitelist / blacklist (budlist)
     - ✅
     - per-direction, composes (AND) with the type filters
   * - Satellite/ISS digipeater gate-call list
     - ✅
     - up to 8 entries, web-configurable (IGate page), no rebuild needed
   * - Duplicate-suppression switch, cache size & window
     - ✅
     - web-configurable (IGate page), shared by IGate and Digipeater
   * - Digipeater
     - ✅
     - WIDEn-N via a configurable alias table, dup-suppression; legacy
       ``RELAY``/``ECHO``/``GATE``/``TRACEn-N`` aliases are not built in but
       can be added as ordinary alias rows
   * - Own-station APRS Objects / Items
     - ✅
     - up to 5, RF and/or INET, interval decay + kill-repeats
   * - APRS bulletins (BLN1..BLN5)
     - ✅
     - up to 5, RF and/or INET, per-bulletin expiry
   * - APRS message chat UI (``/msgchat``)
     - ✅
     - inbox/compose page over the messaging engine
   * - APRS query responder (APRS101 ch.15)
     - ✅
     - general ``?APRS?``/``?WX?``/``?IGATE?``/``?QRU?`` + the directed set
       (``?APRSD``/``?APRSH``/``?APRSM``/``?APRSO``/``?APRSP``/``?APRSS``/
       ``?APRST``/``?PING?``), per-type and per-source rate limits
   * - Fixed-position beacons (tracker / igate / digi)
     - ✅
     - one shared beacon-scheduler task
   * - NMEA GNSS receiver (own UART) + live view page
     - ✅
     - master switch; RMC/GGA/GSA/GSV/VTG, multi-constellation, 1 Hz web view
   * - Live GPS tracking + SmartBeaconing
     - ✅
     - Tracker beacon only; speed-adaptive interval and corner-pegging
   * - APRS messaging + ack/retry
     - ✅
     - RF and/or INET
   * - Web admin (HTTP Basic auth)
     - ✅
     - 22 sidebar pages + symbol picker, live dashboard; administrator and
       optional read-only accounts
   * - Live traffic log (dashboard) + last-heard feed
     - ✅
     - traffic table by JSON long-poll (``?since=<seq>``); the per-station
       last-heard table is a JSON feed (``/lastheard``) and the source the
       message gate and the ``?APRSD``/``?APRSH`` answers read
   * - LittleFS storage, upload/download/delete/format
     - ✅
     - 512 KB partition
   * - SNTP time sync (3 hosts)
     - ✅
     - clock always kept in UTC
   * - CPU frequency control (80/160/240 MHz)
     - ✅
     - ``esp_pm_configure()``
   * - Wi-Fi AP / STA / AP+STA, scan, TX power
     - ✅
     - 5 STA slots (first enabled one is used)
   * - Localization (EN / ES / IT)
     - ✅
     - compile-time, one language per image
   * - OTA update
     - ✅
     - ``ota_0``/``ota_1`` slots, auto-rollback on boot failure
   * - Own-station APRS Weather Report
     - ✅
     - 1 Hz sensor refresh, optional averaging, on-air WX beacon
   * - Local sensor driver framework (``sensors_local``)
     - ✅
     - dynamic run-time registry, auto-registering drivers
   * - APRS Telemetry on-air encode/beacon
     - ✅
     - analog A1–A5 + digital B1–B8, ``T#nnn`` report + metadata
   * - Winlink radio e-mail (APRSLink)
     - ✅
     - own ``CALLSIGN@winlink.org`` mailbox over ``WLNK-1``, plus an optional
       gateway for a neighbouring station's own session; own page, off by
       default
   * - Telegram bot bridge
     - ✅
     - optional; long polling over HTTPS, per-user and per-chat authorization,
       station-message and bulletin routing, ``/status`` and ``/sensors``
       answers; own page and own settings file, off by default
   * - Console log viewer
     - ✅
     - on-demand mirror of the serial console into the browser (Logs page), no
       cable and nothing written to flash

Design philosophy
=================

Several deliberate architectural decisions recur throughout the codebase and
are worth internalising up front:

**One resident configuration, one live copy.**
   A single ``app_config_t g_config`` instance is the source of truth every
   subsystem reads. It persists to one file per web-admin functionality under
   ``/storage``. Subsystems never
   duplicate configuration state; they read ``g_config`` directly. The
   subsystems that need larger, page-specific state of their own keep it in
   separate LittleFS files instead of bloating ``g_config``: telemetry
   (``/storage/telemetry.json``), bulletins (``/storage/bulletins.json``),
   objects/items (``/storage/objitems.json``), the Telegram bot
   (``/storage/telegram.json``, which holds that page's whole configuration)
   and the Winlink mailbox (``/storage/winlink.json``, the replies the service
   has sent back).

**Compile-time board wiring, runtime everything-else.**
   The three audio pins (ADC, DAC, PTT), the PTT polarity, the ADC
   attenuation and the sample rates are *compile-time constants* set in the
   top-level ``CMakeLists.txt``. They are physical wiring choices, so they are
   not exposed on the web admin. Everything an operator legitimately tunes
   without rewiring — modulation profile, preamble, time-slot, FX.25 mode,
   filters, callsigns, intervals — is runtime-editable and, in most cases,
   applied live without a reboot.

**Statistics that reflect reality, not configuration.**
   The dashboard counters (RF RX/TX, RF→INET, INET→RF, digi, drop, error) are
   tracked at the points where frames actually flow, independent of whether the
   IGate or digipeater features are enabled — so a pure RX-only monitor setup
   still shows real decode activity instead of a wall of zeros.

**Fail loud, fail safe.**
   The Wi-Fi bring-up path is heavily instrumented: disconnect reason codes are
   logged, an STA-only device with nothing to join falls back to AP+STA so the
   web admin stays reachable, and reconnects use a growing back-off armed on a
   timer rather than a blocking delay inside the event loop.

Lineage and credits
===================

The project and its modem component are by **Emiliano Augusto González
(LU3VEA)**. The soft-modem's DSP lineage traces to three earlier projects:
**VP-Digi** (SQ8VPS), **ESP32APRS_Audio** (nakhonthai) and **LibAPRS**
(Mark Qvist). The configuration schema, web-admin layout and dashboard
semantics follow the reference **ESP32APRS** project so that JSON key names and
operator expectations carry over. See
:ref:`en-credits` for full attribution and licensing.

The firmware is licensed under the **GNU General Public License v3.0**.

.. warning::

   **Amateur radio disclaimer.** Transmitting on amateur radio frequencies
   requires a valid licence for your country and band. Set a real callsign —
   the default is ``NOCALL`` — use a legitimate APRS-IS passcode, respect your
   local band plan and digipeating conventions (``WIDE1-1,WIDE2-1`` is *not*
   always appropriate), and do not gate ``NOGATE``/``RFONLY`` traffic. You are
   responsible for everything this device transmits.

How this compares to popular APRS software
============================================

APRS is normally assembled from separate pieces of software, each covering
one part of the job: a soundcard TNC/modem, a client with a map and a
messaging UI, and sometimes a dedicated digipeater or IGate program running
on a PC or single-board computer. The table below lines up the most widely
used packages against ``esp32idf_APRS`` feature by feature, to make clear
what a single ESP32 running this firmware does and does not replace.

The comparison covers **Direwolf** (WB2OSZ — the de-facto standard
software soundcard TNC/modem, digipeater and IGate for Linux/Windows/macOS),
**Xastir** (a mature, highly configurable X11/Linux desktop client with
extensive mapping), **YAAC** ("Yet Another APRS Client", KA2DDO — a
cross-platform Java client with a modern UI), **APRSIS32 / UI-View**
(Windows-only desktop clients, historically dominant, UI-View now
unmaintained/legacy), and **APRSdroid** (the common Android mobile client).
Most of these are commonly paired together — e.g. Direwolf as the modem/TNC
feeding Xastir or YAAC as the client — rather than used entirely alone;
``esp32idf_APRS`` is unusual in providing the equivalent of the modem, the
gateway/digipeater logic *and* the operator interface in one single-board
firmware image.

.. list-table::
   :header-rows: 1
   :widths: 26 15 12 12 12 12 27

   * - Feature
     - esp32idf_APRS
     - Direwolf
     - Xastir
     - YAAC
     - APRSIS32 / UI-View
     - Notes
   * - Runs standalone, no host PC
     - ✅
     - ❌ (needs a host OS)
     - ❌
     - ❌
     - ❌
     - This project's core differentiator: modem + logic + UI on one MCU.
   * - Software AFSK/FSK soundcard modem
     - ✅ (on-chip ADC/DAC)
     - ✅ (PC sound card)
     - ➖ (usually via Direwolf)
     - ➖ (usually via Direwolf/AGW)
     - ➖ (via TNC or AGW)
     - Only Direwolf and this project *are* the modem; the others consume one.
   * - Hardware TNC / KISS support
     - ❌
     - ✅
     - ✅
     - ✅
     - ✅
     - This firmware is its own modem; it does not speak to an external TNC.
   * - AX.25 UI frame RX/TX
     - ✅
     - ✅
     - ✅
     - ✅
     - ✅
     - Baseline for all APRS software.
   * - FX.25 (Reed–Solomon FEC)
     - ✅
     - ✅
     - ❌
     - ➖ (client-side only)
     - ❌
     - Direwolf and this project both encode/decode FX.25 directly.
   * - IGate (RF → APRS-IS)
     - ✅
     - ✅
     - ✅
     - ✅
     - ✅
     - Common to nearly every APRS package.
   * - IGate (APRS-IS → RF, "two-way")
     - ✅
     - ✅
     - ✅
     - ✅
     - ✅
     - Usually gated by local/duplicate/type filters everywhere.
   * - Digipeater (WIDEn-N / TRACEn-N)
     - ✅
     - ✅
     - ✅
     - ✅
     - ➖ (limited)
     - 
   * - Built-in web admin UI
     - ✅
     - ❌ (config file + optional 3rd-party web UIs)
     - ❌ (native X11 GUI)
     - ❌ (native Java Swing GUI)
     - ❌ (native Windows GUI)
     - This firmware is the only one configured purely through a browser.
   * - Live map display
     - ❌
     - ❌ (text/log only)
     - ✅ (extensive)
     - ✅
     - ✅
     - Deliberately out of scope — this is a station, not a mapping client.
   * - GPS-based live tracking
     - ✅ (NMEA receiver + SmartBeaconing)
     - ➖ (via connected GPS/tracker)
     - ✅
     - ✅
     - ✅
     - A GNSS module on its own UART feeds the Tracker beacon; the IGate and
       digipeater beacons stay fixed-position. See :ref:`en-beacons`.
   * - Position beaconing (fixed station)
     - ✅
     - ✅ (as config'd)
     - ✅
     - ✅
     - ✅
     - 
   * - APRS messaging (chat, ack/retry)
     - ✅ (web chat UI)
     - ➖ (via connected client)
     - ✅
     - ✅
     - ✅
     - 
   * - Bulletins / announcements
     - ✅
     - ➖ (relays, doesn't compose)
     - ✅
     - ✅
     - ✅
     - 
   * - Objects / items
     - ✅ (up to 5, own-station)
     - ➖ (relays, doesn't compose)
     - ✅
     - ✅
     - ✅
     - 
   * - Weather station reporting
     - ✅ (native sensor framework)
     - ➖ (via external WX software)
     - ✅ (via external feed)
     - ✅ (via external feed)
     - ✅ (via external feed)
     - This firmware reads sensors and encodes WX reports itself, on-chip.
   * - Telemetry (analog/digital channels)
     - ✅ (A1–A5, B1–B8, EQNS/UNIT/BITS)
     - ❌
     - ➖ (display only)
     - ➖ (display only)
     - ➖ (display only)
     - 
   * - APRStt (DTMF-to-APRS gateway)
     - ❌
     - ✅
     - ❌
     - ❌
     - ❌
     - Not implemented in this project.
   * - OTA firmware / software update
     - ✅ (dual OTA slot, auto-rollback)
     - ➖ (OS package manager)
     - ➖ (OS package manager)
     - ➖ (OS package manager)
     - ➖ (manual installer)
     - "OTA" here is specific to the embedded firmware-update model.
   * - Multi-language UI
     - ✅ (EN/ES/IT, compile-time)
     - ❌ (English only)
     - ➖ (partial translations)
     - ❌ (English only)
     - ❌ (English only)
     - 
   * - Cost / hardware footprint
     - Single ~US$5–10 ESP32 board + audio interface
     - PC/RPi + sound card + radio
     - PC/RPi + TNC + radio
     - PC/phone + TNC + radio
     - Windows PC + TNC + radio
     - 

Legend: ✅ implemented / native · ➖ partial, or available only via another
program in the chain · ❌ not implemented / not applicable.

**What this project deliberately does implement**, matching the core of what
a full desktop APRS station provides: the modem itself, AX.25/FX.25 framing,
two-way IGate, digipeating, beacons, messaging, bulletins,
objects, weather and telemetry, all reachable from a self-hosted web UI with
no companion PC software.

**What this project deliberately does not implement**: it has no map
display, and it does not include an APRStt DTMF-to-APRS gateway. These are intentionally out of scope for a headless, browser
configured embedded station — a companion mapping client such as YAAC,
Xastir or `aprs.fi <https://aprs.fi>`__ remains the natural way to
*visualise* the traffic this firmware generates and relays.

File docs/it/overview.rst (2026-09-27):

.. _it-overview:

==========
Panoramica
==========

Che cos'è
=========

``esp32idf_APRS`` è un progetto ESP-IDF **v6.x** (testato e bloccato su IDF
**6.1**) che trasforma un semplice ESP32 DevKit più una interfaccia audio
economica in una stazione APRS completa e autonoma. Tutto gira sull'ESP32 stesso
— non c'è un core Arduino, niente ``String``, niente PlatformIO e nessuna
libreria DSP esterna. L'intera catena di segnale, dal demodulatore a
correlazione attraverso il recupero dei bit DPLL, NRZI, l'incapsulatore HDLC, il
codec AX.25 e la correzione d'errore in avanti FX.25 Reed–Solomon, viene
eseguita sul microcontrollore usando solo il SAR-ADC in modalità continua/DMA,
il DAC e un timer generico.

In una frase: il firmware

* **demodula** l'audio AFSK/FSK dall'uscita altoparlante o discriminatore di una
  radio su **ADC1**,
* **decodifica** i frame HDLC/AX.25 (opzionalmente con correzione FX.25),
* li **inoltra** verso APRS-IS su Wi-Fi (``qAR``/``qAO``),
* li **digipeta** di nuovo in RF (WIDEn-N, tramite una tabella di alias
  configurabile dall'operatore),
* trasmette **beacon** della propria posizione, meteo e telemetria,
* **modula** e ritrasmette i frame attraverso il **DAC a 8 bit** dell'ESP32,
  attivando la radio tramite un GPIO di PTT,
* ed è configurato interamente tramite un'**amministrazione web HTTP** servita
  dal dispositivo stesso — nessuna console seriale, nessuna ricompilazione per le
  impostazioni ordinarie.

Matrice delle funzionalità
==========================

.. list-table::
   :header-rows: 1
   :widths: 40 12 48

   * - Area
     - Stato
     - Note
   * - AFSK 1200 Bd Bell 202 (APRS standard)
     - ✅
     - fino a tre demodulatori in parallelo, profilo predefinito
   * - AFSK 1200 Bd ITU V.23 (1300/2100 Hz)
     - ✅
     -
   * - AFSK 300 Bd (1600/1800 Hz)
     - ✅
     - stile HF
   * - G3RUH FSK 9600 Bd
     - ✅
     - richiede audio piatto/discriminatore
   * - Frame UI HDLC / AX.25 RX+TX
     - ✅
     - ``AX25_FRAME_MAX_SIZE = 329``
   * - FX.25 (RS FEC su AX.25)
     - ✅
     - modalità solo-RX / RX+TX
   * - Attivazione PTT (GPIO + polarità in compilazione)
     - ✅
     - GPIO validato; tempo minimo di **dis-attivazione** a runtime
   * - CSMA / slot temporale TX / p-persistenza / preambolo TXDelay / coda TXTail
     - ✅
     - ``preamble``, ``tx_tail``, ``tx_timeslot``, ``csma_persist``, ``csma_slot_ms``,
       ``csma_busy_max_s``
   * - DCD (rilevamento portante dati)
     - ✅
     - derivato dal demodulatore; nessun ingresso squelch hardware
   * - IGate APRS-IS RF→INET
     - ✅
     - filtri, dedup, ``qAR``/``qAO``
   * - IGate APRS-IS INET→RF
     - ✅
     - gating per tipo + budlist + opzione unwrap di terze parti
   * - Interconnessione APRS con BrandMeister (senza collegamento DMR)
     - ✅
     - riconoscimento, gating e instradamento dei messaggi sulla sessione
       APRS-IS esistente; pagina dedicata, disattivata per impostazione
       predefinita
   * - Gate di portata e di prefisso locale RF→INET
     - ✅
     - distanza haversine + whitelist di prefisso indicativo
   * - Whitelist / blacklist indicativi (budlist)
     - ✅
     - per direzione, si compone (AND) con i filtri di tipo
   * - Elenco digipeater satellitari (ISS)
     - ✅
     - fino a 8 voci, configurabile dal web (pagina IGate), senza ricompilare
   * - Interruttore, dimensione e finestra della cache soppressione duplicati
     - ✅
     - configurabile dal web (pagina IGate), condiviso da IGate e Digipeater
   * - Digipeater
     - ✅
     - WIDEn-N tramite tabella di alias configurabile, soppressione duplicati;
       gli alias legacy ``RELAY``/``ECHO``/``GATE``/``TRACEn-N`` non sono
       integrati, ma possono essere aggiunti come normali righe di alias
   * - Oggetti / Item APRS della propria stazione
     - ✅
     - fino a 5, RF e/o INET, decadimento intervallo + kill-repeat
   * - Bollettini APRS (BLN1..BLN5)
     - ✅
     - fino a 5, RF e/o INET, scadenza per bollettino
   * - Interfaccia chat messaggi APRS (``/msgchat``)
     - ✅
     - pagina inbox/composizione sul motore di messaggistica
   * - Risponditore di query APRS (APRS101 cap.15)
     - ✅
     - generali ``?APRS?``/``?WX?``/``?IGATE?``/``?QRU?`` + l'insieme diretto
       (``?APRSD``/``?APRSH``/``?APRSM``/``?APRSO``/``?APRSP``/``?APRSS``/
       ``?APRST``/``?PING?``), con limiti di frequenza per tipo e per sorgente
   * - Beacon a posizione fissa (tracker / igate / digi)
     - ✅
     - un singolo task pianificatore di beacon condiviso
   * - Ricevitore GNSS NMEA (UART dedicata) + pagina di vista live
     - ✅
     - interruttore principale; RMC/GGA/GSA/GSV/VTG, multicostellazione, vista
       web a 1 Hz
   * - Tracciamento GPS live + SmartBeaconing
     - ✅
     - solo beacon Tracker; intervallo adattivo sulla velocità e corner-pegging
   * - Messaggistica APRS + ack/ritentativo
     - ✅
     - RF e/o INET
   * - Amministrazione web (autenticazione HTTP Basic)
     - ✅
     - 22 pagine nella barra laterale + selettore di simbolo, dashboard in
       tempo reale
   * - Log traffico in tempo reale (dashboard) + feed last-heard
     - ✅
     - tabella di traffico via long-poll JSON (``?since=<seq>``); la tabella
       last-heard per stazione è un feed JSON (``/lastheard``) e la fonte letta
       dal gate dei messaggi e dalle risposte ``?APRSD``/``?APRSH``
   * - Archiviazione LittleFS, upload/download/elimina/formatta
     - ✅
     - partizione da 512 KB
   * - Sincronizzazione oraria SNTP (3 host)
     - ✅
     - orologio sempre mantenuto in UTC
   * - Controllo frequenza CPU (80/160/240 MHz)
     - ✅
     - ``esp_pm_configure()``
   * - Wi-Fi AP / STA / AP+STA, scansione, potenza TX
     - ✅
     - 5 slot STA (si usa il primo abilitato)
   * - Localizzazione (EN / ES / IT)
     - ✅
     - in compilazione, una lingua per immagine
   * - Aggiornamento OTA
     - ✅
     - slot ``ota_0``/``ota_1``, rollback automatico su avvio fallito
   * - Report meteo APRS della propria stazione
     - ✅
     - refresh sensori a 1 Hz, media opzionale, beacon WX in onda
   * - Framework driver sensori locali (``sensors_local``)
     - ✅
     - registro dinamico a runtime, driver auto-registranti
   * - Codifica/beacon telemetria APRS in onda
     - ✅
     - analogici A1–A5 + digitali B1–B8, report ``T#nnn`` + metadati
   * - Posta radio Winlink (APRSLink)
     - ✅
     - casella propria ``NOMINATIVO@winlink.org`` tramite ``WLNK-1``, più un
       gateway opzionale per la sessione di una stazione vicina; pagina
       propria, disattivata di default
   * - Ponte con bot Telegram
     - ✅
     - opzionale; long polling su HTTPS, autorizzazione per utente e per chat,
       instradamento di messaggi di stazione e bollettini, risposte
       ``/status`` e ``/sensors``; pagina e file di impostazioni propri,
       disattivato di default
   * - Visualizzatore del log di console
     - ✅
     - copia su richiesta della console seriale nel browser (pagina Log), senza
       cavo e senza scrivere nulla in flash

Filosofia di progetto
=====================

Diverse decisioni architetturali deliberate ricorrono in tutto il codice e
vale la pena interiorizzarle subito:

**Una configurazione residente, una copia viva.**
   Una singola istanza ``app_config_t g_config`` è la fonte di verità che ogni
   sottosistema legge. Persiste su un file per funzionalità
   dell'amministrazione web sotto ``/storage``. I sottosistemi non
   duplicano mai lo stato di configurazione; leggono ``g_config`` direttamente.
   I sottosistemi che necessitano di uno stato più grande e specifico della
   pagina lo mantengono in file LittleFS separati invece di gonfiare
   ``g_config``: telemetria (``/storage/telemetry.json``), bollettini
   (``/storage/bulletins.json``), oggetti/item (``/storage/objitems.json``), il
   bot Telegram (``/storage/telegram.json``, che contiene l'intera
   configurazione di quella pagina) e la casella Winlink
   (``/storage/winlink.json``, le risposte che il servizio ha rimandato).

**Cablaggio di scheda in compilazione, tutto il resto a runtime.**
   I tre pin audio (ADC, DAC, PTT), la polarità del PTT, l'attenuazione dell'ADC
   e le frequenze di campionamento sono *costanti di compilazione* impostate nel
   ``CMakeLists.txt`` di livello superiore. Sono scelte di cablaggio fisico,
   quindi non sono esposte nell'amministrazione web. Tutto ciò che un operatore
   regola legittimamente senza ricablare — profilo di modulazione, preambolo,
   slot temporale, modalità FX.25, filtri, indicativi, intervalli — è
   modificabile a runtime e, nella maggior parte dei casi, applicato in tempo
   reale senza riavvio.

**Statistiche che riflettono la realtà, non la configurazione.**
   I contatori della dashboard (RF RX/TX, RF→INET, INET→RF, digi, drop, errore)
   sono tracciati nei punti dove i frame effettivamente scorrono,
   indipendentemente dal fatto che le funzioni IGate o digipeater siano
   abilitate — così una configurazione di puro monitoraggio solo-RX mostra
   comunque attività di decodifica reale invece di un muro di zeri.

**Fallire rumorosamente, fallire in sicurezza.**
   Il percorso di avvio del Wi-Fi è pesantemente strumentato: i codici di
   disconnessione sono registrati, un dispositivo solo-STA senza nulla a cui
   unirsi ripiega su AP+STA così l'amministrazione web resta raggiungibile, e le
   riconnessioni usano un back-off crescente armato su un timer invece di un
   ritardo bloccante dentro il loop degli eventi.

Lignaggio e riconoscimenti
==========================

Il progetto e il suo componente modem sono di **Emiliano Augusto González
(LU3VEA)**. Il lignaggio DSP del modem software risale a tre progetti
precedenti: **VP-Digi** (SQ8VPS), **ESP32APRS_Audio** (nakhonthai) e **LibAPRS**
(Mark Qvist). Lo schema di configurazione, la disposizione dell'amministrazione
web e la semantica della dashboard seguono il progetto di riferimento
**ESP32APRS** così che i nomi delle chiavi JSON e le aspettative
dell'operatore vengano mantenuti. Vedi :ref:`it-credits` per l'attribuzione e la
licenza complete.

Il firmware è rilasciato sotto la **GNU General Public License v3.0**.

.. warning::

   **Avviso legale radioamatoriale.** Trasmettere su frequenze radioamatoriali
   richiede una licenza valida per il tuo paese e banda. Imposta un indicativo
   reale — il valore predefinito è ``NOCALL`` — usa un passcode APRS-IS
   legittimo, rispetta il tuo piano di banda locale e le convenzioni di
   digipeating (``WIDE1-1,WIDE2-1`` *non* è sempre appropriato), e non inoltrare
   traffico ``NOGATE``/``RFONLY``. Sei responsabile di tutto ciò che questo
   dispositivo trasmette.

Confronto con il software APRS più diffuso
=============================================

Una stazione APRS viene normalmente assemblata da pezzi di software
separati, ognuno dei quali copre una parte del lavoro: un modem/TNC su
scheda audio, un client con mappa e interfaccia di messaggistica e, a
volte, un programma dedicato di digipeater o IGate eseguito su un PC o su
una scheda a singola board. La tabella seguente mette a confronto i
pacchetti più diffusi con ``esp32idf_APRS``, funzione per funzione, per
chiarire cosa un singolo ESP32 con questo firmware sostituisce e cosa no.

Il confronto copre **Direwolf** (WB2OSZ — il modem/TNC software de facto
standard per Linux/Windows/macOS, con digipeater e IGate inclusi),
**Xastir** (un client desktop X11/Linux maturo e molto configurabile con
mappatura estesa), **YAAC** ("Yet Another APRS Client", KA2DDO — un client
Java multipiattaforma con interfaccia moderna), **APRSIS32 / UI-View**
(client desktop solo Windows, storicamente dominanti, UI-View ormai
legacy/non più mantenuto) e **APRSdroid** (il client mobile Android più
diffuso). Questi programmi vengono spesso combinati tra loro — per
esempio Direwolf come modem/TNC che alimenta Xastir o YAAC come client —
piuttosto che usati completamente da soli; ``esp32idf_APRS`` è insolito
perché fornisce l'equivalente del modem, della logica di
gateway/digipeater *e* dell'interfaccia operatore in un unico firmware su
scheda singola.

.. list-table::
   :header-rows: 1
   :widths: 26 15 12 12 12 12 27

   * - Funzione
     - esp32idf_APRS
     - Direwolf
     - Xastir
     - YAAC
     - APRSIS32 / UI-View
     - Note
   * - Funziona in autonomia, senza PC host
     - ✅
     - ❌ (richiede un SO host)
     - ❌
     - ❌
     - ❌
     - Elemento distintivo di questo progetto: modem + logica + UI su un
       unico MCU.
   * - Modem software AFSK/FSK (scheda audio)
     - ✅ (ADC/DAC sul chip)
     - ✅ (scheda audio del PC)
     - ➖ (solitamente via Direwolf)
     - ➖ (solitamente via Direwolf/AGW)
     - ➖ (via TNC o AGW)
     - Solo Direwolf e questo progetto *sono* il modem; gli altri ne
       consumano uno.
   * - Supporto TNC hardware / KISS
     - ❌
     - ✅
     - ✅
     - ✅
     - ✅
     - Questo firmware è esso stesso il modem; non dialoga con un TNC
       esterno.
   * - Trame UI AX.25 RX/TX
     - ✅
     - ✅
     - ✅
     - ✅
     - ✅
     - Base comune a tutto il software APRS.
   * - FX.25 (FEC Reed–Solomon)
     - ✅
     - ✅
     - ❌
     - ➖ (solo lato client)
     - ❌
     - Direwolf e questo progetto codificano/decodificano FX.25
       direttamente.
   * - IGate (RF → APRS-IS)
     - ✅
     - ✅
     - ✅
     - ✅
     - ✅
     - Comune a quasi tutto il software APRS.
   * - IGate (APRS-IS → RF, "bidirezionale")
     - ✅
     - ✅
     - ✅
     - ✅
     - ✅
     - Generalmente filtrato ovunque da filtri locali/duplicati/di tipo.
   * - Digipeater (WIDEn-N / TRACEn-N)
     - ✅
     - ✅
     - ✅
     - ✅
     - ➖ (limitato)
     -
   * - Amministrazione web integrata
     - ✅
     - ❌ (file di config + interfacce web di terze parti opzionali)
     - ❌ (GUI nativa X11)
     - ❌ (GUI nativa Java Swing)
     - ❌ (GUI nativa Windows)
     - Questo firmware è l'unico configurato interamente da browser.
   * - Mappa in tempo reale
     - ❌
     - ❌ (solo testo/log)
     - ✅ (estesa)
     - ✅
     - ✅
     - Fuori ambito deliberatamente — questa è una stazione, non un client
       di mappatura.
   * - Tracciamento in tempo reale via GPS
     - ✅ (ricevitore NMEA + SmartBeaconing)
     - ➖ (via GPS/tracker collegato)
     - ✅
     - ✅
     - ✅
     - Un modulo GNSS su una UART dedicata alimenta il beacon Tracker; i beacon
       di IGate e digipeater restano a posizione fissa. Vedi
       :ref:`it-beacons`.
   * - Beacon di posizione (stazione fissa)
     - ✅
     - ✅ (secondo configurazione)
     - ✅
     - ✅
     - ✅
     -
   * - Messaggistica APRS (chat, ack/ritentativo)
     - ✅ (UI di chat web)
     - ➖ (via client collegato)
     - ✅
     - ✅
     - ✅
     -
   * - Bollettini / annunci
     - ✅
     - ➖ (ritrasmette, non compone)
     - ✅
     - ✅
     - ✅
     -
   * - Oggetti / item
     - ✅ (fino a 5, della propria stazione)
     - ➖ (ritrasmette, non compone)
     - ✅
     - ✅
     - ✅
     -
   * - Report di stazione meteo
     - ✅ (framework sensori nativo)
     - ➖ (via software meteo esterno)
     - ✅ (via feed esterno)
     - ✅ (via feed esterno)
     - ✅ (via feed esterno)
     - Questo firmware legge i sensori e codifica i report WX da solo, sul
       chip.
   * - Telemetria (canali analogici/digitali)
     - ✅ (A1–A5, B1–B8, EQNS/UNIT/BITS)
     - ❌
     - ➖ (solo visualizzazione)
     - ➖ (solo visualizzazione)
     - ➖ (solo visualizzazione)
     -
   * - APRStt (gateway DTMF-to-APRS)
     - ❌
     - ✅
     - ❌
     - ❌
     - ❌
     - Non implementato in questo progetto.
   * - Aggiornamento firmware/software OTA
     - ✅ (doppio slot OTA, rollback automatico)
     - ➖ (gestore pacchetti del SO)
     - ➖ (gestore pacchetti del SO)
     - ➖ (gestore pacchetti del SO)
     - ➖ (installer manuale)
     - "OTA" qui è specifico del modello di aggiornamento firmware
       embedded.
   * - Interfaccia multilingua
     - ✅ (EN/ES/IT, a tempo di compilazione)
     - ❌ (solo inglese)
     - ➖ (traduzioni parziali)
     - ❌ (solo inglese)
     - ❌ (solo inglese)
     -
   * - Costo / ingombro hardware
     - Una singola scheda ESP32 (~5–10 USD) + interfaccia audio
     - PC/RPi + scheda audio + radio
     - PC/RPi + TNC + radio
     - PC/telefono + TNC + radio
     - PC Windows + TNC + radio
     -

Legenda: ✅ implementato / nativo · ➖ parziale, o disponibile solo tramite
un altro programma della catena · ❌ non implementato / non applicabile.

**Ciò che questo progetto implementa deliberatamente**, eguagliando il
nucleo di ciò che offre una stazione APRS desktop completa: il modem
stesso, il framing AX.25/FX.25, l'IGate bidirezionale, il digipeating, i
beacon, la messaggistica, i bollettini, gli oggetti, il meteo
e la telemetria, tutto raggiungibile da un'interfaccia web self-hosted
senza software companion su PC.

**Ciò che questo progetto deliberatamente non implementa**: non ha
visualizzazione su mappa, e non include un gateway APRStt da DTMF ad APRS. Questi elementi sono intenzionalmente fuori ambito
per una stazione embedded headless configurata via browser — un client di
mappatura complementare come YAAC, Xastir o `aprs.fi <https://aprs.fi>`__
resta il modo naturale per *visualizzare* il traffico che questo firmware
genera e ritrasmette.

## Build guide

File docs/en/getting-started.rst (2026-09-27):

.. _en-getting-started:

===============
Getting Started
===============

Prerequisites
=============

* **ESP-IDF v6.1 or newer** (locked/tested at **6.1** — see
  ``dependencies.lock``).
* An ESP32 with **≥ 4 MB flash**.
* The IDF component manager fetches ``joltwallet/littlefs``, ``espressif/cjson``
  and, via the
  ``sensors_local`` component, ``esp-idf-lib/bmp280`` and
  ``esp-idf-lib/bmp180`` (which pull in ``i2cdev`` +
  ``esp_idf_lib_helpers``) automatically.

Building and flashing
=====================

.. code-block:: bash

   . $IDF_PATH/export.sh

   cd workspace-APRS/esp32_APRS_igate

   idf.py set-target esp32          # sdkconfig already ships with target=esp32
   idf.py build
   idf.py -p /dev/ttyUSB0 flash monitor

Build in Spanish or Italian instead of English (see :ref:`en-localization`):

.. code-block:: bash

   idf.py build -DLANGUAGE=LANG_ES
   idf.py build -DLANGUAGE=LANG_IT

.. tip::

   ``sdkconfig`` ships with ``CONFIG_COMPILER_OPTIMIZATION_DEBUG`` (``-Og``)
   and assertions on, and with ``CONFIG_COMPILER_STACK_CHECK_MODE_NORM`` for
   the stack canary — the configuration every task stack in the project was
   budgeted under. Switching to ``CONFIG_COMPILER_OPTIMIZATION_SIZE`` (``-Os``)
   makes a smaller image with shallower stack frames, but it changes the
   frame sizes those budgets were set against, so re-check the stack
   high-water marks (see :ref:`en-troubleshooting`) after doing so.

Memory budget
=============

The ESP32 on this design has no PSRAM, so every byte of internal DRAM the
build reserves statically is a byte the heap never gets. ``sdkconfig`` is
tuned for that, and the settings below are deliberate - raising any of them
lowers the *Min free heap* figure on the dashboard.

.. list-table::
   :header-rows: 1
   :widths: 44 10 46

   * - Setting
     - Value
     - Why
   * - ``CONFIG_ESP_WIFI_STATIC_RX_BUFFER_NUM``
     - 6
     - ~1.6 KB each, allocated at ``esp_wifi_init()`` and held until Wi-Fi is
       de-initialised. Six matches ``CONFIG_ESP_WIFI_RX_BA_WIN``, which is the
       floor AMPDU RX wants.
   * - ``CONFIG_ESP_WIFI_DYNAMIC_RX_BUFFER_NUM`` / ``..._TX_...``
     - 12 / 24
     - Caps the Wi-Fi driver's peak heap claim. APRS traffic is a few hundred
       bytes per minute; the throughput these buffers buy is never used.
   * - ``CONFIG_LWIP_TCP_SND_BUF_DEFAULT`` / ``CONFIG_LWIP_TCP_WND_DEFAULT``
     - 5760
     - Four MSS (``CONFIG_LWIP_TCP_MSS`` is 1440) per direction per connection.
       The only sustained transfer is an OTA image upload, which still
       saturates a LAN at this window.
   * - ``max_open_sockets`` in ``web_server_start()``
     - 3
     - httpd takes this plus 3 sockets of its own out of the
       ``CONFIG_LWIP_MAX_SOCKETS`` (16) pool. The remaining budget is what the
       APRS-IS uplink, DNS, SNTP and the Telegram bot's HTTPS client need to
       stay up while someone is browsing the admin pages.
   * - HTTPS server, certificate bundle, Wi-Fi Enterprise
     - disabled
     - The web admin is plain HTTP and the APRS-IS uplink is plain TCP, and
       nothing ever listens for TLS: ``CONFIG_ESP_HTTPS_SERVER_ENABLE``,
       ``CONFIG_MBEDTLS_CERTIFICATE_BUNDLE`` and
       ``CONFIG_ESP_WIFI_ENTERPRISE_SUPPORT`` are all off in ``sdkconfig``.
       One code path does open TLS, as a *client*: the Telegram bot talks to
       ``api.telegram.org`` over HTTPS through ``esp_http_client``/``esp_tls``.
       With the certificate bundle off it verifies the server against a PEM
       file the operator uploads to the storage partition
       (``CONFIG_TELEGRAM_BOT_CERT_PATH``, ``/storage/telegram_certificate.pem``
       by default) rather than against a root store compiled into the image —
       a few kilobytes of flash instead of the bundle's tens. A station that
       leaves the bot switched off never allocates any of it.
   * - ``CONFIG_MBEDTLS_SSL_IN_CONTENT_LEN`` / ``..._OUT_CONTENT_LEN``
     - 8192 / 2048
     - The record buffers, allocated per TLS session, so a station with the bot
       off pays nothing for them. Inbound needs the larger figure because a
       server chooses its own record size and the standard allows up to 16384;
       outbound is this device's own choice and its requests are small.
       ``CONFIG_MBEDTLS_DYNAMIC_BUFFER`` is on, so even a live session holds the
       full buffers only while records are actually in flight.
   * - mbedTLS itself
     - enabled
     - Wi-Fi crypto needs it regardless, so ``CONFIG_MBEDTLS_TLS_ENABLED`` and
       its nested ``_SERVER``/``_CLIENT`` options stay at their defaults. HTTP
       Basic auth still decodes its credential pair with a small local RFC 4648
       base64 decoder (``components/webconfig/include/web_base64.h``) instead of
       ``mbedtls_base64_decode()``, so ``webconfig`` declares no mbedTLS
       dependency of its own; ``esp_wifi``/``esp_netif``/``lwip`` pull mbedTLS in
       transitively for WPA2 crypto, which is unaffected by any of these
       settings.

.. note::

   From ESP-IDF v6.0 the mbedTLS port calls ``psa_crypto_init()`` from a
   system startup hook, so PSA Crypto is live in every build that links
   mbedTLS, including this one, regardless of ``CONFIG_MBEDTLS_TLS_ENABLED``.
   That, together with mbedTLS 4.x's larger static footprint, is why the same
   firmware reports a lower free heap under v6.x than it did under v5.2 with
   an otherwise identical configuration. The behaviour was introduced in v6.0
   and is unchanged in the v6.1 this project now builds against.

First boot
==========

#. On a fresh partition, LittleFS auto-formats and ``app_config_load()`` writes
   one configuration file per functionality from factory defaults.
#. The ESP32 comes up as a **Wi-Fi AP**: SSID ``esp32idf_APRS``, password
   ``esp32idf_APRS``, channel 1, WPA2-PSK, max 4 clients.
#. Join it and browse to the device (default ``http://192.168.4.1/``).
#. **Log in:** ``admin`` / ``admin`` — change this on the *System* page. The
   same page carries an optional second account, *Web Read-Only Login*: it sees
   every page but saves nothing, moves no files and transmits nothing, and may
   only start and stop the console log viewer. It is unset out of the box.
#. On *Wireless*: pick **Station** or **AP+STA**, tick **Enable** in a Wi-Fi
   Client block, enter SSID/password, Save.
#. On *IGate*: set your **callsign**, **SSID**, **passcode**, APRS-IS
   **host**/**port**, filter, coordinates, symbol, comment.
#. On *Radio / Modem*: enable the audio modem, pick the modulation, preamble,
   TX time slot; use **LOOP TEST** to verify the audio path.
#. Reboot (or Save — most settings re-apply live).

Notable factory defaults
========================

.. list-table::
   :header-rows: 1
   :widths: 45 55

   * - Setting
     - Default
   * - Wi-Fi mode
     - AP (always reachable)
   * - AP SSID / pass
     - ``esp32idf_APRS`` / ``esp32idf_APRS``
   * - Web login
     - ``admin`` / ``admin``
   * - Web read-only login
     - unset (no read-only account)
   * - CPU frequency
     - 240 MHz
   * - System clock
     - always UTC (TZ=UTC0). The System page's timezone selector (default
       ``UTC``) only changes the local date/time shown on the dashboard; on-air
       timestamps stay zulu
   * - NTP hosts
     - ``pool.ntp.org``, ``time.google.com``, ``time.cloudflare.com``
   * - IGate
     - enabled, ``rf2inet`` on, ``inet2rf`` off
   * - Callsign / SSID
     - ``NOCALL`` / 10, passcode ``-1``
   * - Station coordinates
     - ``0.000`` / ``0.000``; every position beacon and status-report grid
       locator is withheld while a role's coordinates are still at this
       default
   * - APRS-IS servers
     - four failover slots, all preset to ``aprs.dprns.com`` : 14580, with only
       slot 1 enabled
   * - Satellite gate-call list
     - ``RS0ISS``, ``YBOX``, ``YBSAT``, ``PSAT``, ``W3ADO``, ``BJ1SI`` (up to 8, web-configurable)
   * - Duplicate suppression / cache / window
     - enabled / 20 entries / 30000 ms (web-configurable)
   * - Transmit duty-cycle limiter
     - disabled; ceiling 25 % of a rolling 10-minute window when enabled
   * - Path preset 0
     - ``WIDE1-1,WIDE2-1``
   * - Path selection
     - preset 0, for the IGate, digipeater, tracker and weather beacons alike
   * - Digipeater
     - disabled, SSID 1
   * - Tracker
     - disabled, SSID 9
   * - Audio modem
     - enabled, 1200 Bd Bell 202
   * - Preamble / TX slot
     - 300 ms / 2000 ms
   * - CSMA persistence
     - 63 (~25 % transmit chance per clear slot)
   * - CSMA slot time / busy channel max wait
     - 100 ms / 30 s
   * - RF TX buffers
     - 1
   * - Query responder
     - disabled; RF on, Internet off, minimum reply interval 30 s
   * - FX.25
     - off
   * - PTT
     - GPIO26 (polarity is compile-time)
   * - Messaging
     - enabled, RF + INET, alarm GPIO disabled

.. danger::

   **Change** ``NOCALL`` **and set a real passcode before transmitting.**
   Verify you are licensed for the frequency and duty cycle you are about to
   key up on.

   **Set the station coordinates too.** APRS has no "position unknown"
   coordinate, so this firmware treats the factory-default ``0.000`` /
   ``0.000`` pair — Null Island, not a real amateur station site — as "not
   yet configured" and withholds the Tracker, IGate and Digipeater position
   beacons (and the Maidenhead locator of their status reports) rather than
   putting a false fix in the Gulf of Guinea on the air. A beacon whose
   coordinates are still unset stays silent instead of transmitting; check
   the log if it does not seem to be sending anything.

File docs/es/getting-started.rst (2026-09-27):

.. _es-getting-started:

==============
Primeros pasos
==============

Requisitos previos
==================

* **ESP-IDF v6.1 o posterior** (fijado/probado en **6.1** — véase
  ``dependencies.lock``).
* Un ESP32 con **≥ 4 MB de flash**.
* El gestor de componentes de IDF descarga ``joltwallet/littlefs``,
  ``espressif/cjson`` y, a través
  del componente ``sensors_local``, ``esp-idf-lib/bmp280`` y
  ``esp-idf-lib/bmp180`` (que arrastran ``i2cdev`` +
  ``esp_idf_lib_helpers``) automáticamente.

Compilar y grabar
=================

.. code-block:: bash

   . $IDF_PATH/export.sh

   cd workspace-APRS/esp32_APRS_igate

   idf.py set-target esp32          # sdkconfig ya viene con target=esp32
   idf.py build
   idf.py -p /dev/ttyUSB0 flash monitor

Compilar en español o italiano en lugar de inglés (véase :ref:`es-localization`):

.. code-block:: bash

   idf.py build -DLANGUAGE=LANG_ES
   idf.py build -DLANGUAGE=LANG_IT

.. tip::

   ``sdkconfig`` viene con ``CONFIG_COMPILER_OPTIMIZATION_DEBUG`` (``-Og``) y
   las aserciones activadas, y con ``CONFIG_COMPILER_STACK_CHECK_MODE_NORM``
   para el canario de pila: es la configuración bajo la que se dimensionaron
   todas las pilas de tareas del proyecto. Cambiar a
   ``CONFIG_COMPILER_OPTIMIZATION_SIZE`` (``-Os``) produce una imagen más
   pequeña con marcos de pila menos profundos, pero altera los tamaños de marco
   con los que se fijaron esos presupuestos, así que vuelve a comprobar las
   marcas de agua de pila (ver :ref:`es-troubleshooting`) después de hacerlo.

Presupuesto de memoria
======================

El ESP32 de este diseño no lleva PSRAM, así que cada byte de DRAM interna que
la compilación reserva de forma estática es un byte que el heap nunca recibe.
``sdkconfig`` está ajustado para eso, y los valores de abajo son deliberados:
subir cualquiera de ellos baja la cifra *Min free heap* del panel.

.. list-table::
   :header-rows: 1
   :widths: 44 10 46

   * - Opción
     - Valor
     - Por qué
   * - ``CONFIG_ESP_WIFI_STATIC_RX_BUFFER_NUM``
     - 6
     - ~1,6 KB cada uno, reservados en ``esp_wifi_init()`` y retenidos hasta
       que se desinicializa el WiFi. Seis coincide con
       ``CONFIG_ESP_WIFI_RX_BA_WIN``, que es el piso que pide AMPDU RX.
   * - ``CONFIG_ESP_WIFI_DYNAMIC_RX_BUFFER_NUM`` / ``..._TX_...``
     - 12 / 24
     - Acota el pico de heap que reclama el driver WiFi. El tráfico APRS son
       unos cientos de bytes por minuto; el caudal que compran esos búferes no
       se usa nunca.
   * - ``CONFIG_LWIP_TCP_SND_BUF_DEFAULT`` / ``CONFIG_LWIP_TCP_WND_DEFAULT``
     - 5760
     - Cuatro MSS (``CONFIG_LWIP_TCP_MSS`` es 1440) por sentido y por conexión.
       La única transferencia sostenida es la subida de una imagen OTA, que
       con esta ventana sigue saturando una LAN.
   * - ``max_open_sockets`` en ``web_server_start()``
     - 3
     - httpd toma este número más 3 sockets propios del pool de
       ``CONFIG_LWIP_MAX_SOCKETS`` (16). El resto del cupo es lo que necesitan
       el enlace APRS-IS, DNS, SNTP y el cliente HTTPS del bot de Telegram
       para seguir en pie mientras alguien navega las páginas de
       administración.
   * - Servidor HTTPS, paquete de certificados, WiFi Enterprise
     - desactivados
     - La administración web es HTTP plano y el enlace APRS-IS es TCP plano, y
       nada queda nunca a la escucha de TLS:
       ``CONFIG_ESP_HTTPS_SERVER_ENABLE``,
       ``CONFIG_MBEDTLS_CERTIFICATE_BUNDLE`` y
       ``CONFIG_ESP_WIFI_ENTERPRISE_SUPPORT`` están todos desactivados en
       ``sdkconfig``. Un camino de código sí abre TLS, como *cliente*: el bot de
       Telegram habla con ``api.telegram.org`` por HTTPS mediante
       ``esp_http_client``/``esp_tls``. Con el paquete de certificados
       desactivado, verifica al servidor contra un archivo PEM que el operador
       sube a la partición de almacenamiento
       (``CONFIG_TELEGRAM_BOT_CERT_PATH``, ``/storage/telegram_certificate.pem``
       por defecto) en lugar de contra un almacén de raíces compilado en la
       imagen — unos pocos kilobytes de flash en vez de las decenas del
       paquete. Una estación que deje el bot apagado no reserva nada de esto.
   * - ``CONFIG_MBEDTLS_SSL_IN_CONTENT_LEN`` / ``..._OUT_CONTENT_LEN``
     - 8192 / 2048
     - Los búferes de registro, reservados por sesión TLS, así que una estación
       con el bot apagado no paga nada por ellos. La entrada necesita la cifra
       mayor porque el servidor elige su propio tamaño de registro y el estándar
       permite hasta 16384; la salida es decisión de este dispositivo y sus
       peticiones son pequeñas. ``CONFIG_MBEDTLS_DYNAMIC_BUFFER`` está activo,
       así que incluso una sesión viva mantiene los búferes completos solo
       mientras hay registros realmente en curso.
   * - mbedTLS en sí
     - habilitado
     - La criptografía Wi-Fi lo necesita de todos modos, así que
       ``CONFIG_MBEDTLS_TLS_ENABLED`` y sus opciones anidadas
       ``_SERVER``/``_CLIENT`` quedan en sus valores por defecto. La
       autenticación HTTP Basic sigue decodificando su par de credenciales con
       un pequeño decodificador local RFC 4648
       (``components/webconfig/include/web_base64.h``) en lugar de
       ``mbedtls_base64_decode()``, así que ``webconfig`` no declara ninguna
       dependencia propia de mbedTLS; ``esp_wifi``/``esp_netif``/``lwip``
       arrastran mbedTLS de forma transitiva para la criptografía WPA2, que no
       se ve afectada por ninguno de estos ajustes.

.. note::

   Desde ESP-IDF v6.0 el port de mbedTLS llama a ``psa_crypto_init()`` desde
   un hook de arranque del sistema, así que PSA Crypto está vivo en toda
   compilación que enlace mbedTLS, incluida esta, sin importar
   ``CONFIG_MBEDTLS_TLS_ENABLED``. Eso, junto con la mayor huella estática de
   mbedTLS 4.x, es la razón de que el mismo firmware informe menos heap libre
   bajo v6.x que bajo v5.2 con una configuración por lo demás idéntica. La
   conducta se introdujo en v6.0 y no cambia en la v6.1 contra la que este
   proyecto compila ahora.

Primer arranque
===============

#. En una partición nueva, LittleFS se autoformatea y ``app_config_load()``
   escribe un archivo de configuración por funcionalidad con los valores de
   fábrica.
#. El ESP32 arranca como **AP Wi-Fi**: SSID ``esp32idf_APRS``, contraseña
   ``esp32idf_APRS``, canal 1, WPA2-PSK, máx. 4 clientes.
#. Únete a él y navega al dispositivo (por defecto ``http://192.168.4.1/``).
#. **Inicia sesión:** ``admin`` / ``admin`` — cámbialo en la página *System*.
   Esa misma página lleva una segunda cuenta opcional, *Acceso web de solo
   lectura*: ve todas las páginas pero no guarda nada, no mueve archivos y no
   transmite nada, y solo puede iniciar y detener el visor de registro de
   consola. Viene sin configurar de fábrica.
#. En *Wireless*: elige **Station** o **AP+STA**, marca **Enable** en un bloque
   de Cliente Wi-Fi, introduce SSID/contraseña, Guarda.
#. En *IGate*: pon tu **indicativo**, **SSID**, **passcode**, **host**/**puerto**
   de APRS-IS, filtro, coordenadas, símbolo, comentario.
#. En *Radio / Modem*: habilita el módem de audio, elige la modulación,
   preámbulo, ranura de tiempo TX; usa **LOOP TEST** para verificar la ruta de
   audio.
#. Reinicia (o Guarda — la mayoría de los ajustes se aplican en vivo).

Valores de fábrica destacados
=============================

.. list-table::
   :header-rows: 1
   :widths: 45 55

   * - Ajuste
     - Por defecto
   * - Modo Wi-Fi
     - AP (siempre accesible)
   * - SSID / contraseña del AP
     - ``esp32idf_APRS`` / ``esp32idf_APRS``
   * - Login web
     - ``admin`` / ``admin``
   * - Login web de solo lectura
     - sin configurar (sin cuenta de solo lectura)
   * - Frecuencia de CPU
     - 240 MHz
   * - Reloj del sistema
     - siempre UTC (TZ=UTC0). El selector de zona horaria de la página System
       (por defecto ``UTC``) solo cambia la fecha/hora local mostrada en el
       panel; las marcas de tiempo al aire siguen siendo zulú
   * - Hosts NTP
     - ``pool.ntp.org``, ``time.google.com``, ``time.cloudflare.com``
   * - IGate
     - habilitado, ``rf2inet`` activo, ``inet2rf`` inactivo
   * - Indicativo / SSID
     - ``NOCALL`` / 10, passcode ``-1``
   * - Coordenadas de la estación
     - ``0.000`` / ``0.000``; toda baliza de posición y el locator Maidenhead
       de los informes de estado se omiten mientras las coordenadas de un rol
       sigan en este valor por defecto
   * - Servidores APRS-IS
     - cuatro ranuras de failover, todas preconfiguradas a ``aprs.dprns.com`` :
       14580, con solo la ranura 1 habilitada
   * - Lista de satélites digipetidores
     - ``RS0ISS``, ``YBOX``, ``YBSAT``, ``PSAT``, ``W3ADO``, ``BJ1SI`` (hasta 8, configurable desde la web)
   * - Supresión de duplicados / caché / ventana
     - habilitada / 20 entradas / 30000 ms (configurable desde la web)
   * - Limitador de ciclo de trabajo de transmisión
     - deshabilitado; techo del 25 % de una ventana deslizante de 10 minutos
       cuando se habilita
   * - Preset de ruta 0
     - ``WIDE1-1,WIDE2-1``
   * - Selección de ruta
     - preset 0, igual para las balizas de IGate, digipetidor, tracker y meteo
   * - Digipeater
     - deshabilitado, SSID 1
   * - Tracker
     - deshabilitado, SSID 9
   * - Módem de audio
     - habilitado, 1200 Bd Bell 202
   * - Preámbulo / ranura TX
     - 300 ms / 2000 ms
   * - Persistencia CSMA
     - 63 (~25 % de probabilidad de transmitir por ranura libre)
   * - Ranura de tiempo CSMA / espera máx. con canal ocupado
     - 100 ms / 30 s
   * - Búferes de TX de RF
     - 1
   * - Respondedor de consultas
     - deshabilitado; RF activo, Internet apagado, intervalo mínimo de
       respuesta 30 s
   * - FX.25
     - desactivado
   * - PTT
     - GPIO26 (la polaridad es de compilación)
   * - Mensajería
     - habilitada, RF + INET, GPIO de alarma deshabilitado

.. danger::

   **Cambia** ``NOCALL`` **y establece un passcode real antes de transmitir.**
   Verifica que tienes licencia para la frecuencia y el ciclo de trabajo que vas
   a activar.

   **Configura también las coordenadas de la estación.** APRS no tiene una
   coordenada de "posición desconocida", así que este firmware trata el par
   por defecto ``0.000`` / ``0.000`` — la Isla Null, no la ubicación real de
   ninguna estación de radioaficionado — como "aún no configurado" y omite
   las balizas de posición de Tracker, IGate y Digipeater (y el locator
   Maidenhead de sus informes de estado) en lugar de poner una posición falsa
   en el golfo de Guinea al aire. Una baliza cuyas coordenadas siguen sin
   configurar queda en silencio en vez de transmitir; revisa el registro si
   parece que no está enviando nada.

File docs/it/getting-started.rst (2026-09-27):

.. _it-getting-started:

===========
Primi passi
===========

Prerequisiti
============

* **ESP-IDF v6.1 o successivo** (bloccato/testato su **6.1** — vedi
  ``dependencies.lock``).
* Un ESP32 con **≥ 4 MB di flash**.
* Il gestore dei componenti di IDF scarica ``joltwallet/littlefs``,
  ``espressif/cjson`` e, tramite il
  componente ``sensors_local``, ``esp-idf-lib/bmp280`` e ``esp-idf-lib/bmp180``
  (che trascinano ``i2cdev`` + ``esp_idf_lib_helpers``) automaticamente.

Compilazione e scrittura
========================

.. code-block:: bash

   . $IDF_PATH/export.sh

   cd workspace-APRS/esp32_APRS_igate

   idf.py set-target esp32          # sdkconfig arriva già con target=esp32
   idf.py build
   idf.py -p /dev/ttyUSB0 flash monitor

Compila in spagnolo o italiano invece che in inglese (vedi :ref:`it-localization`):

.. code-block:: bash

   idf.py build -DLANGUAGE=LANG_ES
   idf.py build -DLANGUAGE=LANG_IT

.. tip::

   ``sdkconfig`` arriva con ``CONFIG_COMPILER_OPTIMIZATION_DEBUG`` (``-Og``) e le
   asserzioni attive, e con ``CONFIG_COMPILER_STACK_CHECK_MODE_NORM`` per il
   canary dello stack: è la configurazione sotto cui è stato dimensionato ogni
   stack di task del progetto. Passare a
   ``CONFIG_COMPILER_OPTIMIZATION_SIZE`` (``-Os``) produce un'immagine più
   piccola con frame di stack meno profondi, ma cambia le dimensioni di frame
   rispetto a cui quei budget sono stati fissati, quindi ricontrolla i
   watermark degli stack (vedi :ref:`it-troubleshooting`) dopo averlo fatto.

Budget di memoria
=================

L'ESP32 di questo progetto non ha PSRAM, quindi ogni byte di DRAM interna che
la build riserva staticamente è un byte che l'heap non riceve mai.
``sdkconfig`` è tarato per questo, e i valori qui sotto sono deliberati:
alzarne uno qualsiasi abbassa la cifra *Min free heap* del pannello.

.. list-table::
   :header-rows: 1
   :widths: 44 10 46

   * - Opzione
     - Valore
     - Perché
   * - ``CONFIG_ESP_WIFI_STATIC_RX_BUFFER_NUM``
     - 6
     - ~1,6 KB ciascuno, allocati in ``esp_wifi_init()`` e trattenuti finché il
       Wi-Fi non viene de-inizializzato. Sei coincide con
       ``CONFIG_ESP_WIFI_RX_BA_WIN``, che è il minimo richiesto da AMPDU RX.
   * - ``CONFIG_ESP_WIFI_DYNAMIC_RX_BUFFER_NUM`` / ``..._TX_...``
     - 12 / 24
     - Limita il picco di heap richiesto dal driver Wi-Fi. Il traffico APRS è
       di qualche centinaio di byte al minuto; la banda che questi buffer
       comprano non viene mai usata.
   * - ``CONFIG_LWIP_TCP_SND_BUF_DEFAULT`` / ``CONFIG_LWIP_TCP_WND_DEFAULT``
     - 5760
     - Quattro MSS (``CONFIG_LWIP_TCP_MSS`` è 1440) per direzione e per
       connessione. L'unico trasferimento prolungato è il caricamento di
       un'immagine OTA, che con questa finestra satura comunque una LAN.
   * - ``max_open_sockets`` in ``web_server_start()``
     - 3
     - httpd prende questo numero più 3 socket propri dal pool di
       ``CONFIG_LWIP_MAX_SOCKETS`` (16). Il resto della quota serve al
       collegamento APRS-IS, al DNS, a SNTP e al client HTTPS del bot
       Telegram per restare attivi mentre qualcuno naviga le pagine di
       amministrazione.
   * - Server HTTPS, bundle di certificati, Wi-Fi Enterprise
     - disattivati
     - L'amministrazione web è HTTP in chiaro e il collegamento APRS-IS è TCP
       in chiaro, e nulla si mette mai in ascolto di TLS:
       ``CONFIG_ESP_HTTPS_SERVER_ENABLE``,
       ``CONFIG_MBEDTLS_CERTIFICATE_BUNDLE`` e
       ``CONFIG_ESP_WIFI_ENTERPRISE_SUPPORT`` sono tutti disattivati in
       ``sdkconfig``. Un percorso di codice apre però TLS, come *client*: il bot
       Telegram parla con ``api.telegram.org`` via HTTPS attraverso
       ``esp_http_client``/``esp_tls``. Con il bundle di certificati
       disattivato, verifica il server rispetto a un file PEM che l'operatore
       carica sulla partizione di archiviazione
       (``CONFIG_TELEGRAM_BOT_CERT_PATH``, ``/storage/telegram_certificate.pem``
       di default) invece che rispetto a uno store di radici compilato
       nell'immagine — pochi kilobyte di flash al posto delle decine del
       bundle. Una stazione che lascia il bot spento non alloca nulla di tutto
       questo.
   * - ``CONFIG_MBEDTLS_SSL_IN_CONTENT_LEN`` / ``..._OUT_CONTENT_LEN``
     - 8192 / 2048
     - I buffer di record, allocati per sessione TLS, quindi una stazione con il
       bot spento non paga nulla per essi. L'ingresso richiede la cifra maggiore
       perché il server sceglie la propria dimensione di record e lo standard
       consente fino a 16384; l'uscita è una scelta di questo dispositivo e le
       sue richieste sono piccole. ``CONFIG_MBEDTLS_DYNAMIC_BUFFER`` è attivo,
       quindi anche una sessione viva tiene i buffer completi solo mentre ci
       sono record realmente in transito.
   * - mbedTLS stesso
     - abilitato
     - La crittografia Wi-Fi ne ha bisogno comunque, quindi
       ``CONFIG_MBEDTLS_TLS_ENABLED`` e le sue opzioni annidate
       ``_SERVER``/``_CLIENT`` restano ai valori predefiniti. L'autenticazione
       HTTP Basic continua a decodificare la propria coppia di credenziali con
       un piccolo decodificatore locale RFC 4648
       (``components/webconfig/include/web_base64.h``) invece di
       ``mbedtls_base64_decode()``, quindi ``webconfig`` non dichiara alcuna
       dipendenza propria da mbedTLS; ``esp_wifi``/``esp_netif``/``lwip``
       trascinano mbedTLS in modo transitivo per la crittografia WPA2, che non è
       influenzata da nessuna di queste impostazioni.

.. note::

   Da ESP-IDF v6.0 il port di mbedTLS chiama ``psa_crypto_init()`` da un hook
   di avvio di sistema, quindi PSA Crypto è attivo in ogni build che collega
   mbedTLS, questa compresa, indipendentemente da
   ``CONFIG_MBEDTLS_TLS_ENABLED``. Questo, insieme alla maggiore impronta
   statica di mbedTLS 4.x, è il motivo per cui lo stesso firmware riporta meno
   heap libero sotto v6.x rispetto a v5.2 con una configurazione per il resto
   identica. Il comportamento è stato introdotto in v6.0 ed è invariato nella
   v6.1 con cui questo progetto compila ora.

Primo avvio
===========

#. Su una partizione nuova, LittleFS si auto-formatta e ``app_config_load()``
   scrive un file di configurazione per funzionalità con i valori di fabbrica.
#. L'ESP32 si avvia come **AP Wi-Fi**: SSID ``esp32idf_APRS``, password
   ``esp32idf_APRS``, canale 1, WPA2-PSK, max 4 client.
#. Uniscici e naviga al dispositivo (predefinito ``http://192.168.4.1/``).
#. **Accedi:** ``admin`` / ``admin`` — cambialo nella pagina *System*. La
   stessa pagina porta un secondo account facoltativo, *Accesso web in sola
   lettura*: vede ogni pagina ma non salva nulla, non sposta file e non
   trasmette nulla, e può solo avviare e fermare il visore del registro di
   console. Di fabbrica non è impostato.
#. In *Wireless*: scegli **Station** o **AP+STA**, spunta **Enable** in un blocco
   Client Wi-Fi, inserisci SSID/password, Salva.
#. In *IGate*: imposta il tuo **indicativo**, **SSID**, **passcode**,
   **host**/**porta** APRS-IS, filtro, coordinate, simbolo, commento.
#. In *Radio / Modem*: abilita il modem audio, scegli la modulazione, il
   preambolo, lo slot temporale TX; usa **LOOP TEST** per verificare il percorso
   audio.
#. Riavvia (o Salva — la maggior parte delle impostazioni si riapplica in tempo
   reale).

Valori di fabbrica notevoli
===========================

.. list-table::
   :header-rows: 1
   :widths: 45 55

   * - Impostazione
     - Predefinito
   * - Modalità Wi-Fi
     - AP (sempre raggiungibile)
   * - SSID / password AP
     - ``esp32idf_APRS`` / ``esp32idf_APRS``
   * - Login web
     - ``admin`` / ``admin``
   * - Login web in sola lettura
     - non impostato (nessun account di sola lettura)
   * - Frequenza CPU
     - 240 MHz
   * - Orologio di sistema
     - sempre UTC (TZ=UTC0). Il selettore di fuso orario della pagina System
       (default ``UTC``) cambia solo la data/ora locale mostrata nella
       dashboard; i timestamp in onda restano zulu
   * - Host NTP
     - ``pool.ntp.org``, ``time.google.com``, ``time.cloudflare.com``
   * - IGate
     - abilitato, ``rf2inet`` attivo, ``inet2rf`` inattivo
   * - Indicativo / SSID
     - ``NOCALL`` / 10, passcode ``-1``
   * - Coordinate della stazione
     - ``0.000`` / ``0.000``; ogni beacon di posizione e il locator Maidenhead
       dei report di stato vengono omessi finché le coordinate di un ruolo
       restano su questo valore predefinito
   * - Server APRS-IS
     - quattro slot di failover, tutti preimpostati a ``aprs.dprns.com`` :
       14580, con il solo slot 1 abilitato
   * - Elenco digipeater satellitari
     - ``RS0ISS``, ``YBOX``, ``YBSAT``, ``PSAT``, ``W3ADO``, ``BJ1SI`` (fino a 8, configurabile dal web)
   * - Soppressione duplicati / cache / finestra
     - abilitata / 20 voci / 30000 ms (configurabile dal web)
   * - Limitatore di duty cycle di trasmissione
     - disabilitato; tetto del 25 % di una finestra scorrevole di 10 minuti
       quando abilitato
   * - Preset di percorso 0
     - ``WIDE1-1,WIDE2-1``
   * - Selezione del percorso
     - preset 0, uguale per i beacon IGate, digipeater, tracker e meteo
   * - Digipeater
     - disabilitato, SSID 1
   * - Tracker
     - disabilitato, SSID 9
   * - Modem audio
     - abilitato, 1200 Bd Bell 202
   * - Preambolo / slot TX
     - 300 ms / 2000 ms
   * - Persistenza CSMA
     - 63 (~25 % di probabilità di trasmettere per slot libero)
   * - Slot temporale CSMA / attesa max. canale occupato
     - 100 ms / 30 s
   * - Buffer di TX RF
     - 1
   * - Risponditore di query
     - disabilitato; RF attivo, Internet spento, intervallo minimo di
       risposta 30 s
   * - FX.25
     - disattivato
   * - PTT
     - GPIO26 (la polarità è di compilazione)
   * - Messaggistica
     - abilitata, RF + INET, GPIO di allarme disabilitato

.. danger::

   **Cambia** ``NOCALL`` **e imposta un passcode reale prima di trasmettere.**
   Verifica di essere autorizzato per la frequenza e il ciclo di lavoro che stai
   per attivare.

   **Imposta anche le coordinate della stazione.** APRS non ha una coordinata
   di "posizione sconosciuta", perciò questo firmware tratta la coppia
   predefinita ``0.000`` / ``0.000`` — Null Island, non la sede reale di
   alcuna stazione radioamatoriale — come "non ancora configurata" e omette i
   beacon di posizione di Tracker, IGate e Digipeater (e il locator
   Maidenhead dei loro report di stato) invece di mettere in aria una
   posizione falsa nel golfo di Guinea. Un beacon le cui coordinate non sono
   ancora impostate resta silenzioso invece di trasmettere; controlla il log
   se sembra non inviare nulla.

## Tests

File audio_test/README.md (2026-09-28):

# esp32idf_APRS audio test bench — user manual

🌐 **English** · [Español](README_es.md) · [Italiano](README_it.md)

Test the AFSK 1200 baud APRS receiver of the **esp32idf_APRS** firmware with
**real APRS traffic recorded off the air**, and measure how many packets the
ESP32 decodes compared with a reference decoder (**multimon-ng**).

---

## Contents

1. [What this test does](#1-what-this-test-does)
2. [What you need](#2-what-you-need)
3. [Build the audio cable (hardware)](#3-build-the-audio-cable-hardware)
4. [Prepare the ESP32 (firmware settings)](#4-prepare-the-esp32-firmware-settings)
5. [Prepare the PC](#5-prepare-the-pc)
6. [Get audio files with real APRS traffic](#6-get-audio-files-with-real-aprs-traffic)
7. [Set the audio level](#7-set-the-audio-level) ([auto-volume calibration](#71-automatic-volume-calibration), [normalisation](#72-normalisation-and-gains-above-10))
8. [First run: check the whole chain with synthetic packets](#8-first-run-check-the-whole-chain-with-synthetic-packets)
9. [Run the real test](#9-run-the-real-test)
10. [Command-line reference](#10-command-line-reference) ([language](#101-language), [graphical interface](#102-graphical-interface---gui), [self-test](#103-self-test---selftest))
11. [Reading the results](#11-reading-the-results)
12. [How packets are compared](#12-how-packets-are-compared)
13. [Suggested test plan with the WA8LMF tracks](#13-suggested-test-plan-with-the-wa8lmf-tracks)
14. [`gen_test_wav.py` in detail](#14-gen_test_wavpy-in-detail)
15. [Troubleshooting](#15-troubleshooting)
16. [Limitations](#16-limitations)
17. [Cheat sheet](#17-cheat-sheet)
18. [Glossary](#18-glossary)
19. [PC replay of the receiver (`rx_replay`, `rx_diag.py`)](#19-pc-replay-of-the-receiver-rx_replay-rx_diagpy)

---

## 1. What this test does

The ESP32 firmware decodes APRS packets from an audio signal on its ADC input
and prints every packet it decodes on its serial console (`RX: SRC>DST,PATH:payload`).
The question is: **of all the packets that are really in the audio, how many did
the ESP32 decode, and did it decode them correctly?**

The program answers it by feeding the **same audio to two decoders at the same
time**:

```
                       ┌─► sox (resample to 22050 Hz mono) ─► multimon-ng ──────────► packets A  (reference)
                       │                                                                  │
 WAV file ─────────────┤                                                                  ▼
 (real APRS traffic)   │                                                          test_aprs_wavs.py
                       │                                                          compares A and B
                       │                                                                  ▲ 
                       └─► play ─► PC sound card ─► RV1 + C1 ─► ESP32 ADC (GPIO33)        │
                                                                   │                      │ 
                                                            ESP32 AFSK modem              │
                                                                   │                      │
                                                             console log ─► USB serial ───┴► packets B
```

* **multimon-ng** is a well-known software decoder. Whatever it decodes from the
  file is used as the *list of packets that are really there*.
* The **ESP32** hears the same audio through the sound card and a small
  attenuator/coupling circuit, and reports what it decoded on the serial port.
* For every packet multimon-ng decodes, the program looks for the same packet in
  the ESP32 log. It prints the packet together with a verdict:
  **OK**, **DIFFERENT** or **NOT DECODED**.
* At the end it prints a summary: total packets, percent decoded correctly,
  percent decoded with different content, percent missing.

**Any WAV file with real APRS traffic (AFSK 1200 baud) can be used** — a recording
from a radio, from an SDR, or a published test track. Section 6 explains where to
get good ones and proposes the free **WA8LMF TNC test tracks**.

The test is **receive-only**: nothing is transmitted, and nothing needs to be
connected from the ESP32 back to the PC.

---

## 2. What you need

### Hardware

| Item | Notes |
|---|---|
| ESP32 board running the esp32idf_APRS firmware | Powered and connected to the PC by USB (this USB link is also the serial console). |
| PC with a sound card output | Headphone or line-out. A cheap dedicated USB sound card is a good idea (see section 5). |
| Audio cable, 3.5 mm plug | Tip = left channel, sleeve = ground. Either channel works: the program sends the same audio to both. |
| RV1: 2 kΩ multi-turn trimmer | Sets the level. Multi-turn allows fine adjustment. **Optional** — section 3.1 gives a fixed-resistor alternative if you don't have a trimmer. |
| C1: capacitor, 10 nF ceramic or film (or 1 µF for flat recordings only) | Section 3, *Component rules*, explains the choice. A 1 µF electrolytic is fine (mind the polarity!), rated 10 V or more. |
| Jumper wires | |

### Software (Linux)

The program is written for **Linux with ALSA** and needs:

| Software | Why | Install (Debian/Ubuntu) |
|---|---|---|
| Python 3.7+ | runs the program | usually already installed |
| pyserial | reads the ESP32 console | `sudo apt install python3-serial` |
| multimon-ng | reference decoder | `sudo apt install multimon-ng` |
| sox (with `play`) | plays the WAV and converts audio | `sudo apt install sox libsox-fmt-all` |
| alsa-utils | `aplay -l` to find the sound card | `sudo apt install alsa-utils` |
| coreutils (`stdbuf`) | **strongly recommended.** Without it multimon-ng's output is block-buffered on the pipe, its packets arrive in bursts and are timestamped late, which produces spurious *NOT DECODED* verdicts. The program warns at start-up when it is missing. | usually already installed |
| python3-tk | only for the graphical front-end (`--gui`, section 10.2) | `sudo apt install python3-tk` |

Install everything at once:

```bash
sudo apt install python3-serial multimon-ng sox libsox-fmt-all alsa-utils coreutils python3-tk
```

(If you prefer pip: `pip install pyserial`, inside a virtual environment on
recent distributions.)

---

## 3. Build the audio cable (hardware)

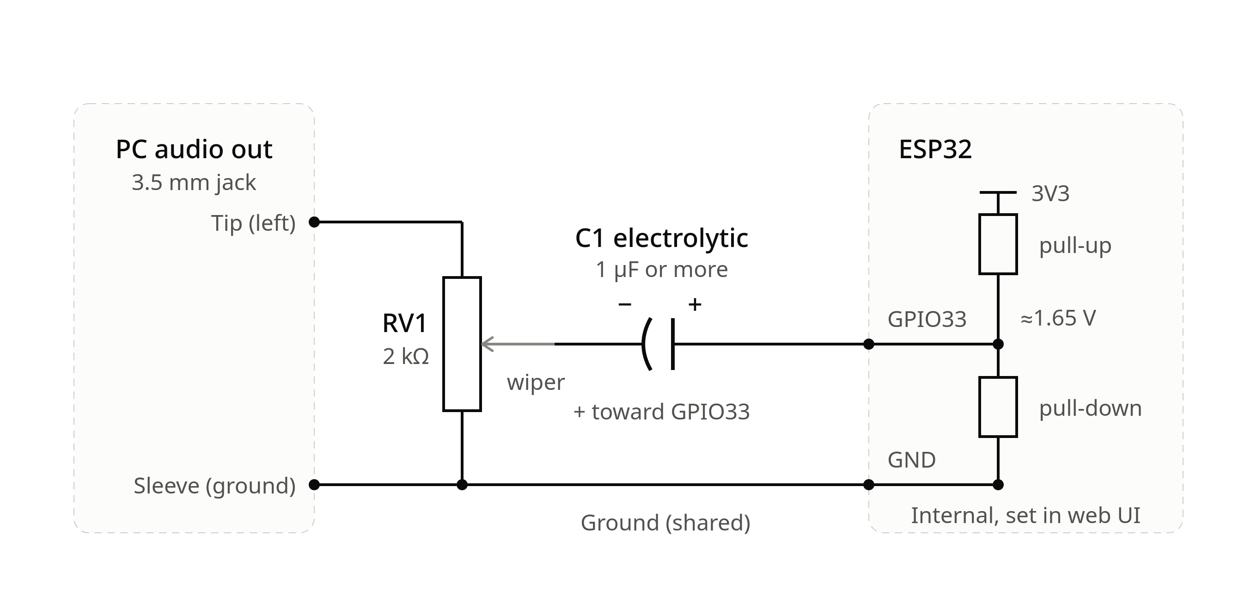
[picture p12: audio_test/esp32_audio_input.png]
Minimal audio input circuit


### What the circuit does

* The PC sound card output is a signal that swings **both above and below 0 V**
  (it can reach roughly ±1 V or more). The ESP32 ADC only accepts **0 to 3.3 V**
  and must never see a negative voltage.
* **RV1** (the trimmer) is a **volume control / voltage divider** across the PC
  output. Its wiper takes only a fraction of the signal.
* **C1** (the capacitor) **blocks DC** and passes the audio. On the ESP32 side it
  connects to GPIO33, whose DC level is set by the ESP32 itself.
* The ESP32 can bias its own ADC pin: it connects the pad's internal **pull-up
  and pull-down resistors** so that the pin rests at about **1.65 V** (half of
  3.3 V). The audio then rides on that DC level. This is the firmware option
  **ADC input self-bias** (section 4). That is why the whole circuit needs no
  resistors of its own.
* **Ground** of the jack (sleeve) goes to ESP32 **GND**.

### Wiring, step by step

Power everything off first.

1. **Jack tip** → top end of **RV1**.
2. **Jack sleeve** → bottom end of **RV1** **and** ESP32 **GND**.
3. **RV1 wiper** (the middle terminal) → **C1, minus (−) side**.
4. **C1, plus (+) side** → ESP32 **GPIO33**.

### Capacitor polarity (important if C1 is an electrolytic)

An electrolytic capacitor has a **polarity**. GPIO33 rests at about 1.65 V and the
PC side rests at about 0 V, so the ESP32 side is the positive one:

| Lead of C1 | Goes to | How to recognize it |
|---|---|---|
| **+** (plus) | **GPIO33** (ESP32) | the **longer** lead of a new part |
| **−** (minus) | **RV1 wiper** (PC side) | the lead under the **stripe with minus signs** printed on the can |

In the drawing the straight plate (marked +) faces GPIO33 and the curved plate
(marked −) faces the trimmer wiper. Connecting it backwards makes it leak and
add noise. A ceramic or film 1 µF has no polarity, if you have one.

### Component rules

* **C1 is 10 nF for de-emphasized recordings, and works for flat ones too.** C1
  and the ESP32's self-bias resistors (about 22 kΩ, varying from part to part)
  form a high-pass filter. With **10 nF** its corner is about 700 Hz (roughly
  500–900 Hz): a de-emphasized recording such as WA8LMF track 2 carries bass
  well above the tones, and without this filter that bass fills the ADC's
  range and leaves the tones only a few counts above the converter's noise.
  The high-pass on the Radiomodem page cannot recover that, because it runs
  after the converter. The filter also takes 1.3 dB off the 1200 Hz tone and
  0.4 dB off the 2200 Hz tone, which de-emphasized audio welcomes; on a flat
  recording it makes no measurable difference. A ceramic or film 10 nF has no
  polarity. **1 µF** (corner about 7 Hz) suits flat recordings only; 100 nF
  (about 70 Hz) behaves like 1 µF.
* **The trimmer must be *before* the capacitor**, as drawn. If RV1 were placed
  between the capacitor and the pin, its lower leg would tie GPIO33 to ground and
  destroy the bias.
* **RV1 = 2 kΩ** is a low value. It presents a 2 kΩ load to the PC output, which
  most headphone-type outputs handle easily. If the sound from the PC output
  becomes distorted, use a 10 kΩ trimmer instead (the firmware documentation
  recommends 10 kΩ mainly to keep the load on the source light).
* **The ESP32 pin has no protection diodes here.** RV1 is the only thing limiting
  what reaches GPIO33. Before connecting, set the PC volume low and RV1 near the
  ground end (section 7). A headphone output at full volume can swing well beyond
  the 0 – 3.3 V the pin tolerates.
* The firmware's reference schematic (the full-size RX interface in the project
  documentation) adds two **clamp diodes, D1/D2**, that hold the ADC pin inside
  the supply rails, plus a small R/C snubber. This minimal circuit leaves them out
  on purpose: the firmware then relies on the **Warn on receive over-range**
  option instead. If you will leave the bench connected for a long time, or use a
  strong source, consider adding the clamp diodes as drawn in that schematic.
* Only **GPIO32 and GPIO33** can use the built-in self-bias. The default input of
  the firmware is GPIO33; if you changed the ADC pin in your build, use that pin
  (it must be GPIO32 or GPIO33 for this circuit).

### 3.1 Alternative: fixed resistors instead of the trimmer

If you don't have a 2 kΩ trimmer, RV1 can be replaced with **two fixed
resistors** wired as a permanent voltage divider. You lose the ability to turn a
knob, but section 7.1 shows how the program's own **auto-volume calibration**
makes up for that in software.

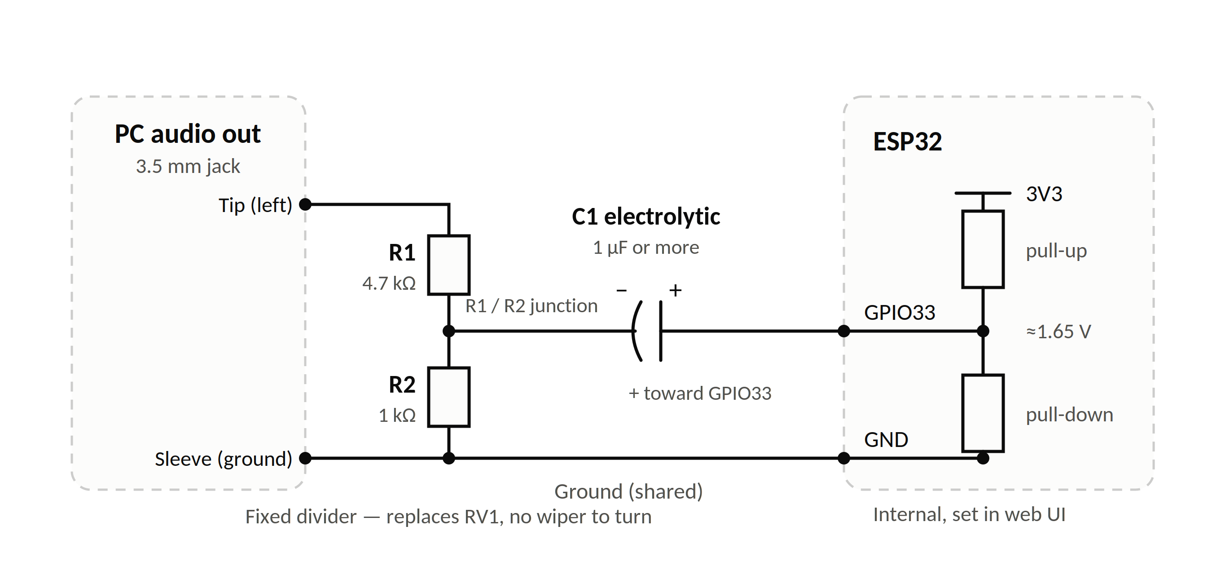
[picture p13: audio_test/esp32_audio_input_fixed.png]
Fixed-resistor alternative to RV1


More plainly: **R1** goes from the jack **tip** to a middle node; **R2** goes
from that same middle node to the jack **sleeve** (ground, tied to ESP32 GND).
The middle node — where R1 and R2 meet — replaces the trimmer's wiper and goes
to **C1's minus (−) side**, exactly as in the wiring steps above. Everything
else (C1, the connection to GPIO33, the shared ground) stays the same.

* **Suggested starting values: R1 = 4.7 kΩ, R2 = 1 kΩ.** This divides the PC
  output by about 5.7×, presenting a light ≈5.7 kΩ load. It is only a starting
  point: line-out levels vary a lot between sound cards, so the actual voltage
  reaching GPIO33 still depends on the PC's own volume setting.
* **This divider is fixed — it cannot be nudged like a trimmer.** Use the PC's
  volume control for the coarse setting (as in section 7), and let the
  program's `--volume` software gain (applied automatically by the auto-volume
  calibration described in section 7.1, unless you pass `--no_auto_volume`)
  take care of fine-tuning. That is precisely the situation the calibration
  feature is meant for.
* If, even at low PC volume, the level is always too high (over-range) or
  always too low (raw values glued to 0 or 4095, `--volume` alone can't fix
  it), swap in a divider with more or less attenuation — for example R1 = 10 kΩ
  / R2 = 1 kΩ (more attenuation) or R1 = 2.2 kΩ / R2 = 1 kΩ (less) — and
  re-check with RX LEVEL (section 7) or another auto-volume run.
* A trimmer is still the more convenient choice if you expect to reuse the
  bench with different sound cards or recordings: it lets you fix the analog
  level once, in hardware, rather than depending on software gain every time.

---

## 4. Prepare the ESP32 (firmware settings)

Join the ESP32's Wi-Fi access point (factory default SSID `esp32idf_APRS`,
password `esp32idf_APRS`) and open `http://192.168.4.1/` in a browser (factory
login `admin` / `admin`, unless you changed it). The interface may be shown in
several languages; English labels are given below.

### 4.1 Audio settings — *Radiomodem* page

| Label | Set to |
|---|---|
| Enable audio ADC/DAC modem | **ON** |
| Audio interface → **ADC input self-bias** | **ON** (this is what makes the capacitor-coupled circuit work) |
| Audio interface → **Warn on receive over-range** | **ON** (warns when the signal is too strong; the circuit has no clamp diodes) |

Save (reboot the ESP32 if the page asks for it).

### 4.2 ⚠ Safety settings — do this BEFORE playing any recorded traffic

Recorded off-air traffic contains **real callsigns and real positions**. The
WA8LMF test tracks even contain his own callsign in the beacons, and he
explicitly warns that if they are igated they create false reports of where he
was decades ago. Your ESP32 is an **IGate/digipeater** firmware, so make sure
that nothing decoded from a recording can leave the ESP32:

| Page | Label | Set to |
|---|---|---|
| IGate | **Enable IGate** | **OFF** |
| IGate | **RF to Internet** | **OFF** |
| IGate | **Duplicate Suppression** | **OFF** |
| Digipeater | **Enable Digipeater** | **OFF** |
| Beacon pages | beacon / tracker / weather / telemetry enables | **OFF** |

> **⚠ IGate Duplicate Suppression must be disabled.** This firmware feature
> recognises a packet with the same source/destination/payload seen again
> within a short interval and suppresses the repeat so it is not gated (and,
> depending on firmware version, not logged) twice. Several of the test WAVs —
> most importantly **WA8LMF track 3 (section 6.2), 100 identical Mic-E bursts
> only 3 seconds apart** — consist of the *same* packet repeated many times on
> purpose, precisely to measure the ESP32's raw decode rate. With duplicate
> suppression ON, the repeats after the first would never print a fresh `RX:`
> line, and the bench would score every one of them as **NOT DECODED** even
> though the demodulator decoded it correctly. Turn it OFF before running any
> test in this bench.

Extra safety, recommended:

* Leave the ESP32 in its factory **Wi-Fi AP-only** mode (no Station/client
  connection) so it has **no Internet path at all** while testing.
* **Do not connect a transmitter or radio** to the ESP32 during the test.

The receive lines you need on the console (`RX: …`) are still printed with the
IGate disabled: the documentation states that a receive-only station's log is
narrowed by the filters, not emptied. If you ever see no `RX:` lines with the
IGate off, see [Troubleshooting](#15-troubleshooting).

### 4.3 Log settings

| Label | Set to | Why |
|---|---|---|
| IGate page → **Log after filters** | **OFF** (the default) | If ON, the console only prints packets that pass your IGate filters, and every filtered packet would be counted as *NOT DECODED*. |

The console log level must be **INFO** (the firmware default), which is the level
that prints the `RX:` lines.

> **Firmware requirement:** the firmware must **escape non-printable bytes — above
> all LF (0x0A) — before it logs the `RX:` line**. The bench splits the console
> stream on LF only (splitting on CR would truncate payloads that legitimately
> contain CR), so a raw LF inside an information field cuts the console line in two
> and the frame is scored as a content mismatch even though the demodulator was
> right. Mic-E, telemetry and binary-ish payloads are the ones that hit this.

### 4.4 The console

The ESP32 USB port is also the serial console: **115200 baud, 8 data bits, no
parity, 1 stop bit (8N1)**. Only one program can use the serial port at a time,
so **close** `idf.py monitor`, minicom, screen, PuTTY, etc. before running the test.

---

## 5. Prepare the PC

### 5.1 Serial port permission

On Debian/Ubuntu your user must be in the `dialout` group:

```bash
sudo usermod -aG dialout $USER
# then log out and log in again
```

Find the port of the ESP32:

```bash
ls /dev/ttyUSB* /dev/ttyACM* 2>/dev/null
```

The program defaults to `/dev/ttyUSB0`; use `--serial_port` for another one.

### 5.2 Find the sound card that feeds the ESP32

```bash
./test_aprs_wavs.py --list_audio      # same as: aplay -l
```

Example output:

```
card 0: PCH [HDA Intel PCH], device 0: ALC3246 Analog [ALC3246 Analog]
card 1: Device [USB Audio Device], device 0: USB Audio [USB Audio]
```

The USB sound card above is **card 1, device 0**, which is the ALSA name
`hw:1,0`. You will pass it as `--audio_device hw:1,0`. Without `--audio_device`
the system default output is used.

### 5.3 Sound-card advice (it matters for the results)

* **Use a dedicated USB sound card** if possible. A cheap one is fine. It keeps
  desktop sounds out of the test.
* **Never let system sounds play** during a test: a notification beep goes
  through the same output and into the ESP32 input, and can corrupt a packet.
  Disable notification sounds, or use a dedicated card that the desktop does not use.
* Turn off any **audio "enhancements"**, equalizers, loudness or volume
  normalization in the sound settings.
* Set the mixer volume **once** and don't touch it during a run. The audio level
  at the ESP32 depends on it (section 7). `alsamixer` (choose the sound card
  with F6) is the usual tool.
* Play **lossless** audio only (WAV/FLAC). WA8LMF notes that lossy compression
  such as MP3 mangles the data waveforms, and that low-cost software-based PC
  sound systems can introduce timing errors or a wrong playback sample rate. If
  results look strange, a different sound card is the first thing to try.
* Do not use Bluetooth audio.

---

## 6. Get audio files with real APRS traffic

### 6.1 What files can be used

**Any WAV file that contains APRS traffic at 1200 baud AFSK** (the normal VHF APRS
modulation, Bell 202 tones 1200/2200 Hz). The program accepts any:

* sample rate (8000, 11025, 22050, 44100, 48000 Hz …),
* mono or stereo,
* bit depth (8, 16, 24 bit).

`sox` converts the audio for multimon-ng (22050 Hz, mono, 16 bit) automatically.

Rules:

* If the WAV is **stereo**, only its **left channel** is sent to the ESP32 (the
  reference decoder receives the mix of both). Convert stereo recordings whose two
  channels differ to mono first: `sox in.wav -c 1 mono.wav`.
* The extension must be `.wav` (`.WAV` and `.Wav` are accepted too). The program
  looks only at those files **directly inside** the directory you give it (it does
  not search subdirectories). FLAC, MP3 etc. must be converted first (section 6.3).
* The audio must be **lossless** and have **no clipping**.
* The file can be of any length. Files are processed **one after another, in
  alphabetical order** (upper- and lower-case names sort together), and each is played in **real time** (a 25-minute file takes
  25 minutes).
* Best audio: taken straight from a receiver's **discriminator / "data" output**.
  Audio taken from the **speaker** is de-emphasized; it also works, but decoding
  is somewhat different. Testing both is useful.

### 6.2 Recommended source: the WA8LMF TNC test tracks

**WA8LMF** publishes, on
**<http://www.wa8lmf.net/TNCtest/>**, a free "TNC Test CD" built to compare 1200
baud packet TNCs "under fire" in real conditions. It contains real off-air
recordings, which makes it an ideal test set for this bench.

**Two versions are offered; both have identical audio:**

| Version | File | Size | Format |
|---|---|---|---|
| 2.0 (recommended) | <http://www.wa8lmf.net/TNCtest/TNC_Test_2.iso> | ≈ 250 MB | CD-ROM image with lossless **FLAC** files |
| 1.1 | <http://www.wa8lmf.net/TNCtest/TNC_Test_CD_Ver-1.1.zip> | ≈ 530 MB | Audio-CD image (BIN/CUE) — needs to be burned or ripped |

Use **version 2.0**: the audio is already in files.

**The tracks** (as described on that page):

| Track | What it is | Length | Packets | Use it here? |
|---|---|---|---|---|
| **1** | Real traffic on **144.39 MHz, Los Angeles**, at the afternoon rush hour: the channel is saturated. 40 minutes of activity with pauses removed, compressed to ≈ 25 minutes. Discriminator audio, **not** de-emphasized. Has over- and under-deviated signals, collisions, back-to-back packets with almost no gap, raw NMEA trackers, TinyTraks, CW ID on packet … | ≈ 25 min | many (hundreds) | **Yes — the main stress test** |
| **2** | Real traffic recorded **de-emphasized** (simulates audio taken from a radio's speaker / volume control). WB2OSZ's analysis of the CD describes it as a flat transmitter heard through a de-emphasizing receiver, with a sharp notch at 3100 Hz, and compares it with track 1 segment by segment. In version 2.0 its file is named `02_100-Mic-E-Bursts-DE-emphasized`; take the packet count from Direwolf rather than from the name. | see Direwolf | many | **Yes** — the speaker-audio test; run it on its own (`--wav_files`) with `--flat_audio off` or `auto` |
| **3** | A **Kenwood D700 Mic-E** position report, clean, from a service monitor, copied 100 times: **20 bursts per minute for 5 minutes = exactly 100 identical packets**. | ≈ 5 min | exactly **100** | **Yes — gives an exact percentage** |
| **4** | 25 minutes of **one mobile D700 beaconing every 12 s** while driving, on a quiet channel, 8–10 miles from the receiver: flutter, multipath, weak signals. The page says several packets are audible but fail to decode with the AGW packet engine. | ≈ 25 min | up to ≈ 125 sent | **Yes — weak-signal test** |
| 5, 6, 7 | KPC3+ "CAL" alternating 1200/2200 Hz tones: flat, de-emphasized, pre-emphasized. For TNC *alignment* (tone level ratio). | ≈ 1 min each | **0** | **No** — they contain no packets. Keep them out of the test directory. |

Also from the page: each track begins and ends with DTMF cue tones (track 1 starts with
"1" and ends with "6", track 2 with "2"/"7", and so on). They are harmless.

> **⚠ WA8LMF's warning:** *do not play these tracks over the air.* His callsign is
> embedded in the beacons and they would be igated, creating false position reports.
> **This bench never transmits**, but keep the ESP32 IGate disabled as described in
> section 4.2 for exactly the same reason.

These tracks are third-party material published by WA8LMF for testing; they are not
distributed with this bench. Credit the source if you publish results.

### 6.3 Download, extract and convert (Version 2.0)

```bash
mkdir -p ~/audio_test && cd ~/audio_test

# 1) download (≈ 250 MB)
wget http://www.wa8lmf.net/TNCtest/TNC_Test_2.iso

# 2) open the ISO — either mount it (needs sudo) ...
mkdir -p TNC_Test_2
sudo mount -o loop,ro TNC_Test_2.iso TNC_Test_2
#    ... or extract it without root:  sudo apt install p7zip-full
# 7z x TNC_Test_2.iso -oTNC_Test_2
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

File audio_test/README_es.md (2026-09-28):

# Banco de pruebas de audio de esp32idf_APRS — manual de usuario

🌐 [English](README.md) · **Español** · [Italiano](README_it.md)

Pruebe el receptor APRS AFSK de 1200 baudios del firmware **esp32idf_APRS** con
**tráfico APRS real grabado del aire** y mida cuántos paquetes decodifica el
ESP32 en comparación con un decodificador de referencia (**multimon-ng**).

---

## Contenido

1. [Qué hace esta prueba](#1-qué-hace-esta-prueba)
2. [Qué necesita](#2-qué-necesita)
3. [Construir el cable de audio (hardware)](#3-construir-el-cable-de-audio-hardware)
4. [Preparar el ESP32 (ajustes del firmware)](#4-preparar-el-esp32-ajustes-del-firmware)
5. [Preparar la PC](#5-preparar-la-pc)
6. [Obtener archivos de audio con tráfico APRS real](#6-obtener-archivos-de-audio-con-tráfico-aprs-real)
7. [Ajustar el nivel de audio](#7-ajustar-el-nivel-de-audio) ([calibración automática de volumen](#71-calibración-automática-de-volumen), [normalización](#72-normalización-y-ganancias-por-encima-de-10))
8. [Primera ejecución: verificar toda la cadena con paquetes sintéticos](#8-primera-ejecución-verificar-toda-la-cadena-con-paquetes-sintéticos)
9. [Ejecutar la prueba real](#9-ejecutar-la-prueba-real)
10. [Referencia de la línea de comandos](#10-referencia-de-la-línea-de-comandos) ([idioma](#101-idioma), [interfaz gráfica](#102-interfaz-gráfica---gui), [autoprueba](#103-autoprueba---selftest))
11. [Interpretar los resultados](#11-interpretar-los-resultados)
12. [Cómo se comparan los paquetes](#12-cómo-se-comparan-los-paquetes)
13. [Plan de pruebas sugerido con las pistas de WA8LMF](#13-plan-de-pruebas-sugerido-con-las-pistas-de-wa8lmf)
14. [`gen_test_wav.py` en detalle](#14-gen_test_wavpy-en-detalle)
15. [Solución de problemas](#15-solución-de-problemas)
16. [Limitaciones](#16-limitaciones)
17. [Hoja de referencia rápida](#17-hoja-de-referencia-rápida)
18. [Glosario](#18-glosario)
19. [Replay en PC del receptor (`rx_replay`, `rx_diag.py`)](#19-replay-en-pc-del-receptor-rx_replay-rx_diagpy)

---

## 1. Qué hace esta prueba

El firmware del ESP32 decodifica paquetes APRS a partir de una señal de audio en
su entrada ADC e imprime cada paquete decodificado en su consola serie
(`RX: SRC>DST,PATH:payload`). La pregunta es: **de todos los paquetes que
realmente hay en el audio, ¿cuántos decodificó el ESP32 y los decodificó
correctamente?**

El programa lo responde enviando **el mismo audio a dos decodificadores al mismo
tiempo**:

```
                       ┌─► sox (remuestreo a 22050 Hz, mono) ─► multimon-ng ───────────► paquetes A  (referencia)
                       │                                                                            │
 Archivo WAV ──────────┤                                                                            ▼
 (tráfico APRS real)   │                                                                   test_aprs_wavs.py
                       │                                                                     compara A y B
                       │                                                                            ▲
                       └─► play ─► placa de sonido de la PC ─► RV1 + C1 ─► ADC del ESP32 (GPIO33)   │
                                                                   │                                │
                                                          módem AFSK del ESP32                      │
                                                                   │                                │
                                                           log de consola ─► serie USB ─────────────┴► paquetes B
```

* **multimon-ng** es un conocido decodificador por software. Lo que decodifica
  del archivo se usa como *la lista de paquetes que realmente están allí*.
* El **ESP32** oye el mismo audio a través de la placa de sonido y de un pequeño
  circuito atenuador/de acoplamiento, e informa lo que decodificó por el puerto serie.
* Para cada paquete que decodifica multimon-ng, el programa busca el mismo paquete
  en el log del ESP32. Imprime el paquete junto con un veredicto:
  **OK**, **DIFFERENT** (distinto) o **NOT DECODED** (no decodificado).
* Al final imprime un resumen: total de paquetes, porcentaje decodificado
  correctamente, porcentaje decodificado con contenido distinto y porcentaje faltante.

**Se puede usar cualquier archivo WAV con tráfico APRS real (AFSK 1200 baudios)**:
una grabación de un equipo de radio, de una SDR o una pista de prueba publicada. La
sección 6 explica dónde conseguir buenos archivos y propone las pistas de prueba
gratuitas de **WA8LMF**.

La prueba es **solo de recepción**: no se transmite nada y no hace falta conectar
nada del ESP32 hacia la PC.

---

## 2. Qué necesita

### Hardware

| Elemento | Notas |
|---|---|
| Placa ESP32 con el firmware esp32idf_APRS | Alimentada y conectada a la PC por USB (este enlace USB es también la consola serie). |
| PC con salida de placa de sonido | Salida de auriculares o de línea. Una placa de sonido USB económica y dedicada es una buena idea (ver sección 5). |
| Cable de audio, plug de 3,5 mm | Punta = canal izquierdo, manga = masa. Sirve cualquiera de los dos canales: el programa envía el mismo audio a ambos. |
| RV1: trimmer multivuelta de 2 kΩ | Ajusta el nivel. El multivuelta permite un ajuste fino. **Opcional** — la sección 3.1 da una alternativa con resistencias fijas si no tiene un trimmer. |
| C1: condensador de 10 nF cerámico o de película (o de 1 µF solo para grabaciones planas) | La sección 3, *Reglas para los componentes*, explica la elección. Uno electrolítico de 1 µF sirve (¡cuide la polaridad!), de 10 V o más. |
| Cables de conexión | |

### Software (Linux)

El programa está escrito para **Linux con ALSA** y necesita:

| Software | Para qué | Instalación (Debian/Ubuntu) |
|---|---|---|
| Python 3.7+ | ejecuta el programa | normalmente ya está instalado |
| pyserial | lee la consola del ESP32 | `sudo apt install python3-serial` |
| multimon-ng | decodificador de referencia | `sudo apt install multimon-ng` |
| sox (con `play`) | reproduce el WAV y convierte el audio | `sudo apt install sox libsox-fmt-all` |
| alsa-utils | `aplay -l` para encontrar la placa de sonido | `sudo apt install alsa-utils` |
| coreutils (`stdbuf`) | **muy recomendable.** Sin él la salida de multimon-ng queda con búfer de bloque en la tubería, sus paquetes llegan a ráfagas y se marcan con una hora tardía, lo que produce veredictos *NOT DECODED* falsos. El programa avisa al arrancar si falta. | normalmente ya está instalado |
| python3-tk | solo para la interfaz gráfica (`--gui`, sección 10.2) | `sudo apt install python3-tk` |

Instalar todo de una vez:

```bash
sudo apt install python3-serial multimon-ng sox libsox-fmt-all alsa-utils coreutils python3-tk
```

(Si prefiere pip: `pip install pyserial`, dentro de un entorno virtual en las
distribuciones recientes.)

---

## 3. Construir el cable de audio (hardware)

Circuito mínimo de entrada de audio

### Qué hace el circuito

* La salida de la placa de sonido de la PC es una señal que oscila **tanto por
  encima como por debajo de 0 V** (puede llegar a más o menos 1 V o más). El ADC
  del ESP32 solo acepta **de 0 a 3,3 V** y nunca debe recibir una tensión negativa.
* **RV1** (el trimmer) es un **control de volumen / divisor de tensión** sobre la
  salida de la PC. Su cursor toma solo una fracción de la señal.
* **C1** (el condensador) **bloquea la continua** y deja pasar el audio. Del lado
  del ESP32 se conecta a GPIO33, cuyo nivel de continua lo fija el propio ESP32.
* El ESP32 puede polarizar su propio pin de ADC: conecta las **resistencias
  internas pull-up y pull-down** del pad para que el pin quede en reposo en
  aproximadamente **1,65 V** (la mitad de 3,3 V). El audio viaja entonces sobre
  ese nivel de continua. Esta es la opción del firmware **ADC input self-bias**
  (sección 4). Por eso todo el circuito no necesita resistencias propias.
* La **masa** del jack (manga) va a **GND** del ESP32.

### Conexión, paso a paso

Apague todo primero.

1. **Punta del jack** → extremo superior de **RV1**.
2. **Manga del jack** → extremo inferior de **RV1** **y** **GND** del ESP32.
3. **Cursor de RV1** (el terminal del medio) → **C1, lado menos (−)**.
4. **C1, lado más (+)** → **GPIO33** del ESP32.

### Polaridad del condensador (importante si C1 es electrolítico)

Un condensador electrolítico tiene **polaridad**. GPIO33 queda en reposo en
aproximadamente 1,65 V y el lado de la PC en aproximadamente 0 V, por lo que el
lado del ESP32 es el positivo:

| Terminal de C1 | Va a | Cómo reconocerlo |
|---|---|---|
| **+** (más) | **GPIO33** (ESP32) | el terminal **más largo** de una pieza nueva |
| **−** (menos) | **cursor de RV1** (lado PC) | el terminal bajo la **franja con signos menos** impresa en el cuerpo |

En el dibujo, la placa recta (marcada +) mira hacia GPIO33 y la placa curva
(marcada −) mira hacia el cursor del trimmer. Conectarlo al revés hace que tenga
fugas y agregue ruido. Un condensador cerámico o de película de 1 µF no tiene
polaridad, si dispone de uno.

### Reglas para los componentes

* **C1 es de 10 nF para las grabaciones con deénfasis, y sirve también para las
  planas.** C1 y las resistencias de autopolarización del ESP32 (unos 22 kΩ, que
  varían de una pieza a otra) forman un filtro pasa-altos. Con **10 nF** su corte
  queda en unos 700 Hz (entre 500 y 900 Hz): una grabación con deénfasis como la
  pista 2 de WA8LMF trae graves muy por encima de los tonos, y sin este filtro
  esos graves ocupan el rango del ADC y dejan los tonos apenas unas cuentas por
  encima del ruido del conversor. El pasa-altos de la página Radiomodem no puede
  recuperarlo, porque actúa después del conversor. El filtro además quita 1,3 dB
  al tono de 1200 Hz y 0,4 dB al de 2200 Hz, lo que le viene bien al audio con
  deénfasis; en una grabación plana no produce una diferencia medible. Un 10 nF
  cerámico o de película no tiene polaridad. **1 µF** (corte en unos 7 Hz) sirve
  solo para grabaciones planas; 100 nF (unos 70 Hz) se comporta como 1 µF.
* **El trimmer debe estar *antes* del condensador**, como en el dibujo. Si RV1 se
  pusiera entre el condensador y el pin, su pata inferior conectaría GPIO33 a masa
  y destruiría la polarización.
* **RV1 = 2 kΩ** es un valor bajo. Presenta una carga de 2 kΩ a la salida de la PC,
  que la mayoría de las salidas tipo auricular soportan sin problema. Si el sonido
  de la salida de la PC se distorsiona, use un trimmer de 10 kΩ (la documentación
  del firmware recomienda 10 kΩ, sobre todo para mantener liviana la carga sobre la
  fuente).
* **El pin del ESP32 no tiene diodos de protección aquí.** RV1 es lo único que
  limita lo que llega a GPIO33. Antes de conectar, ponga el volumen de la PC bajo y
  RV1 cerca del extremo de masa (sección 7). Una salida de auriculares a volumen
  máximo puede oscilar muy por encima de los 0 – 3,3 V que tolera el pin.
* El esquema de referencia del firmware (la interfaz RX completa de la
  documentación del proyecto) agrega dos **diodos de fijación, D1/D2**, que
  mantienen el pin del ADC dentro de los rieles de alimentación, además de un
  pequeño snubber R/C. Este circuito mínimo los omite a propósito: el firmware se
  apoya entonces en la opción **Warn on receive over-range**. Si va a dejar el
  banco conectado mucho tiempo, o usa una fuente fuerte, considere agregar los
  diodos de fijación como se dibujan en ese esquema.
* Solo **GPIO32 y GPIO33** pueden usar la autopolarización incorporada. La entrada
  predeterminada del firmware es GPIO33; si cambió el pin del ADC en su
  compilación, use ese pin (debe ser GPIO32 o GPIO33 para este circuito).

### 3.1 Alternativa: resistencias fijas en lugar del trimmer

Si no dispone de un trimmer de 2 kΩ, RV1 puede reemplazarse por **dos
resistencias fijas** conectadas como un divisor de tensión permanente. Se
pierde la posibilidad de girar una perilla, pero la sección 7.1 muestra cómo la
**calibración automática de volumen** del propio programa compensa eso por
software.

Alternativa con resistencias fijas a RV1

Dicho de forma más simple: **R1** va desde la **punta** del jack hasta un nodo
intermedio; **R2** va desde ese mismo nodo intermedio hasta la **manga** del
jack (masa, unida a GND del ESP32). El nodo intermedio —donde se juntan R1 y
R2— reemplaza al cursor del trimmer y va al **lado menos (−) de C1**,
exactamente como en los pasos de conexión de más arriba. Todo lo demás (C1, la
conexión a GPIO33, la masa compartida) queda igual.

* **Valores sugeridos para empezar: R1 = 4,7 kΩ, R2 = 1 kΩ.** Esto divide la
  salida de la PC por aproximadamente 5,7×, presentando una carga liviana de
  ≈5,7 kΩ. Es solo un punto de partida: el nivel de salida de línea varía mucho
  entre placas de sonido, así que la tensión que realmente llega a GPIO33
  sigue dependiendo del volumen que fije la PC.
* **Este divisor es fijo — no se puede ajustar como un trimmer.** Use el
  control de volumen de la PC para el ajuste grueso (como en la sección 7), y
  deje que la ganancia por software `--volume` (aplicada automáticamente por la
  calibración automática de volumen descrita en la sección 7.1, salvo que
  indique `--no_auto_volume`) se encargue del ajuste fino. Es exactamente la
  situación para la que existe esa función de calibración.
* Si, incluso con el volumen de la PC bajo, el nivel siempre resulta demasiado
  alto (over-range) o siempre demasiado bajo (valores en bruto pegados a 0 o a
  4095, algo que `--volume` por sí solo no puede corregir), cambie a un divisor
  con más o menos atenuación — por ejemplo R1 = 10 kΩ / R2 = 1 kΩ (más
  atenuación) o R1 = 2,2 kΩ / R2 = 1 kΩ (menos) — y vuelva a comprobar con RX
  LEVEL (sección 7) o con otra pasada de calibración automática.
* Un trimmer sigue siendo la opción más cómoda si piensa reutilizar el banco de
  pruebas con distintas placas de sonido o grabaciones: permite fijar el nivel
  analógico una sola vez, en hardware, en lugar de depender cada vez de la
  ganancia por software.

---

## 4. Preparar el ESP32 (ajustes del firmware)

Conéctese al punto de acceso Wi-Fi del ESP32 (SSID de fábrica `esp32idf_APRS`,
contraseña `esp32idf_APRS`) y abra `http://192.168.4.1/` en un navegador (usuario
de fábrica `admin` / `admin`, salvo que lo haya cambiado). La interfaz puede
mostrarse en varios idiomas; abajo se dan las etiquetas en español.

### 4.1 Ajustes de audio — página *Radiomódem*

| Etiqueta | Ajustar a |
|---|---|
| Activar módem ADC/DAC de audio | **ON** (activado) |
| Interfaz de audio → Polarización interna de la entrada del ADC | **ON** (esto es lo que hace funcionar el circuito acoplado con condensador) |
| Interfaz de audio → Avisar cuando el audio recibido se sale de rango | **ON** (avisa cuando la señal es demasiado fuerte; el circuito no tiene diodos de fijación) |

Guarde (reinicie el ESP32 si la página lo pide).
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

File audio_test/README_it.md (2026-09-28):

# Banco di prova audio per esp32idf_APRS — manuale d'uso

🌐 [English](README.md) · [Español](README_es.md) · **Italiano**

Provare il ricevitore APRS AFSK a 1200 baud del firmware **esp32idf_APRS** con
**traffico APRS reale registrato via radio** e misurare quanti pacchetti decodifica
l'ESP32 rispetto a un decodificatore di riferimento (**multimon-ng**).

---

## Indice

1. [Cosa fa questo test](#1-cosa-fa-questo-test)
2. [Cosa serve](#2-cosa-serve)
3. [Costruire il cavo audio (hardware)](#3-costruire-il-cavo-audio-hardware)
4. [Preparare l'ESP32 (impostazioni del firmware)](#4-preparare-lesp32-impostazioni-del-firmware)
5. [Preparare il PC](#5-preparare-il-pc)
6. [Ottenere file audio con traffico APRS reale](#6-ottenere-file-audio-con-traffico-aprs-reale)
7. [Regolare il livello audio](#7-regolare-il-livello-audio) ([calibrazione automatica del volume](#71-calibrazione-automatica-del-volume), [normalizzazione](#72-normalizzazione-e-guadagni-superiori-a-10))
8. [Prima esecuzione: verificare l'intera catena con pacchetti sintetici](#8-prima-esecuzione-verificare-lintera-catena-con-pacchetti-sintetici)
9. [Eseguire il test reale](#9-eseguire-il-test-reale)
10. [Riferimento della riga di comando](#10-riferimento-della-riga-di-comando) ([lingua](#101-lingua), [interfaccia grafica](#102-interfaccia-grafica---gui), [autotest](#103-autotest---selftest))
11. [Leggere i risultati](#11-leggere-i-risultati)
12. [Come vengono confrontati i pacchetti](#12-come-vengono-confrontati-i-pacchetti)
13. [Piano di test suggerito con le tracce di WA8LMF](#13-piano-di-test-suggerito-con-le-tracce-di-wa8lmf)
14. [`gen_test_wav.py` in dettaglio](#14-gen_test_wavpy-in-dettaglio)
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

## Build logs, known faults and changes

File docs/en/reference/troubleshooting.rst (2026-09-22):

.. _en-troubleshooting:

===============
Troubleshooting
===============

"I switched to Station mode, saved, rebooted, and nothing happens."
===================================================================

Read the boot log — this path is heavily instrumented:

* ``esp_wifi_connect()`` is only legal once the station has *actually* started
  (``WIFI_EVENT_STA_START``). The connect is issued from that handler and every
  attempt logs its result.
* If no Wi-Fi Client slot is **enabled with an SSID**, the firmware dumps every
  slot and tells you which mistake it is ("enabled, but the SSID is EMPTY" vs
  "has an SSID, but 'Enable' is not ticked").
* STA-only with nothing to join falls back to AP+STA so the web admin stays up.

Disconnect reason codes are logged:

.. list-table::
   :header-rows: 1
   :widths: 44 56

   * - Reason
     - Meaning
   * - 15, 204
     - wrong password
   * - 201
     - SSID not visible: wrong name, out of range, or 5 GHz-only
   * - 2 / 8 / 200
     - ordinary roaming / AP-side drops

"AP won't associate at all."
============================

A zeroed ``wifi_config_t`` leaves ``pmf_cfg.capable = false``, and
WPA3 / WPA2-with-PMF-required APs refuse such a station. The firmware sets
*capable, not required*, which works against both old and new APs.

"Boot hangs for ~5 seconds."
============================

Expected: ``modem_init()`` blocks while ``ModemCalibrateSampleRate()`` measures
the real ADC clock. Once per boot.

"Beacons at boot don't transmit."
=================================

Expected: ``aprs_service_start()`` runs before ``modem_init()``, so early
beacons are dropped with a debug log until ``s_modemReady``.

"LOOP TEST fails with 'no packet received back'."
=================================================

Check the ADC attenuation: the DAC swings the full rail while a 0 dB attenuation
only measures ~0–1.1 V, clipping the tone beyond the demodulator's ability to
lock. The component hard-codes ``ADC_ATTEN_DB_12``, which is correct; if you
overrode it, put it back. Also confirm the GPIO25 → GPIO33 loopback wire.

"IGate says unverified."
========================

Wrong ``aprs_mycall`` / ``aprs_passcode``. The banner is logged; so is the exact
login line, including the filter string, so a malformed filter is visible
immediately.

"Everything works but aprs.fi doesn't show my station."
=======================================================

Beacons: enable the position beacon and at least one of ``loc2rf`` /
``loc2inet``, and set real coordinates. Relaying traffic never announces you.

"9600 Bd loses frames."
=======================

That is the pathology the ADC rate, conversion-frame size and core split were
changed to fix (see :ref:`en-dsp-signal-chain`). If you overrode
``MODEM_ADC_SAMPLERATE``, ``MODEM_ADC_CONV_FRAME``, ``MODEM_DAC_TIMER_CORE`` or
``MODEM_ADC_ISR_CORE``, revert them. Also confirm you are feeding
**flat/discriminator** audio.

"The PTT LED stays on when idle."
=================================

The PTT logic is correct; its polarity is a compile-time constant, and the
shipped board definition is ``MODEM_PTT_ACTIVE_HIGH=1`` (active-high) in the
top-level ``CMakeLists.txt``. Active-high means idle/unkeyed drives the pin
**low** and keyed drives it high; active-low is the mirror image, so idle leaves
the pin high and an LED on that pin stays lit. If the LED tracks the opposite of
what you expect, your driver stage inverts (an optocoupler does; a plain NPN
low-side switch does not): flip the macro to the other value and do a full clean
rebuild — the value is baked into ``afsk.c``, so an incremental build will not
pick it up.
"The boot log says ``gpio: conflict found for GPIO[26]``."
=========================================================

A ``gpio_config()`` call claims every pad it configures, and warns when it
finds one another call already claimed; the pad is configured either way, so
the line is informational.

GPIO26 is the PTT pad on the shipped board definition, and it is configured
twice on purpose: ``ptt_force_idle()`` in ``main.c`` puts it at its idle level
as the first thing ``app_main()`` does, so the keying line does not float out
of reset, and ``AFSK_init()`` configures it again when the modem starts about
a second and a half later. The second call hands the claim back first, so the
line should not appear. If it does, an ESP-IDF without the internal
``esp_gpio_reserve.h`` header was used, and the warning is harmless.

A conflict on any **other** pin is a real one: two features are pointing at
the same pad. Check the Message Alarm pin on the Message page, which is the
only pin the configuration stores, and the fixed pins in the top-level
``CMakeLists.txt`` (ADC, DAC, PTT, status LEDs).

"Telegram stops answering after running for a while, with 'mbedtls_ssl_fetch_input' or 'Socket is not connected' in the log."
===============================================================================================================================

The polling path keeps its HTTPS connection to the Telegram API open between
cycles, so a long poll that returns nothing does not pay for a new TLS
handshake every ten seconds. If that connection sits idle long enough, the
peer or an intermediate NAT can close it silently; the socket is then stale
even though nothing local noticed. ``telegram_bot_client_call()`` treats a
transport failure as a sign of exactly that: it force-closes the connection
and retries the request on a freshly opened socket, up to three attempts
total with a delay that grows between them, so a single stale session
recovers on its own within the same call. If the error keeps repeating
across every attempt, the network itself is down rather than one stale
socket; check Wi-Fi/Internet connectivity and the bot token.

"sendMessage fails with 'ESP_ERR_HTTP_CONNECT' right after an update arrives, preceded by 'Dynamic Impl: alloc(...) failed'."
=============================================================================================================================

A fresh TLS handshake asks the heap for its record buffers as single
allocations of a few kilobytes each, so what decides whether it succeeds is
the largest **contiguous** free block, not the total free heap. The ESP-IDF
allocator reports the refusal as ``Dynamic Impl: alloc(...) failed``, mbedTLS
turns it into ``mbedtls_ssl_handshake returned -0x008D`` and the transport
sees ``ESP_ERR_HTTP_CONNECT``.

A live TLS session holds a block of comparable size for as long as it is
kept, so the firmware never holds two at once. The transmit handle runs with
keep-alive off and is therefore empty the moment a call returns, and the
polling connection is released by ``telegram_release_poll_connection()``
immediately before any outgoing request, which is the moment that matters:
a reply is sent right after a batch of updates arrived, with the payload and
the decoded tree still in memory. The poll pays one extra handshake on its
next cycle and nothing else.

Every failed attempt is logged with the free heap and the largest free block
at that instant. If the largest block is comfortably above four kilobytes and
the call still fails, the fault is the link rather than the heap. If it is
not, the device is genuinely short of contiguous memory: lower
``rx_buffer_size`` on the client handles, or reduce what the rest of the
firmware holds at that moment.

``CONFIG_MBEDTLS_SSL_IN_CONTENT_LEN`` is not the lever it looks like. It is a
ceiling on the record the peer may send, and the certificate chain Telegram
presents is around four kilobytes in one record, so lowering it under that
figure does not save memory — it makes the handshake fail outright, on every
attempt and in every heap condition.

``CONFIG_MBEDTLS_DYNAMIC_FREE_CONFIG_DATA`` is a real one, and it is not free.
With ``CONFIG_MBEDTLS_DYNAMIC_BUFFER`` already on, it releases the parsed
certificate and key structures once the handshake is done instead of holding
them for the life of the session, which is a few kilobytes back on a board
whose main pool runs with single-digit kilobytes of margin. It also selects
``CONFIG_MBEDTLS_DYNAMIC_FREE_CA_CERT`` by default, and that is where the
catch is: a session object that has to handshake again must have its CA
registered again first. This firmware builds a fresh TLS connection for each
one, so nothing here reuses a session across handshakes, but the symptom to
watch for is a first request that succeeds followed by later ones failing in
the handshake rather than at random. If that appears, turn the option back off
before looking anywhere else.

"The free heap was lower this morning than it was last night, and the log says nothing about it."
=================================================================================================

Every other heap figure this firmware logs is printed *after* a failure: the
two lines in the Telegram transport, the diagnosis detail attached to a failed
bring-up, the write-error path of the JSON stores. They describe the heap once
the damage was done, and say nothing about how it got there. A watermark that
fell at three in the morning therefore leaves no trace of what was running.

The standing instrumentation that answers such a question lives in
``main/heap_monitor.c``, driven from the APRS service's 1 Hz tick, and is
configured under ``APRS heap instrumentation`` in ``idf.py menuconfig``.

**One line per period.** ``CONFIG_APRS_HEAP_REPORT`` is on by default and emits
one line every ``CONFIG_APRS_HEAP_REPORT_PERIOD_S`` seconds::

   I (3600123) heap_monitor: free=104512 largest=45056 min_sum=41216

Three figures, read together. The free size is how much memory exists; the
largest free block is the biggest single allocation still possible, and the two
drifting apart is a heap breaking up rather than being consumed; the minimum is
the low watermark since boot, so a dip that recovered before the next line
still shows there. All three are read for internal 8-bit memory, the same class
the transport prints on failure, so the two kinds of line can be read against
each other. The line costs three allocator queries per period and no memory.

The Kconfig default is ten seconds — the shipped ``sdkconfig`` sets it to 60,
which is the value to lower first when chasing a peak — because the period has
to be shorter than the events it is meant to catch, and on this firmware those are short: a TLS handshake, an
APRS-IS reconnect or a settings save each peak and recover within a few seconds.
A sampler slower than that is structurally blind to them — it records the heap
before and after, never during, and every line it prints is consistent with a
peak that never happened. The dashboard's own 1 Hz refresh is finer still, but
it only exists while a browser is sitting on the page, which is not when boot
bring-up or an unattended reconnect happens.

.. warning::

   ``min_sum`` is a sum of minimums, not the minimum of the sum. The allocator
   keeps a watermark per registered heap and this figure adds them up, each term
   taken at that heap's own worst instant. An ESP32 without PSRAM does not have
   one DRAM heap: ROM and PHY reservations split the internal DRAM into three or
   four non-contiguous regions, each registered separately.

   Because the terms are independent, the sum is a *lower bound* on the smallest
   the total free heap has ever actually been, and the bound loosens as the
   number of heaps grows. A tiny ``min_sum`` therefore has two readings this line
   alone cannot tell apart: every region was near empty at one moment, or each
   region bottomed out separately at a moment of its own and the total was never
   in danger. Both matter — a region stuck near zero is a real fragmentation
   fault, because ``heap_caps_malloc()`` skips it from then on and the allocator
   behaves as though it were not there — but they call for different work.
   Settle which one you have before changing any allocation, with the breakdown
   below.

**Which heap actually ran dry.** ``CONFIG_APRS_HEAP_REPORT_PER_HEAP`` follows
each line with the table the heap component prints itself: one row per
registered heap, with its start address, size, current free, largest free block
and minimum free ever. This is what separates the two readings above. If the
main pool's own minimum is in the tens of kilobytes and only the small D/IRAM
regions read near zero, the summary was a sum-of-minimums artifact; if the main
pool's minimum is also near zero, the station really did come close to running
out. Off by default because it is several lines per period — turn it on for the
run that answers the question, then off again.

**Brackets around the heavy paths.** ``CONFIG_APRS_HEAP_BRACKET`` logs the free
heap and the largest free block immediately before and immediately after each
passage known to take a large or long-lived bite: the Telegram bring-up, the
APRS-IS connect, the configuration load, the console mirror's ring, the WiFi
scan, the OTA upload and each web form buffer.
``CONFIG_TELEGRAM_BOT_HEAP_BRACKET``, under ``Telegram bot transport``, does the
same for every request the bot makes — each attempt of a JSON call, plus the
multipart upload and the file download, which open connections of their own. The
two nest, carry the same figures in the same memory class, and are meant to be
enabled together.

The periodic line says *when* the heap moved; a bracket says *what* moved it,
because its figures are taken on either side of one named passage rather than at
whatever instant the period came due. If the notches in the periodic trace fall
inside a bracket, that passage is what moves the heap; if they fall between
brackets, something else does. Both are off by default: two lines per event, and
the polling path makes one every few seconds.

**Attributing the memory to a task.** Enable ``CONFIG_HEAP_TASK_TRACKING``
(``Component config`` → ``Heap memory debugging``) and
``CONFIG_APRS_HEAP_REPORT_TASKS`` appears, adding the per-task overview table
under each heap line, so a genuine leak names its owner in one dump instead of
a week of bisection. Tracking costs RAM per live allocation and slows every
allocation and free, so it belongs in a diagnostic build — turn it off again
afterwards.

**Stack headroom.** ``CONFIG_APRS_STACK_REPORT`` is on by default and emits one
line per task every ``CONFIG_APRS_STACK_REPORT_PERIOD_S`` seconds (an hour) with
that task's stack high-water mark::

   I (3600130) heap_monitor: stack igate_task: 2712 bytes free at its worst
   I (3600131) heap_monitor: stack wifi: 1544 bytes free at its worst

Task stacks are the largest single block of RAM this firmware reserves and the
one nobody measures: every stack size in the project is a budget set with
deliberate headroom, not a figure trimmed to what the task turned out to need.
Without this line the only way a stack reports being too small is by
overflowing, and there is no way at all to learn that one is far too large. A
high-water mark only ever falls, so nothing is missed between lines — each one
reports the worst that task has seen since it started. Only live tasks appear:
one the operator has switched off simply has no row that hour.

**Ruling out corruption.** ``CONFIG_APRS_HEAP_INTEGRITY_CHECK`` sweeps every
heap every ``CONFIG_APRS_HEAP_INTEGRITY_PERIOD_S`` seconds and logs an error,
after the addresses the checker itself prints, if anything is wrong. Corrupted
allocator structures present as inexplicable heap behaviour and are otherwise
chased as a leak. The sweep holds each heap's lock while it walks it, so other
tasks block if they allocate meanwhile — hence off by default and on a slow
timer when on. What it can see depends on the corruption detection level: with
no poisoning only the allocator's own structures are checked, so select "Light
impact" or "Comprehensive" under ``Heap memory debugging`` to also verify the
canary bytes around every allocated block. Without that, an implausible
watermark cannot be told apart from a corrupted one.

**Catching a stack overflow where it happens.**
``CONFIG_FREERTOS_WATCHPOINT_END_OF_STACK`` (``Component config`` →
``FreeRTOS`` → ``Port``) points the last hardware watchpoint at the final 32
bytes of the running task's stack, so an overflow panics at the instruction
that caused it. The canary check that ships by default only runs at a context
switch, which reports the damage long after the code responsible has returned —
and if the overflow is a large local that jumps clear over the canary region,
it is never reported at all, surfacing later as unrelated corruption. That is
worth knowing when a crash lands somewhere impossible, such as the scheduler
failing to find any runnable task. The cost is one watchpoint fewer under gdb
and up to 60 bytes off every task stack, so it belongs in a diagnostic build
alongside the options above. It still only catches writes that land within
those last 32 bytes.

**Serializing the two heaviest network operations.** The same module also
owns a small non-blocking lock, unrelated to the sampling above and always
present regardless of which ``CONFIG_APRS_HEAP_*`` options are enabled. The
Telegram bot's TLS handshake (:ref:`en-telegram`) and the APRS-IS uplink's TCP
connect (:ref:`en-igate`) each take it around their own heap-floor check and
release it once that setup work is done, so the two never run at the same
instant and compete for the same contiguous memory. A caller that finds the
lock already held simply defers to its own next retry pass — nothing here
blocks waiting for the other side.

"Menu buttons keep spinning and the log shows 'query is too old and response timeout expired or query ID is invalid'."
======================================================================================================================

Telegram invalidates a callback query a few seconds after the button is
pressed. Answering it is a request of its own, and on this device a request
can cost a TLS handshake, so the order in which the work is done decides
whether the answer still arrives in time.

Three things keep it inside the deadline. The query is answered before the
button handler runs, not after it, so building and sending a report never
delays the answer. The transmit connection stays open across one batch of
updates, so a burst of presses pays one handshake between them all instead
of one each. And a single failed polling cycle adds no pause of its own on top
of the retries the transport already spent, because that pause would be time
the queued queries spend ageing; the five second pause is applied as soon as
failures repeat, which is when the network really is down.

A query that is genuinely too old is refused by Telegram with a 400 and the
message above, and the batch it belonged to is still processed. If this
appears once after a poll failure or a reconnection, the queue simply
outlived its updates. If it appears steadily, the device is not keeping up
with the poll at all: look for the polling failures above it in the log.

"Requests fail at random with 'mbedtls_ssl_handshake returned -0x2700', while free heap is plentiful."
======================================================================================================

``-0x2700`` is ``MBEDTLS_ERR_X509_CERT_VERIFY_FAILED``: the TLS handshake
reached the server, exchanged messages and then refused the certificate it
was shown. Nothing was wrong with the link and nothing was wrong with the
heap, which is why the figures printed alongside the failure look healthy.

``api.telegram.org`` is answered by more than one front-end and they do not
all chain to the same certificate authority. When the transport validates
against a PEM file rather than the ESP-IDF bundle, that file only trusts the
authorities it actually carries, so a file holding a single root validates
the connections that land on a matching front-end and fails the others.
Which front-end DNS hands out varies between attempts, which is exactly why
the failure looks random and why a retry usually succeeds.

The transport reports it explicitly. A refused chain is logged as ``Peer
certificate refused, verification flags 0x…, validating against <path>``,
and start-up logs how many anchors the file yielded (``Loaded N trust
anchors from …``). One anchor with intermittent ``-0x2700`` is the signature
of this problem.

There are two fixes. Concatenate the missing roots into the PEM file — every
certificate in it becomes a trust anchor, and the file is replaceable from
the web admin's File Storage page without rebuilding. Or select
``TELEGRAM_BOT_CERT_BUNDLE`` in menuconfig and validate against the
certificate bundle shipped with ESP-IDF, which covers the public authorities
and keeps working when Telegram rotates its chain, at the cost of carrying
the bundle in the image.

Note that ``CONFIG_MBEDTLS_HAVE_TIME_DATE`` is not enabled in this firmware,
so certificate validity dates are not checked. An unsynchronised clock is
therefore never the cause of ``-0x2700`` here.

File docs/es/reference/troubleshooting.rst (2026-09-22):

.. _es-troubleshooting:

=======================
Resolución de problemas
=======================

"Cambié a modo Station, guardé, reinicié, y no pasa nada."
==========================================================

Lee el log de arranque — esta ruta está muy instrumentada:

* ``esp_wifi_connect()`` solo es legal una vez que la estación ha arrancado
  *realmente* (``WIFI_EVENT_STA_START``). La conexión se emite desde ese
  manejador y cada intento registra su resultado.
* Si ninguna ranura de Cliente Wi-Fi está **habilitada con un SSID**, el firmware
  vuelca cada ranura y te dice cuál es el error ("habilitada, pero el SSID está
  VACÍO" vs "tiene un SSID, pero 'Enable' no está marcado").
* Solo-STA sin nada a lo que unirse recurre a AP+STA para que la administración
  web siga arriba.

Los códigos de razón de desconexión se registran:

.. list-table::
   :header-rows: 1
   :widths: 44 56

   * - Razón
     - Significado
   * - 15, 204
     - contraseña equivocada
   * - 201
     - SSID no visible: nombre equivocado, fuera de rango, o solo 5 GHz
   * - 2 / 8 / 200
     - roaming ordinario / caídas del lado del AP

"El AP no asocia en absoluto."
==============================

Un ``wifi_config_t`` a cero deja ``pmf_cfg.capable = false``, y los AP
WPA3 / WPA2-con-PMF-requerido rechazan tal estación. El firmware pone *capable,
no required*, que funciona contra AP antiguos y nuevos.

"El arranque se cuelga ~5 segundos."
====================================

Esperado: ``modem_init()`` se bloquea mientras ``ModemCalibrateSampleRate()`` mide
el reloj real del ADC. Una vez por arranque.

"Las balizas al arrancar no transmiten."
========================================

Esperado: ``aprs_service_start()`` corre antes de ``modem_init()``, así que las
balizas tempranas se descartan con un log de depuración hasta ``s_modemReady``.

"El LOOP TEST falla con 'no se recibió paquete de vuelta'."
===========================================================

Comprueba la atenuación del ADC: el DAC oscila el raíl completo mientras una
atenuación de 0 dB solo mide ~0–1,1 V, recortando el tono más allá de la capacidad
del demodulador para enganchar. El componente codifica ``ADC_ATTEN_DB_12``, que es
correcto; si lo sobreescribiste, restáuralo. Confirma también el cable de bucle
GPIO25 → GPIO33.

"El IGate dice unverified."
===========================

``aprs_mycall`` / ``aprs_passcode`` equivocados. El banner se registra; también la
línea de login exacta, incluida la cadena de filtro, así que un filtro mal formado
es visible de inmediato.

"Todo funciona pero aprs.fi no muestra mi estación."
====================================================

Balizas: habilita la baliza de posición y al menos una de ``loc2rf`` /
``loc2inet``, y pon coordenadas reales. Retransmitir tráfico nunca te anuncia a ti.

"9600 Bd pierde tramas."
========================

Esa es la patología que la tasa del ADC, el tamaño de la trama de conversión y la
separación de núcleos se cambiaron para arreglar (véase :ref:`es-dsp-signal-chain`).
Si sobreescribiste ``MODEM_ADC_SAMPLERATE``, ``MODEM_ADC_CONV_FRAME``,
``MODEM_DAC_TIMER_CORE`` o ``MODEM_ADC_ISR_CORE``, reviértelos. Confirma también que
estás alimentando audio **plano/de discriminador**.

"El LED de PTT se queda encendido en reposo."
=============================================

La lógica de PTT es correcta; su polaridad es una constante de compilación, y la
definición de placa que se distribuye es ``MODEM_PTT_ACTIVE_HIGH=1``
(activo-alto) en el ``CMakeLists.txt`` de nivel superior. Activo-alto significa
que reposo/sin-activar acciona el pin **bajo** y activado lo acciona alto;
activo-bajo es la imagen espejo, así que en reposo el pin queda alto y un LED en
ese pin se queda encendido. Si el LED sigue lo contrario de lo que esperas, tu
etapa de excitación invierte (un optoacoplador sí; un simple NPN de lado bajo
no): cambia la macro al otro valor y haz una recompilación limpia completa — el
valor queda horneado en ``afsk.c``, así que una compilación incremental no lo
tomará.
"El registro de arranque dice ``gpio: conflict found for GPIO[26]``."
====================================================================

Una llamada a ``gpio_config()`` reclama cada pad que configura y avisa cuando
encuentra uno que otra llamada ya había reclamado; el pad queda configurado de
todos modos, así que la línea es informativa.

GPIO26 es el pad del PTT en la definición de placa que se distribuye, y se
configura dos veces a propósito: ``ptt_force_idle()`` en ``main.c`` lo pone en
su nivel de reposo como primera acción de ``app_main()``, para que la línea de
manipulación no quede flotando tras el reset, y ``AFSK_init()`` lo vuelve a
configurar cuando arranca el módem, algo más de un segundo después. La segunda
llamada devuelve antes el reclamo, así que la línea no debería aparecer. Si
aparece, se compiló con un ESP-IDF sin la cabecera interna
``esp_gpio_reserve.h``, y el aviso es inofensivo.

Un conflicto sobre **cualquier otro** pin sí es real: dos funciones apuntan al
mismo pad. Revise el pin de alarma de mensajes en la página Message, que es el
único que guarda la configuración, y los pines fijos del ``CMakeLists.txt``
raíz (ADC, DAC, PTT, LEDs de estado).

"Telegram deja de responder tras un rato funcionando, con 'mbedtls_ssl_fetch_input' o 'Socket is not connected' en el log."
=============================================================================================================================

El camino de sondeo mantiene abierta su conexión HTTPS con la API de Telegram
entre ciclos, para que un *long poll* que no devuelve nada no pague un nuevo
*handshake* TLS cada diez segundos. Si esa conexión queda inactiva el tiempo
suficiente, el extremo remoto o un NAT intermedio puede cerrarla en silencio;
el socket queda entonces obsoleto aunque nada localmente lo haya notado.
``telegram_bot_client_call()`` trata un fallo de transporte como señal
exactamente de eso: cierra la conexión a la fuerza y reintenta la solicitud
sobre un socket recién abierto, hasta tres intentos en total con una espera
que crece entre ellos, de modo que una única sesión obsoleta se recupera sola
dentro de la misma llamada. Si el error sigue repitiéndose en todos los
intentos, lo que falla es la red y no un socket puntual; revisa la
conectividad Wi-Fi/Internet y el token del bot.

"sendMessage falla con 'ESP_ERR_HTTP_CONNECT' justo después de llegar una actualización, precedido de 'Dynamic Impl: alloc(...) failed'."
=========================================================================================================================================

Un *handshake* TLS nuevo pide a la memoria heap sus búferes de registro como
asignaciones únicas de unos pocos kilobytes cada una, así que lo que decide
si sale adelante es el mayor bloque **contiguo** libre, no el total libre. El
asignador del ESP-IDF registra el rechazo como ``Dynamic Impl: alloc(...)
failed``, mbedTLS lo convierte en ``mbedtls_ssl_handshake returned -0x008D``
y el transporte ve ``ESP_ERR_HTTP_CONNECT``.

Una sesión TLS viva retiene un bloque de tamaño comparable mientras se
mantiene, así que el firmware nunca sostiene dos a la vez. El manejador de
transmisión funciona sin *keep-alive* y por tanto queda vacío en cuanto
retorna la llamada, y la conexión de sondeo la libera
``telegram_release_poll_connection()`` justo antes de cualquier solicitud
saliente, que es el momento que importa: una respuesta se envía justo después
de llegar un lote de actualizaciones, con la carga útil y el árbol
decodificado todavía en memoria. El sondeo paga un *handshake* extra en su
ciclo siguiente y nada más.

Cada intento fallido se registra con la memoria heap libre y el mayor bloque
libre en ese instante. Si el mayor bloque está holgadamente por encima de
cuatro kilobytes y la llamada aún así falla, el problema es el enlace y no la
memoria. Si no lo está, al dispositivo le falta realmente memoria contigua:
reduce ``rx_buffer_size`` en los manejadores del cliente, o reduce lo que el
resto del firmware retiene en ese momento.

``CONFIG_MBEDTLS_SSL_IN_CONTENT_LEN`` no es la palanca que parece. Es un tope
sobre el registro que el otro extremo puede enviar, y la cadena de
certificados que presenta Telegram ronda los cuatro kilobytes en un solo
registro, así que bajarlo por debajo de esa cifra no ahorra memoria: hace que
el *handshake* falle de plano, en todos los intentos y con cualquier estado
de la memoria.

``CONFIG_MBEDTLS_DYNAMIC_FREE_CONFIG_DATA`` sí lo es, y no sale gratis. Con
``CONFIG_MBEDTLS_DYNAMIC_BUFFER`` ya activo, libera las estructuras de
certificado y clave ya parseadas en cuanto termina el *handshake*, en vez de
retenerlas mientras dure la sesión: son unos pocos kilobytes recuperados en una
placa cuyo pozo principal corre con un margen de un solo dígito de kilobytes.
Además selecciona ``CONFIG_MBEDTLS_DYNAMIC_FREE_CA_CERT`` por defecto, y ahí
está la trampa: un objeto de sesión que tenga que rehacer el *handshake*
necesita que se le vuelva a registrar la CA antes. Este firmware construye una
conexión TLS nueva para cada una, así que aquí nada reutiliza una sesión entre
*handshakes*, pero el síntoma a vigilar es una primera petición que funciona
seguida de otras que fallan en el *handshake* en vez de al azar. Si aparece,
desactiva la opción antes de mirar en ningún otro sitio.

"Esta mañana el heap libre está más bajo que anoche y el log no dice nada al respecto."
=======================================================================================

Cualquier otra cifra de heap que registre este firmware se imprime *después* de
un fallo: las dos líneas del transporte de Telegram, el detalle de diagnóstico
que acompaña a un arranque fallido, la ruta de error de escritura de los
almacenes JSON. Describen el heap una vez hecho el daño y no dicen nada de cómo
se llegó ahí. Una marca de agua que cayó a las tres de la madrugada no deja,
por tanto, ningún rastro de lo que estaba corriendo.

La instrumentación permanente que responde a esa pregunta vive en
``main/heap_monitor.c``, la acciona el tick de 1 Hz del servicio APRS y se
configura bajo ``APRS heap instrumentation`` en ``idf.py menuconfig``.

**Una línea por período.** ``CONFIG_APRS_HEAP_REPORT`` está activa por defecto
y emite una línea cada ``CONFIG_APRS_HEAP_REPORT_PERIOD_S`` segundos::

   I (3600123) heap_monitor: free=104512 largest=45056 min_sum=41216

Tres cifras que se leen juntas. El tamaño libre es cuánta memoria existe; el
bloque libre más grande es la mayor asignación individual todavía posible, y que
ambas cifras se separen indica un heap que se fragmenta en vez de consumirse; el
mínimo es la marca de agua más baja desde el arranque, así que una caída que se
recuperó antes de la línea siguiente sigue apareciendo ahí. Las tres se leen
para memoria interna de 8 bits, la misma clase que imprime el transporte al
fallar, de modo que ambos tipos de línea se pueden contrastar. La línea cuesta
tres consultas al asignador por período y nada de memoria.

El valor por defecto de Kconfig es diez segundos —el ``sdkconfig`` que se
entrega lo fija en 60, y es el valor que hay que bajar primero al perseguir un
pico— porque el período tiene que ser más corto que los eventos que pretende
capturar, y en este firmware son cortos: un *handshake*
TLS, una reconexión a APRS-IS o un guardado de ajustes alcanzan su pico y se
recuperan en pocos segundos. Un muestreador más lento que eso es
estructuralmente ciego a todos ellos — registra el heap antes y después, nunca
durante, y cada línea que imprime es compatible con un pico que nunca ocurrió.
El refresco a 1 Hz del panel es aún más fino, pero solo existe mientras hay un
navegador abierto en la página, que no es cuando ocurren el arranque ni una
reconexión desatendida.

.. warning::

   ``min_sum`` es una suma de mínimos, no el mínimo de la suma. El asignador
   mantiene una marca de agua por cada heap registrado y esta cifra las suma,
   tomando cada término en el peor instante de *ese* heap. Un ESP32 sin PSRAM no
   tiene un único heap DRAM: las reservas de la ROM y del PHY parten la DRAM
   interna en tres o cuatro regiones no contiguas, cada una registrada por
   separado.

   Como los términos son independientes, la suma es una *cota inferior* de lo
   más bajo que ha llegado a estar realmente el total de heap libre, y la cota
   se afloja a medida que crece el número de heaps. Por eso un ``min_sum``
   diminuto admite dos lecturas que esta línea por sí sola no distingue: que
   todas las regiones estuvieran casi vacías en un mismo momento, o que cada
   región tocara fondo por separado en un momento propio y el total nunca
   corriera peligro. Ambas importan — una región atascada cerca de cero es un
   fallo real de fragmentación, porque ``heap_caps_malloc()`` la salta desde ese
   momento y el asignador se comporta como si no existiera — pero exigen
   trabajos distintos. Resuelve cuál de las dos tienes antes de tocar ninguna
   asignación, con el desglose de abajo.

**Qué heap se quedó realmente sin memoria.**
``CONFIG_APRS_HEAP_REPORT_PER_HEAP`` acompaña cada línea con la tabla que
imprime el propio componente de heap: una fila por heap registrado, con su
dirección de inicio, tamaño, libre actual, bloque libre más grande y mínimo
libre histórico. Esto es lo que separa las dos lecturas anteriores. Si el
mínimo del pozo principal está en decenas de kilobytes y solo las regiones
D/IRAM pequeñas marcan casi cero, el resumen era un artefacto de la suma de
mínimos; si el mínimo del pozo principal también está cerca de cero, la
estación estuvo de verdad a punto de quedarse sin memoria. Desactivada por
defecto porque son varias líneas por período: actívala para la ejecución que
responda la pregunta y desactívala después.

**Corchetes alrededor de los caminos pesados.** ``CONFIG_APRS_HEAP_BRACKET``
registra el heap libre y el bloque libre más grande justo antes y justo después
de cada pasaje que se sabe que da un mordisco grande o duradero: el arranque de
Telegram, la conexión a APRS-IS, la carga de la configuración, el anillo del
espejo de consola, el escaneo WiFi, la subida OTA y cada búfer de formulario
web. ``CONFIG_TELEGRAM_BOT_HEAP_BRACKET``, bajo ``Telegram bot transport``, hace
lo mismo con cada petición del bot — cada intento de una llamada JSON, más la
subida multiparte y la descarga de fichero, que abren conexiones propias. Ambos
se anidan, llevan las mismas cifras en la misma clase de memoria y están
pensados para activarse juntos.

La línea periódica dice *cuándo* se movió el heap; un corchete dice *qué* lo
movió, porque sus cifras se toman a ambos lados de un pasaje con nombre y no en
el instante en que tocaba el período. Si las muescas de la traza periódica caen
dentro de un corchete, ese pasaje es lo que mueve el heap; si caen entre
corchetes, lo mueve otra cosa. Ambos están desactivados por defecto: son dos
líneas por evento y el camino de *polling* genera uno cada pocos segundos.

**Atribuir la memoria a una tarea.** Activa ``CONFIG_HEAP_TASK_TRACKING``
(``Component config`` → ``Heap memory debugging``) y aparecerá
``CONFIG_APRS_HEAP_REPORT_TASKS``, que añade la tabla resumen por tarea bajo
cada línea de heap, de modo que una fuga real nombra a su dueño en un solo
volcado en vez de en una semana de bisección. El seguimiento cuesta RAM por cada
asignación viva y ralentiza cada asignación y liberación, así que pertenece a
una compilación de diagnóstico: desactívalo después.

**Margen de pila.** ``CONFIG_APRS_STACK_REPORT`` está activa por defecto y emite
una línea por tarea cada ``CONFIG_APRS_STACK_REPORT_PERIOD_S`` segundos (una
hora) con la marca de agua de pila de esa tarea::

   I (3600130) heap_monitor: stack igate_task: 2712 bytes free at its worst
   I (3600131) heap_monitor: stack wifi: 1544 bytes free at its worst

Las pilas de tarea son el mayor bloque individual de RAM que reserva este
firmware y el que nadie mide: cada tamaño de pila del proyecto es un
presupuesto fijado con margen deliberado, no una cifra ajustada a lo que la
tarea resultó necesitar. Sin esta línea, la única forma en que una pila avisa de
que es pequeña es desbordándose, y no hay forma alguna de enterarse de que otra
es enormemente grande. Una marca de agua solo baja, así que no se pierde nada
entre líneas: cada una informa de lo peor que ha visto esa tarea desde que
arrancó. Solo aparecen las tareas vivas: una que el operador haya apagado
simplemente no tiene fila esa hora.

**Descartar la corrupción.** ``CONFIG_APRS_HEAP_INTEGRITY_CHECK`` barre todos
los heaps cada ``CONFIG_APRS_HEAP_INTEGRITY_PERIOD_S`` segundos y registra un
error, después de las direcciones que imprime el propio verificador, si algo va
mal. Las estructuras del asignador corrompidas se presentan como comportamiento
inexplicable del heap y si no se persiguen como una fuga. El barrido mantiene el
cerrojo de cada heap mientras lo recorre, así que otras tareas se bloquean si
asignan mientras tanto: de ahí que esté desactivado por defecto y con un
temporizador lento cuando se activa. Lo que puede ver depende del nivel de
detección de corrupción: sin envenenamiento solo se verifican las estructuras
propias del asignador, así que elige "Light impact" o "Comprehensive" en
``Heap memory debugging`` para verificar además los bytes canario alrededor de
cada bloque asignado. Sin eso, una marca de agua inverosímil no se puede
distinguir de una corrompida.

**Capturar un desbordamiento de pila donde ocurre.**
``CONFIG_FREERTOS_WATCHPOINT_END_OF_STACK`` (``Component config`` →
``FreeRTOS`` → ``Port``) apunta el último watchpoint de hardware a los 32 bytes
finales de la pila de la tarea en curso, de modo que un desbordamiento produce
un panic en la instrucción que lo causó. La comprobación de canario que viene
por defecto solo corre en un cambio de contexto, lo que informa del daño mucho
después de que el código responsable haya retornado; y si el desbordamiento es
una variable local grande que salta por encima de la zona del canario, no se
informa nunca y aparece más tarde como corrupción sin relación. Eso importa
cuando un crash cae en un sitio imposible, como el planificador sin encontrar
ninguna tarea ejecutable. El coste es un watchpoint menos bajo gdb y hasta 60
bytes menos en cada pila de tarea, así que pertenece a una compilación de
diagnóstico junto con las opciones anteriores. Solo captura escrituras que
caigan dentro de esos últimos 32 bytes.

**Serializar las dos operaciones de red más pesadas.** El mismo módulo también
tiene un pequeño cerrojo no bloqueante, independiente del muestreo anterior y
presente siempre, sin importar qué opciones ``CONFIG_APRS_HEAP_*`` estén
activas. El handshake TLS del bot de Telegram (:ref:`es-telegram`) y el
``connect()`` TCP del enlace APRS-IS (:ref:`es-igate`) lo toman cada uno
alrededor de su propia comprobación de mínimo de heap y lo liberan en cuanto
termina ese trabajo de arranque, de modo que nunca se ejecutan en el mismo
instante compitiendo por la misma memoria contigua. Quien encuentra el cerrojo
ya tomado simplemente lo reintenta en su propio ciclo — nada aquí se bloquea
esperando al otro lado.

"Los botones del menú siguen girando y el log muestra 'query is too old and response timeout expired or query ID is invalid'."
==============================================================================================================================

Telegram invalida una *callback query* pocos segundos después de pulsar el
botón. Responderla es una solicitud en sí misma, y en este dispositivo una
solicitud puede costar un *handshake* TLS, así que el orden en que se hace el
trabajo decide si la respuesta llega todavía a tiempo.

Tres cosas la mantienen dentro del plazo. La consulta se responde antes de
ejecutar el manejador del botón, no después, así que construir y enviar un
informe nunca retrasa la respuesta. La conexión de transmisión permanece
abierta durante un lote de actualizaciones, así que una ráfaga de pulsaciones
paga un *handshake* entre todas en vez de uno cada una. Y un único ciclo de
sondeo fallido no añade ninguna pausa propia encima de los reintentos que el
transporte ya gastó, porque esa pausa sería tiempo que las consultas en cola
pasan envejeciendo; la pausa de cinco segundos se aplica en cuanto los fallos
se repiten, que es cuando la red está realmente caída.

Una consulta genuinamente vencida la rechaza Telegram con un 400 y el mensaje
de arriba, y el lote al que pertenecía se procesa igualmente. Si esto aparece
una vez tras un fallo de sondeo o una reconexión, la cola simplemente
sobrevivió a sus actualizaciones. Si aparece de forma sostenida, el
dispositivo no está siguiendo el ritmo del sondeo: busca los fallos de sondeo
por encima en el log.

"Las solicitudes fallan al azar con 'mbedtls_ssl_handshake returned -0x2700', con memoria heap de sobra."
=========================================================================================================

``-0x2700`` es ``MBEDTLS_ERR_X509_CERT_VERIFY_FAILED``: el *handshake* TLS
llegó al servidor, intercambió mensajes y después rechazó el certificado que
le mostraron. Ni el enlace ni la memoria tenían nada malo, y por eso las
cifras impresas junto al fallo se ven sanas.

A ``api.telegram.org`` lo atiende más de un *front-end* y no todos encadenan
a la misma autoridad certificadora. Cuando el transporte valida contra un
archivo PEM en vez del *bundle* del ESP-IDF, ese archivo solo confía en las
autoridades que realmente lleva, así que un archivo con una única raíz valida
las conexiones que caen en un *front-end* compatible y falla las demás. Qué
*front-end* entrega el DNS varía entre intentos, que es exactamente por qué
el fallo parece aleatorio y por qué un reintento suele funcionar.

El transporte lo informa de forma explícita. Una cadena rechazada se registra
como ``Peer certificate refused, verification flags 0x…, validating against
<ruta>``, y el arranque registra cuántos anclajes de confianza dio el archivo
(``Loaded N trust anchors from …``). Un solo anclaje con ``-0x2700``
intermitente es la firma de este problema.

Hay dos soluciones. Concatenar las raíces que faltan en el archivo PEM: cada
certificado que contenga pasa a ser un anclaje de confianza, y el archivo se
puede reemplazar desde la página File Storage del admin web sin recompilar. O
seleccionar ``TELEGRAM_BOT_CERT_BUNDLE`` en menuconfig y validar contra el
*bundle* de certificados que trae ESP-IDF, que cubre las autoridades públicas
y sigue funcionando cuando Telegram rota su cadena, a costa de llevar el
*bundle* en la imagen.

Ten en cuenta que ``CONFIG_MBEDTLS_HAVE_TIME_DATE`` no está habilitado en
este firmware, así que no se comprueban las fechas de validez de los
certificados. Un reloj sin sincronizar nunca es aquí la causa de ``-0x2700``.

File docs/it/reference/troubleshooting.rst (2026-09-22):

.. _it-troubleshooting:

========================
Risoluzione dei problemi
========================

"Sono passato alla modalità Station, ho salvato, riavviato, e non succede niente."
==================================================================================

Leggi il log di avvio — questo percorso è molto strumentato:

* ``esp_wifi_connect()`` è legale solo una volta che la stazione è *davvero*
  avviata (``WIFI_EVENT_STA_START``). La connessione è emessa da quel gestore e
  ogni tentativo registra il suo risultato.
* Se nessuno slot di Client Wi-Fi è **abilitato con un SSID**, il firmware scarica
  ogni slot e ti dice qual è l'errore ("abilitato, ma il SSID è VUOTO" vs "ha un
  SSID, ma 'Enable' non è spuntato").
* Solo-STA senza nulla a cui unirsi ripiega su AP+STA così che l'amministrazione
  web resti attiva.

I codici di ragione di disconnessione sono registrati:

.. list-table::
   :header-rows: 1
   :widths: 44 56

   * - Ragione
     - Significato
   * - 15, 204
     - password sbagliata
   * - 201
     - SSID non visibile: nome sbagliato, fuori portata, o solo 5 GHz
   * - 2 / 8 / 200
     - roaming ordinario / cadute dal lato AP

"L'AP non associa affatto."
===========================

Un ``wifi_config_t`` azzerato lascia ``pmf_cfg.capable = false``, e gli AP
WPA3 / WPA2-con-PMF-richiesto rifiutano tale stazione. Il firmware imposta
*capable, non required*, che funziona contro AP vecchi e nuovi.

"L'avvio si blocca ~5 secondi."
===============================

Atteso: ``modem_init()`` si blocca mentre ``ModemCalibrateSampleRate()`` misura il
clock reale dell'ADC. Una volta per avvio.

"I beacon all'avvio non trasmettono."
=====================================

Atteso: ``aprs_service_start()`` gira prima di ``modem_init()``, quindi i beacon
precoci vengono scartati con un log di debug fino a ``s_modemReady``.

"Il LOOP TEST fallisce con 'nessun pacchetto ricevuto di ritorno'."
===================================================================

Controlla l'attenuazione dell'ADC: il DAC oscilla il rail completo mentre
un'attenuazione di 0 dB misura solo ~0–1,1 V, tagliando il tono oltre la capacità
del demodulatore di agganciare. Il componente cabla ``ADC_ATTEN_DB_12``, che è
corretto; se lo hai sovrascritto, ripristinalo. Conferma anche il cavo di loop
GPIO25 → GPIO33.

"L'IGate dice unverified."
==========================

``aprs_mycall`` / ``aprs_passcode`` sbagliati. Il banner è registrato; anche la
riga di login esatta, inclusa la stringa di filtro, così che un filtro malformato
sia visibile subito.

"Tutto funziona ma aprs.fi non mostra la mia stazione."
=======================================================

Beacon: abilita il beacon di posizione e almeno uno di ``loc2rf`` / ``loc2inet``,
e imposta coordinate reali. Ritrasmettere traffico non ti annuncia mai.

"9600 Bd perde frame."
======================

Quella è la patologia che la frequenza dell'ADC, la dimensione del frame di
conversione e la separazione dei core sono stati cambiati per correggere (vedi
:ref:`it-dsp-signal-chain`). Se hai sovrascritto ``MODEM_ADC_SAMPLERATE``,
``MODEM_ADC_CONV_FRAME``, ``MODEM_DAC_TIMER_CORE`` o ``MODEM_ADC_ISR_CORE``,
ripristinali. Conferma anche di alimentare audio **piatto/di discriminatore**.

"Il LED del PTT resta acceso in riposo."
========================================

La logica del PTT è corretta; la sua polarità è una costante di compilazione, e la
definizione di scheda distribuita è ``MODEM_PTT_ACTIVE_HIGH=1`` (attivo-alto) nel
``CMakeLists.txt`` di livello superiore. Attivo-alto significa che
riposo/non-attivato aziona il pin **basso** e attivato lo aziona alto;
attivo-basso è l'immagine speculare, quindi a riposo il pin resta alto e un LED su
quel pin resta acceso. Se il LED segue l'opposto di quanto ti aspetti, il tuo
stadio di pilotaggio inverte (un optoisolatore sì; un semplice NPN low-side no):
porta la macro all'altro valore e fai una ricompilazione pulita completa — il
valore è incorporato in ``afsk.c``, quindi una compilazione incrementale non lo
recepirà.
"Il log di avvio dice ``gpio: conflict found for GPIO[26]``."
=============================================================

Una chiamata a ``gpio_config()`` rivendica ogni pad che configura e avvisa
quando ne trova uno già rivendicato da un'altra chiamata; il pad viene
comunque configurato, quindi la riga è informativa.

GPIO26 è il pad del PTT nella definizione di scheda distribuita, ed è
configurato due volte di proposito: ``ptt_force_idle()`` in ``main.c`` lo porta
al livello di riposo come prima azione di ``app_main()``, perché la linea di
manipolazione non resti flottante dopo il reset, e ``AFSK_init()`` lo
riconfigura all'avvio del modem, circa un secondo e mezzo dopo. La seconda
chiamata restituisce prima la rivendicazione, quindi la riga non dovrebbe
comparire. Se compare, è stato usato un ESP-IDF senza l'header interno
``esp_gpio_reserve.h``, e l'avviso è innocuo.

Un conflitto su **qualsiasi altro** pin è invece reale: due funzioni puntano
allo stesso pad. Controllate il pin di allarme messaggi nella pagina Message,
l'unico che la configurazione memorizza, e i pin fissi del ``CMakeLists.txt``
radice (ADC, DAC, PTT, LED di stato).

"Telegram smette di rispondere dopo un po' di funzionamento, con 'mbedtls_ssl_fetch_input' o 'Socket is not connected' nel log."
==================================================================================================================================

Il percorso di *polling* mantiene aperta la connessione HTTPS verso l'API di
Telegram tra un ciclo e l'altro, così un *long poll* che non restituisce nulla
non paga un nuovo handshake TLS ogni dieci secondi. Se quella connessione
resta inattiva abbastanza a lungo, il peer o un NAT intermedio può chiuderla
in silenzio; il socket resta quindi obsoleto anche se localmente nulla se n'è
accorto. ``telegram_bot_client_call()`` tratta un errore di trasporto proprio
come segnale di questo: chiude forzatamente la connessione e ritenta la
richiesta su un socket appena aperto, fino a tre tentativi totali con una
pausa che cresce tra loro, così una singola sessione obsoleta si recupera da
sola entro la stessa chiamata. Se l'errore continua a ripetersi su ogni
tentativo, è la rete stessa a essere giù e non un singolo socket obsoleto;
verifica la connettività Wi-Fi/Internet e il token del bot.

"sendMessage fallisce con 'ESP_ERR_HTTP_CONNECT' subito dopo l'arrivo di un aggiornamento, preceduto da 'Dynamic Impl: alloc(...) failed'."
===========================================================================================================================================

Un handshake TLS nuovo chiede all'heap i propri buffer di record come
allocazioni singole di pochi kilobyte ciascuna, quindi a decidere se riesce è
il più grande blocco **contiguo** libero, non l'heap libero totale.
L'allocatore dell'ESP-IDF registra il rifiuto come ``Dynamic Impl: alloc(...)
failed``, mbedTLS lo trasforma in ``mbedtls_ssl_handshake returned -0x008D``
e il trasporto vede ``ESP_ERR_HTTP_CONNECT``.

Una sessione TLS viva trattiene un blocco di dimensione paragonabile finché
viene mantenuta, perciò il firmware non ne tiene mai due insieme. Il gestore
di trasmissione lavora con il keep-alive disattivato ed è quindi vuoto nel
momento in cui la chiamata ritorna, e la connessione di polling viene
rilasciata da ``telegram_release_poll_connection()`` subito prima di
qualunque richiesta in uscita, che è il momento che conta: una risposta parte
subito dopo l'arrivo di un lotto di aggiornamenti, con il payload e l'albero
decodificato ancora in memoria. Il polling paga un handshake in più al ciclo
successivo e nulla d'altro.

Ogni tentativo fallito viene registrato con l'heap libero e il blocco libero
più grande in quell'istante. Se il blocco più grande è ampiamente sopra i
quattro kilobyte e la chiamata fallisce comunque, il guasto è il collegamento
e non l'heap. Se non lo è, al dispositivo manca davvero memoria contigua:
abbassa ``rx_buffer_size`` sui gestori del client, oppure riduci quello che il
resto del firmware trattiene in quel momento.

``CONFIG_MBEDTLS_SSL_IN_CONTENT_LEN`` non è la leva che sembra. È un tetto sul
record che il peer può inviare, e la catena di certificati presentata da
Telegram si aggira sui quattro kilobyte in un solo record, quindi abbassarlo
sotto quella cifra non risparmia memoria: fa fallire l'handshake del tutto, a
ogni tentativo e con qualsiasi stato dell'heap.

``CONFIG_MBEDTLS_DYNAMIC_FREE_CONFIG_DATA`` lo è davvero, e non è gratuita. Con
``CONFIG_MBEDTLS_DYNAMIC_BUFFER`` già attiva, libera le strutture di
certificato e chiave già analizzate appena l'handshake è concluso, invece di
tenerle per tutta la durata della sessione: sono alcuni kilobyte recuperati su
una scheda il cui pool principale gira con un margine di poche unità di
kilobyte. Seleziona inoltre ``CONFIG_MBEDTLS_DYNAMIC_FREE_CA_CERT`` di default,
ed è lì che sta l'insidia: un oggetto sessione che debba rifare l'handshake
deve prima farsi registrare di nuovo la CA. Questo firmware costruisce una
connessione TLS nuova per ognuna, quindi qui nulla riusa una sessione tra
handshake, ma il sintomo da sorvegliare è una prima richiesta che riesce
seguita da altre che falliscono nell'handshake anziché in modo casuale. Se
compare, disattiva l'opzione prima di guardare altrove.

"Stamattina l'heap libero è più basso di ieri sera e il log non dice nulla."
============================================================================

Ogni altra cifra di heap che questo firmware registra viene stampata *dopo* un
guasto: le due righe del trasporto Telegram, il dettaglio di diagnosi allegato a
un avvio fallito, il percorso di errore di scrittura degli archivi JSON.
Descrivono l'heap a danno già fatto e non dicono nulla su come ci si è arrivati.
Un minimo storico caduto alle tre del mattino non lascia quindi alcuna traccia
di ciò che era in esecuzione.

La strumentazione permanente che risponde a quella domanda sta in
``main/heap_monitor.c``, è azionata dal tick a 1 Hz del servizio APRS e si
configura sotto ``APRS heap instrumentation`` in ``idf.py menuconfig``.

**Una riga per periodo.** ``CONFIG_APRS_HEAP_REPORT`` è attivo di default ed
emette una riga ogni ``CONFIG_APRS_HEAP_REPORT_PERIOD_S`` secondi::

   I (3600123) heap_monitor: free=104512 largest=45056 min_sum=41216

Tre cifre da leggere insieme. La dimensione libera è quanta memoria esiste; il
blocco libero più grande è la maggiore allocazione singola ancora possibile, e
le due che si allontanano indicano un heap che si frammenta anziché consumarsi;
il minimo è il livello più basso dall'avvio, quindi un calo rientrato prima
della riga successiva compare comunque lì. Tutte e tre sono lette per la memoria
interna a 8 bit, la stessa classe che il trasporto stampa in caso di errore,
così i due tipi di riga si possono confrontare. La riga costa tre interrogazioni
all'allocatore per periodo e nessuna memoria.

Il default di Kconfig è dieci secondi — l'``sdkconfig`` distribuito lo imposta a
60, ed è il valore da abbassare per primo quando si insegue un picco — perché il
periodo deve essere più breve degli eventi che intende cogliere, e su questo firmware sono brevi: un handshake TLS,
una riconnessione ad APRS-IS o un salvataggio di impostazioni raggiungono il
picco e rientrano in pochi secondi. Un campionatore più lento è
strutturalmente cieco a tutti loro — registra l'heap prima e dopo, mai durante,
e ogni riga che stampa è compatibile con un picco mai avvenuto. Il refresh a
1 Hz del cruscotto è ancora più fine, ma esiste solo finché un browser è aperto
sulla pagina, che non è quando avvengono l'avvio o una riconnessione non
presidiata.

.. warning::

   ``min_sum`` è una somma di minimi, non il minimo della somma. L'allocatore
   tiene un livello minimo per ogni heap registrato e questa cifra li somma,
   prendendo ogni termine nell'istante peggiore di quello specifico heap. Un ESP32 senza
   PSRAM non ha un unico heap DRAM: le riserve della ROM e del PHY dividono la
   DRAM interna in tre o quattro regioni non contigue, ciascuna registrata
   separatamente.

   Poiché i termini sono indipendenti, la somma è un *limite inferiore* del
   minimo che il totale di heap libero ha davvero raggiunto, e il limite si
   allenta al crescere del numero di heap. Un ``min_sum`` minuscolo ammette
   quindi due letture che questa riga da sola non distingue: che tutte le regioni
   fossero quasi vuote nello stesso momento, oppure che ciascuna abbia toccato il
   fondo separatamente in un momento proprio e il totale non sia mai stato in
   pericolo. Contano entrambe — una regione ferma vicino allo zero è un vero
   guasto di frammentazione, perché ``heap_caps_malloc()`` da quel momento la
   salta e l'allocatore si comporta come se non esistesse — ma richiedono lavori
   diversi. Stabilisci quale delle due hai prima di modificare qualsiasi
   allocazione, con il dettaglio qui sotto.

**Quale heap si è davvero esaurito.** ``CONFIG_APRS_HEAP_REPORT_PER_HEAP``
accompagna ogni riga con la tabella che stampa il componente heap stesso: una
riga per ogni heap registrato, con indirizzo iniziale, dimensione, libero
attuale, blocco libero più grande e minimo libero storico. È questo che separa
le due letture precedenti. Se il minimo del pool principale è nell'ordine delle
decine di kilobyte e solo le piccole regioni D/IRAM segnano quasi zero, il
riepilogo era un artefatto della somma di minimi; se anche il minimo del pool
principale è vicino allo zero, la stazione è davvero arrivata a un passo
dall'esaurire la memoria. Disattivato di default perché sono più righe per
periodo: attivalo per l'esecuzione che risponde alla domanda, poi disattivalo.

**Parentesi attorno ai percorsi pesanti.** ``CONFIG_APRS_HEAP_BRACKET`` registra
l'heap libero e il blocco libero più grande subito prima e subito dopo ogni
passaggio noto per prendersi un morso grande o duraturo: l'avvio di Telegram, la
connessione ad APRS-IS, il caricamento della configurazione, l'anello del mirror
di console, la scansione WiFi, il caricamento OTA e ogni buffer di modulo web.
``CONFIG_TELEGRAM_BOT_HEAP_BRACKET``, sotto ``Telegram bot transport``, fa lo
stesso per ogni richiesta del bot — ogni tentativo di una chiamata JSON, più il
caricamento multipart e il download del file, che aprono connessioni proprie. Le
due si annidano, portano le stesse cifre nella stessa classe di memoria e sono
pensate per essere attivate insieme.

La riga periodica dice *quando* l'heap si è mosso; una parentesi dice *cosa* lo
ha mosso, perché le sue cifre sono prese ai due lati di un passaggio con un nome
e non nell'istante in cui scadeva il periodo. Se le tacche della traccia
periodica cadono dentro una parentesi, è quel passaggio a muovere l'heap; se
cadono tra le parentesi, lo muove altro. Entrambe sono disattivate di default:
sono due righe per evento e il percorso di polling ne genera uno ogni pochi
secondi.

**Attribuire la memoria a un task.** Attiva ``CONFIG_HEAP_TASK_TRACKING``
(``Component config`` → ``Heap memory debugging``) e comparirà
``CONFIG_APRS_HEAP_REPORT_TASKS``, che aggiunge la tabella riepilogativa per
task sotto ogni riga di heap, così una perdita reale nomina il suo proprietario
in un solo dump invece che in una settimana di bisezione. Il tracciamento costa
RAM per ogni allocazione viva e rallenta ogni allocazione e liberazione, quindi
appartiene a una build diagnostica: disattivalo dopo.

**Margine di stack.** ``CONFIG_APRS_STACK_REPORT`` è attivo di default ed emette
una riga per ogni task ogni ``CONFIG_APRS_STACK_REPORT_PERIOD_S`` secondi
(un'ora) con il livello minimo di stack di quel task::

   I (3600130) heap_monitor: stack igate_task: 2712 bytes free at its worst
   I (3600131) heap_monitor: stack wifi: 1544 bytes free at its worst

Gli stack dei task sono il maggiore blocco singolo di RAM che questo firmware
riserva e quello che nessuno misura: ogni dimensione di stack del progetto è un
budget fissato con margine deliberato, non una cifra ritagliata su ciò di cui il
task si è rivelato aver bisogno. Senza questa riga, l'unico modo in cui uno
stack segnala di essere piccolo è traboccando, e non c'è alcun modo di scoprire
che un altro è enormemente grande. Un livello minimo può solo scendere, quindi
tra una riga e l'altra non si perde nulla: ognuna riporta il peggio che quel
task ha visto da quando è partito. Compaiono solo i task vivi: uno che
l'operatore ha spento semplicemente non ha una riga in quell'ora.

**Escludere la corruzione.** ``CONFIG_APRS_HEAP_INTEGRITY_CHECK`` scansiona ogni
heap ogni ``CONFIG_APRS_HEAP_INTEGRITY_PERIOD_S`` secondi e registra un errore,
dopo gli indirizzi che stampa il verificatore stesso, se qualcosa non va. Le
strutture corrotte dell'allocatore si presentano come comportamento
inspiegabile dell'heap e altrimenti vengono inseguite come una perdita. La
scansione mantiene il lock di ogni heap mentre lo percorre, quindi gli altri task
si bloccano se allocano nel frattempo: per questo è disattivata di default e, se
attiva, su un timer lento. Ciò che riesce a vedere dipende dal livello di
rilevamento della corruzione: senza poisoning si verificano solo le strutture
dell'allocatore, quindi scegli "Light impact" o "Comprehensive" sotto
``Heap memory debugging`` per verificare anche i byte canarino attorno a ogni
blocco allocato. Senza questo, un livello minimo inverosimile non si può
distinguere da uno corrotto.

**Individuare un overflow di stack dove avviene.**
``CONFIG_FREERTOS_WATCHPOINT_END_OF_STACK`` (``Component config`` →
``FreeRTOS`` → ``Port``) punta l'ultimo watchpoint hardware ai 32 byte finali
dello stack del task in esecuzione, così un overflow provoca un panic
sull'istruzione che lo ha causato. Il controllo del canarino attivo di default
viene eseguito solo a un cambio di contesto, quindi segnala il danno molto dopo
che il codice responsabile è già ritornato; e se l'overflow è una variabile
locale grande che scavalca la zona del canarino non viene segnalato affatto, e
riemerge più tardi come corruzione senza relazione. Questo conta quando un
crash cade in un punto impossibile, come lo scheduler che non trova alcun task
eseguibile. Il costo è un watchpoint in meno sotto gdb e fino a 60 byte in meno
su ogni stack di task, quindi appartiene a una build diagnostica insieme alle
opzioni sopra. Cattura solo le scritture che ricadono in quegli ultimi 32 byte.

**Serializzare le due operazioni di rete più pesanti.** Lo stesso modulo
possiede anche un piccolo lock non bloccante, indipendente dal campionamento
sopra descritto e sempre presente indipendentemente da quali opzioni
``CONFIG_APRS_HEAP_*`` siano attive. L'handshake TLS del bot Telegram
(:ref:`it-telegram`) e la ``connect()`` TCP dell'uplink APRS-IS
(:ref:`it-igate`) lo prendono ciascuno attorno alla propria verifica della
soglia di heap e lo rilasciano non appena quel lavoro di avvio è concluso,
cosicché non vengono mai eseguiti nello stesso istante competendo per la
stessa memoria contigua. Chi trova il lock già occupato riprova semplicemente
al proprio ciclo successivo: nulla qui resta bloccato in attesa dell'altra
parte.

"I pulsanti del menu continuano a girare e il log mostra 'query is too old and response timeout expired or query ID is invalid'."
=================================================================================================================================

Telegram invalida una callback query pochi secondi dopo la pressione del
pulsante. Rispondere è una richiesta a sé, e su questo dispositivo una
richiesta può costare un handshake TLS, quindi l'ordine in cui il lavoro
viene svolto decide se la risposta arriva ancora in tempo.

Tre cose la tengono dentro la scadenza. La query viene risposta prima che il
gestore del pulsante venga eseguito, non dopo, così costruire e inviare un
rapporto non ritarda mai la risposta. La connessione di trasmissione resta
aperta per l'intero lotto di aggiornamenti, così una raffica di pressioni
paga un handshake per tutte invece di uno ciascuna. E un singolo ciclo di
polling fallito non aggiunge alcuna pausa propria sopra i tentativi che il
trasporto ha già speso, perché quella pausa sarebbe tempo che le query in coda
passano a invecchiare; la pausa di cinque secondi viene applicata non appena i
fallimenti si ripetono, cioè quando la rete è davvero giù.

Una query realmente troppo vecchia viene rifiutata da Telegram con un 400 e
il messaggio qui sopra, e il lotto a cui apparteneva viene comunque
elaborato. Se compare una volta dopo un fallimento di polling o una
riconnessione, la coda è semplicemente sopravvissuta ai suoi aggiornamenti.
Se compare con regolarità, il dispositivo non sta affatto stando dietro al
polling: cerca i fallimenti di polling sopra di esso nel log.

"Le richieste falliscono a caso con 'mbedtls_ssl_handshake returned -0x2700', con heap in abbondanza."
======================================================================================================

``-0x2700`` è ``MBEDTLS_ERR_X509_CERT_VERIFY_FAILED``: l'handshake TLS ha
raggiunto il server, ha scambiato messaggi e poi ha rifiutato il certificato
che gli è stato mostrato. Non c'era nulla di sbagliato nel collegamento né
nell'heap, ed è per questo che le cifre stampate accanto al fallimento
sembrano sane.

``api.telegram.org`` è servito da più di un front-end e non tutti si
agganciano alla stessa autorità di certificazione. Quando il trasporto valida
contro un file PEM invece che contro il bundle dell'ESP-IDF, quel file si
fida solo delle autorità che porta davvero, quindi un file con una sola
radice valida le connessioni che finiscono su un front-end compatibile e
fallisce le altre. Quale front-end restituisca il DNS varia tra un tentativo
e l'altro, ed è esattamente per questo che il guasto sembra casuale e che un
nuovo tentativo di solito riesce.

Il trasporto lo segnala esplicitamente. Una catena rifiutata viene registrata
come ``Peer certificate refused, verification flags 0x…, validating against
<percorso>``, e l'avvio registra quanti ancoraggi di fiducia ha prodotto il
file (``Loaded N trust anchors from …``). Un solo ancoraggio con ``-0x2700``
intermittente è la firma di questo problema.

Le soluzioni sono due. Concatenare le radici mancanti nel file PEM: ogni
certificato che contiene diventa un ancoraggio di fiducia, e il file è
sostituibile dalla pagina File Storage dell'admin web senza ricompilare.
Oppure selezionare ``TELEGRAM_BOT_CERT_BUNDLE`` in menuconfig e validare
contro il bundle di certificati fornito con ESP-IDF, che copre le autorità
pubbliche e continua a funzionare quando Telegram ruota la propria catena, al
prezzo di portare il bundle nell'immagine.

Si noti che ``CONFIG_MBEDTLS_HAVE_TIME_DATE`` non è abilitato in questo
firmware, quindi le date di validità dei certificati non vengono
controllate. Un orologio non sincronizzato non è mai qui la causa di
``-0x2700``.

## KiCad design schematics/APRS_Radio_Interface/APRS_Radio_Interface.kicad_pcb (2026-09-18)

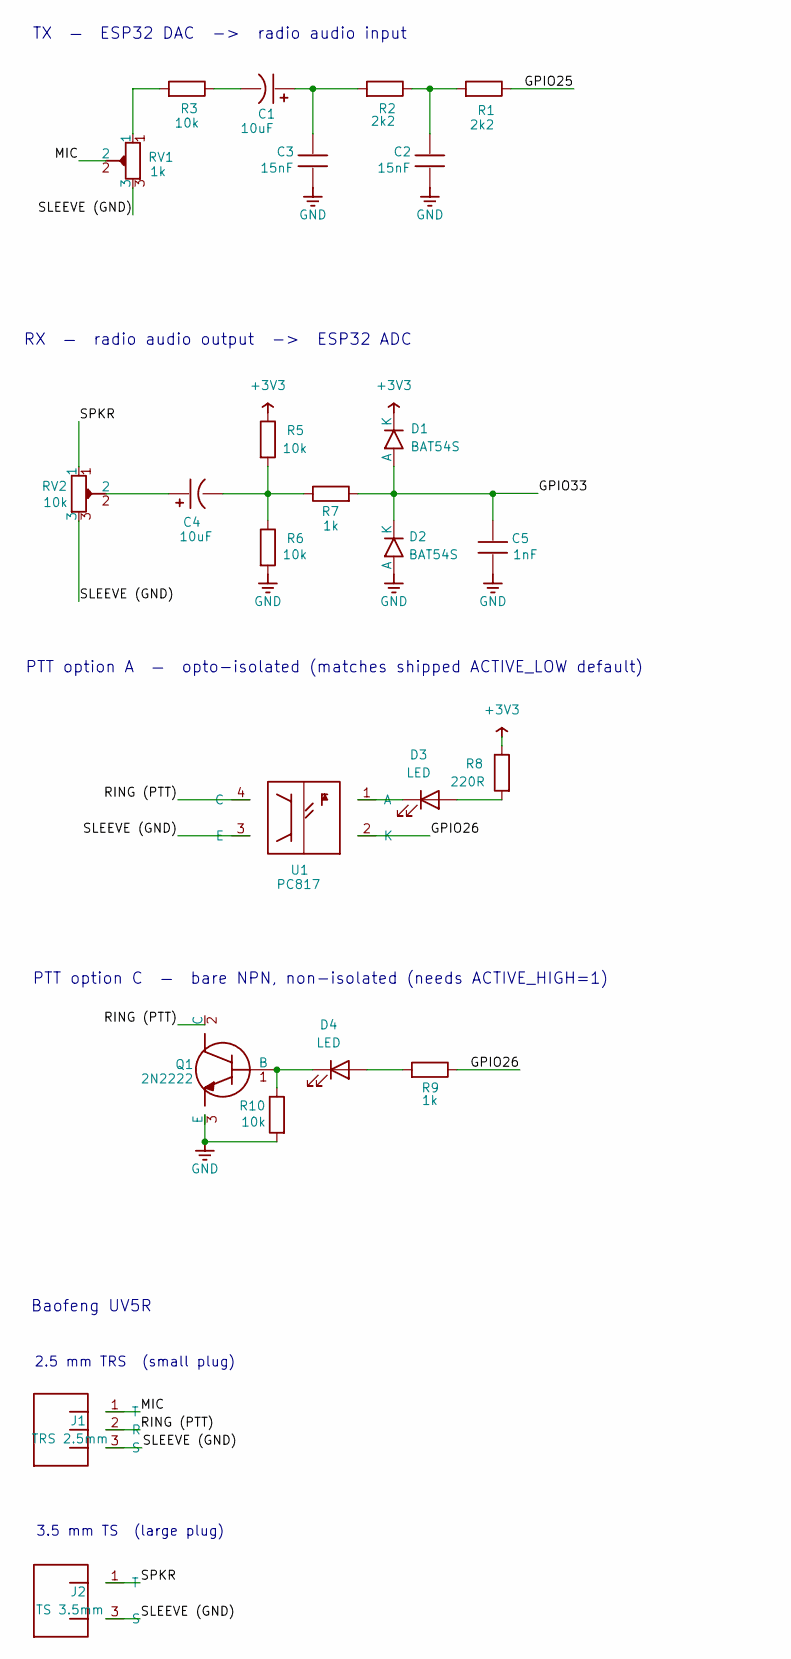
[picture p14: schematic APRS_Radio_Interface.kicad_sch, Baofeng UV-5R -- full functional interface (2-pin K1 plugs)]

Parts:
C1, C4: 10uF
C2, C3: 15nF
C5: 1nF
D1, D2: BAT54S
D3, D4: LED
J1: TRS 2.5mm
J2: TS 3.5mm
Q1: 2N2222
R1, R2: 2k2
R3, R5, R6, R10: 10k
R7, R9: 1k
R8: 220R
RV1: 1k
RV2: 10k
U1: PC817

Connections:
+3V3: D1.1 (K), R5.1, R8.1; also elsewhere on the board
GND: C2.2, C3.2, C5.2, D2.2 (A), Q1.3 (E), R6.2, R10.2; also elsewhere on the board
GPIO25: R1.1; also elsewhere on the board
GPIO26: R9.1, U1.2 (K); also elsewhere on the board
GPIO33: C5.1, D1.2 (A), D2.1 (K), R7.2; also elsewhere on the board
MIC: J1.1 (T), RV1.2
unnamed: C4.1, RV2.2
unnamed: C1.2, R3.1
unnamed: R3.2, RV1.1
unnamed: D4.1 (K), Q1.1 (B), R10.1
unnamed: D4.2 (A), R9.2
unnamed: C4.2, R5.2, R6.1, R7.1
unnamed: D3.1 (K), U1.1 (A)
unnamed: D3.2 (A), R8.2
unnamed: C2.1, R1.2, R2.1
unnamed: C1.1, C3.1, R2.2
RING (PTT): J1.2 (R), Q1.2 (C), U1.4 (C)
SLEEVE (GND): J1.3 (S), J2.3 (S), RV1.3, RV2.3, U1.3 (E)
SPKR: J2.1 (T), RV2.1

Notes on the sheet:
3.5 mm TS (large plug)
TX — ESP32 DAC -> radio audio input
2.5 mm TRS (small plug)
Baofeng UV5R
RX — radio audio output -> ESP32 ADC
PTT option A — opto-isolated (matches shipped ACTIVE_LOW default)
PTT option C — bare NPN, non-isolated (needs ACTIVE_HIGH=1)

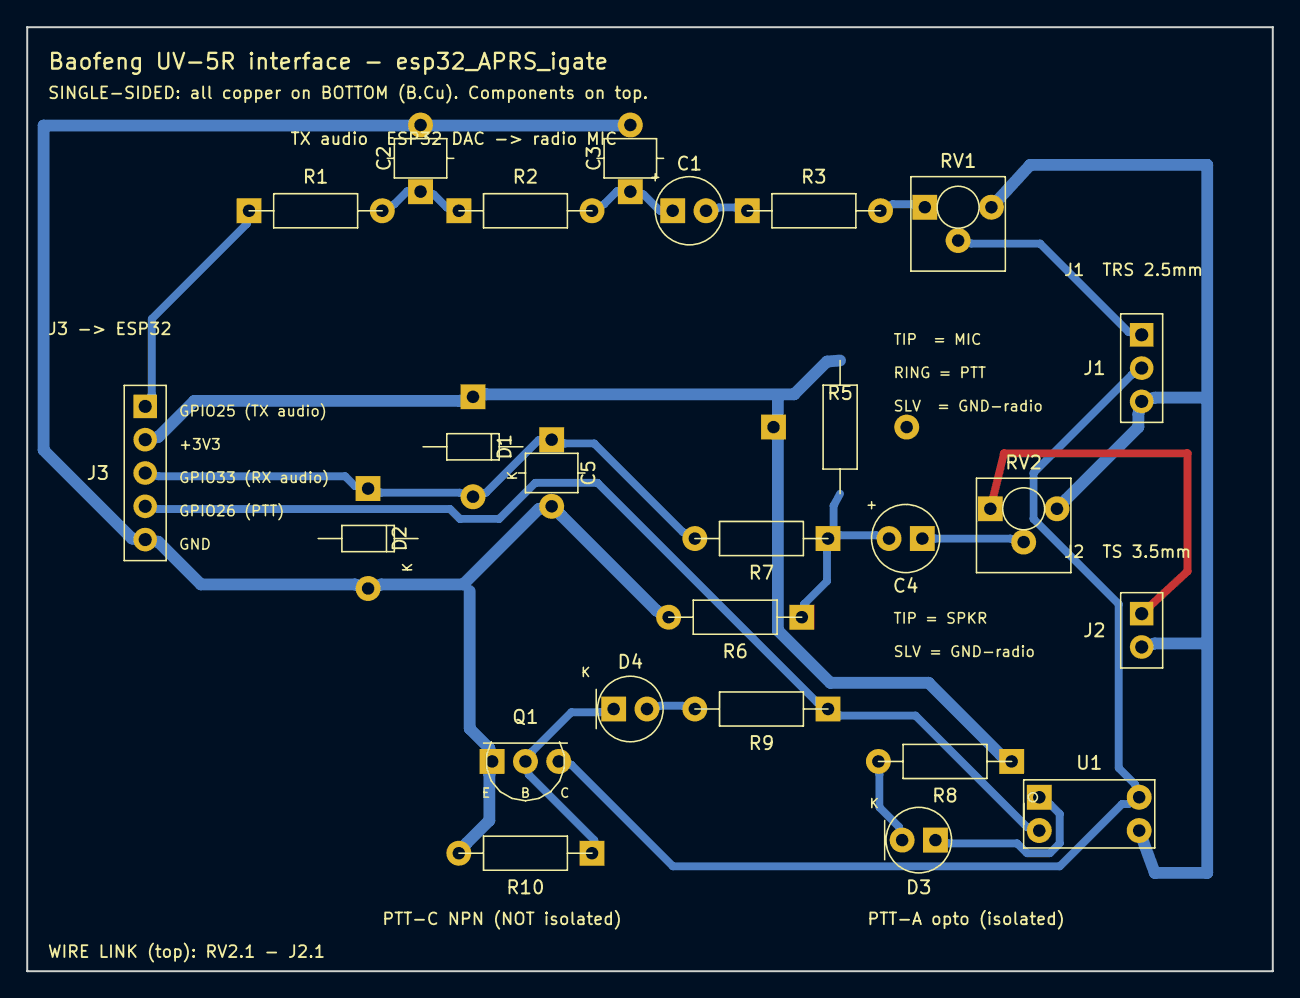
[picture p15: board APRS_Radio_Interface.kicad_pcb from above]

Board: 2 copper layers, 95.0 x 72.0 mm, 25 parts (0 on the bottom side), 19 nets.

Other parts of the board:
J3: ESP32; HDR_1x05

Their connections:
+3V3: J3.2; also elsewhere on the board
GND: J3.5; also elsewhere on the board
GPIO25: J3.1; also elsewhere on the board
GPIO26: J3.4; also elsewhere on the board
GPIO33: J3.3; also elsewhere on the board

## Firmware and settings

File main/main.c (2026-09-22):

// @file main.c
//
// @author Emiliano Augusto Gonzalez ( lu3vea @ gmail . com)
// @date 2026
// @copyright GNU General Public License v3
// @see https://github.com/hiperiondev/esp32idf_APRS
//
// @note
// This is based on other projects:
//     VP-Digi: https://github.com/sq8vps/vp-digi
//     ESP32APRS: https://github.com/nakhonthai/ESP32APRS_Audio
//     LibAPRS: https://github.com/markqvist/LibAPRS
//
//     please contact their authors for more information.
//
// @brief Firmware entry point: PTT idle level, NVS/LittleFS bring-up,
// configuration load, WiFi station/AP setup and event handling, and creation of
// the application task that starts the CPU frequency policy, SNTP client, APRS
// services and the radio modem, bringing up the web admin server last once free
// heap allows it.

#include <string.h>

#include "driver/gpio.h"
#include "esp_event.h"
#include "esp_heap_caps.h"
#include "esp_log.h"
#include "esp_netif.h"
#include "esp_ota_ops.h"
#include "esp_system.h"
#include "esp_timer.h"
#include "esp_wifi.h"
#include "freertos/FreeRTOS.h"
#include "freertos/task.h"
#include "nvs_flash.h"

#include "app_config.h"
#include "aprs_service.h"
#include "cpu_freq.h"
#include "esp32idf_radioamateur_modem.h"
#include "gps.h"
#include "net_state.h"
#include "storage.h"
#include "telegram_app.h"
#include "time_sync.h"
#include "web_server.h"

static const char *TAG = "main";

// app_main() runs on the system "main" task, whose stack size is fixed by
// CONFIG_ESP_MAIN_TASK_STACK_SIZE (3584 bytes by default) and is not meant to
// host heavy work. wifi_init()/web_server_start() (esp_netif, esp_wifi,
// esp_http_server, cJSON, etc.) can easily use several KB of stack between
// them, which does not fit there. Rather than grow a stack shared with the
// system, all of that work runs on the dedicated task created below, with an
// explicit and generous stack size of its own.
#define APP_TASK_STACK_SIZE 8192
#define APP_TASK_PRIORITY   5

// Pause between the two boot attempts at reading the configuration. The failure
// app_config_load() reports is a read that could not be completed at all
// (typically no contiguous heap for the parse), so the retry is worth making
// only after the allocations made during early startup have settled.
#define CONFIG_LOAD_RETRY_DELAY_MS 250

// Fixed delay applied before every reconnect attempt after a STA disconnect.
#define RECONNECT_INTERVAL_MS 5000

// Memory class the gate below checks: internal 8-bit memory, the same
// capability mask heap_monitor.c samples every minute, so the two figures are
// always read against each other.
#define WEB_SERVER_HEAP_CAPS (MALLOC_CAP_INTERNAL | MALLOC_CAP_8BIT)

// Minimum largest-contiguous-free-block the web admin server waits for before
// it binds its listening socket, and the longest this boot will wait for that
// much to be available. httpd_start() itself needs a single block at least
// config.stack_size (20480 bytes, see web_server.c) bytes long for the httpd
// task's stack, so the threshold is that size plus headroom for the first
// admin page's own buffers. Total free heap can stay well above this while
// still being too fragmented to satisfy that one allocation, which is why the
// gate checks the largest block rather than the total. The web server is
// started last, after every other service has made its own allocations,
// specifically so this check sees the heap in the state the station will
// actually run in.
#define WEB_SERVER_MIN_LARGEST_FREE_BLOCK (20480 + 4096)
#define WEB_SERVER_HEAP_WAIT_MAX_MS       5000
#define WEB_SERVER_HEAP_POLL_INTERVAL_MS  100

// True when the configured wifi_mode includes a station interface AND a usable
// STA entry was actually found and pushed to the driver. Gates every automatic
// esp_wifi_connect(): without it, the WIFI_EVENT_STA_START handler below would
// also fire (and try to associate) when page_wireless.c's WiFi-scan handler
// temporarily flips an AP-only radio to AP+STA, which would fight the scan.
static bool s_staEnabled = false;

// One-shot timer used to defer a reconnect attempt, rather than a vTaskDelay()
// inside the event handler: event handlers run on the shared event-loop task,
// so sleeping there would stall every other event - including the
// IP_EVENT_STA_GOT_IP this code is waiting for, and the AP's own events while
// in AP+STA mode.
static esp_timer_handle_t s_reconnectTimer = NULL;

static void try_connect(const char *why) {
    if (!s_staEnabled)
        return;
    esp_err_t err = esp_wifi_connect();
    // esp_wifi_connect() failing is the whole reason this function exists:
    // a connect that never starts never produces a WIFI_EVENT_STA_DISCONNECTED
    // either, so the retry path (which lives in the disconnect handler) would
    // never run and the station would sit dead and silent. Reporting the
    // result of every attempt makes that case visible and recoverable.
    if (err == ESP_OK)
        ESP_LOGI(TAG, "STA connect requested (%s)", why);
    else
        ESP_LOGE(TAG, "STA connect (%s) failed: %s", why, esp_err_to_name(err));
}

static void reconnect_timer_cb(void *arg) {
    try_connect("retry");
}

static void wifi_event_handler(void *arg, esp_event_base_t base, int32_t id, void *data) {
    if (base != WIFI_EVENT)
        return;

    if (id == WIFI_EVENT_STA_START) {
        // esp_wifi_connect() is only legal once the station interface has
        // actually started, and esp_wifi_start() signals that by posting this
        // event - it does not finish the job before returning. Calling
        // esp_wifi_connect() on the app task immediately after esp_wifi_start()
        // can lose that race and return ESP_ERR_WIFI_NOT_STARTED, with no
        // association and no WIFI_EVENT_STA_DISCONNECTED to trigger a retry
        // (the retry lives only in the disconnect handler). Connecting from
        // here is the order ESP-IDF guarantees.
        try_connect("STA_START");
    } else if (id == WIFI_EVENT_STA_DISCONNECTED) {
        wifi_event_sta_disconnected_t *d = (wifi_event_sta_disconnected_t *)data;

        // No AP link -> definitely no internet route until we reconnect AND
        // get a fresh IP (see ip_event_handler below).
        net_state_set_connected(false);

        // The reason code is the single most useful number when a station
        // won't associate: 15 (4WAY_HANDSHAKE_TIMEOUT) or 204 (NOT_AUTHED)
        // means the password is wrong, 201 (NO_AP_FOUND) means the SSID
        // isn't visible (wrong name, out of range, or 5 GHz-only), 2/8/200
        // are ordinary roaming/AP-side drops.
        ESP_LOGW(TAG, "STA disconnected from '%s', reason %d, retrying in %u ms...", (d && d->ssid_len) ? (const char *)d->ssid : "?", d ? (int)d->reason : -1,
                 (unsigned)RECONNECT_INTERVAL_MS);

        // Deferred, not slept: see the note on s_reconnectTimer. Every
        // disconnect - whether transient or persistent - waits the same
        // fixed interval before the next esp_wifi_connect() attempt.
        if (s_reconnectTimer) {
            esp_timer_stop(s_reconnectTimer); // no-op if not armed
            esp_timer_start_once(s_reconnectTimer, (uint64_t)RECONNECT_INTERVAL_MS * 1000ULL);
        }
    } else if (id == WIFI_EVENT_AP_STACONNECTED) {
        ESP_LOGI(TAG, "Client connected to AP");
    }
}

// Fires once the STA interface actually has an IP (i.e. a real route to the
// internet, as opposed to merely being associated to the AP). This is the
// signal internet-dependent services (APRS-IS IGate) wait on before they
// attempt anything - see net_state.h.
static void ip_event_handler(void *arg, esp_event_base_t base, int32_t id, void *data) {
    if (base == IP_EVENT && id == IP_EVENT_STA_GOT_IP) {
        ip_event_got_ip_t *event = (ip_event_got_ip_t *)data;
        ESP_LOGI(TAG, "STA got IP: " IPSTR " - internet route available", IP2STR(&event->ip_info.ip));
        net_state_set_connected(true);
    }
}

// Applies the SoftAP settings from the running configuration.
//
// Nothing in here may abort. The access point is the only way back into the
// device when no station can associate, so a value the driver refuses has to
// end as a log line and a fallback, not as a panic: a panic lands before
// esp_wifi_start(), which leaves the device with no AP and no STA, rebooting
// into the same panic on every power cycle and recoverable only over serial.
//
// The channel is clamped on save and on load, so the retry below is the last
// line of defence for anything that still reaches the driver out of range.
static void wifi_apply_ap_config(void) {
    wifi_config_t ap_cfg = { 0 };
    size_t ssid_len = strnlen(g_config.wifi_ap_ssid, sizeof(ap_cfg.ap.ssid));
    memcpy(ap_cfg.ap.ssid, g_config.wifi_ap_ssid, ssid_len);
    ap_cfg.ap.ssid_len = (uint8_t)ssid_len;
    size_t pass_len = strnlen(g_config.wifi_ap_pass, sizeof(ap_cfg.ap.password));
    memcpy(ap_cfg.ap.password, g_config.wifi_ap_pass, pass_len);
    ap_cfg.ap.channel = g_config.wifi_ap_ch;
    ap_cfg.ap.max_connection = 4;
    ap_cfg.ap.authmode = strlen(g_config.wifi_ap_pass) >= 8 ? WIFI_AUTH_WPA2_PSK : WIFI_AUTH_OPEN;

    if (ap_cfg.ap.channel < WIFI_AP_CH_MIN || ap_cfg.ap.channel > WIFI_AP_CH_MAX) {
        ESP_LOGW(TAG, "SoftAP channel %u outside %u-%u, using %u", (unsigned)ap_cfg.ap.channel, (unsigned)WIFI_AP_CH_MIN, (unsigned)WIFI_AP_CH_MAX,
                 (unsigned)WIFI_AP_CH_DEFAULT);
        ap_cfg.ap.channel = WIFI_AP_CH_DEFAULT;
    }

    esp_err_t err = esp_wifi_set_config(WIFI_IF_AP, &ap_cfg);
    if (err != ESP_OK) {
        ESP_LOGE(TAG, "esp_wifi_set_config(AP) rejected the stored settings: %s - retrying on channel %u", esp_err_to_name(err), (unsigned)WIFI_AP_CH_DEFAULT);
        ap_cfg.ap.channel = WIFI_AP_CH_DEFAULT;
        err = esp_wifi_set_config(WIFI_IF_AP, &ap_cfg);
    }
    if (err != ESP_OK)
        ESP_LOGE(TAG, "esp_wifi_set_config(AP) failed: %s - the access point will not come up, fix the Wireless page over a station link or reflash",
                 esp_err_to_name(err));
}

static void wifi_init(void) {
    ESP_ERROR_CHECK(esp_netif_init());
    ESP_ERROR_CHECK(esp_event_loop_create_default());
    esp_netif_create_default_wifi_ap();
    esp_netif_create_default_wifi_sta();

    wifi_init_config_t cfg = WIFI_INIT_CONFIG_DEFAULT();
    ESP_ERROR_CHECK(esp_wifi_init(&cfg));
    ESP_ERROR_CHECK(esp_event_handler_register(WIFI_EVENT, ESP_EVENT_ANY_ID, &wifi_event_handler, NULL));
    ESP_ERROR_CHECK(esp_event_handler_register(IP_EVENT, IP_EVENT_STA_GOT_IP, &ip_event_handler, NULL));

    // Map this project's interface selector onto the IDF mode enum. The two
    // numbering schemes are independent, so the mapping is spelled out rather
    // than cast.
    wifi_mode_t mode = WIFI_MODE_NULL;
    switch (g_config.wifi_mode) {
        case WIFI_MODE_CFG_STA:
            mode = WIFI_MODE_STA;
            break;
        case WIFI_MODE_CFG_AP:
            mode = WIFI_MODE_AP;
            break;
        case WIFI_MODE_CFG_APSTA:
            mode = WIFI_MODE_APSTA;
            break;
        default:
            // Covers WIFI_MODE_CFG_OFF and any value outside the selector
            // range: the SoftAP comes up regardless, so the web admin is
            // always reachable and no stored value can lock the operator out
            // of a headless station.
            mode = WIFI_MODE_AP;
            break;
    }
    ESP_ERROR_CHECK(esp_wifi_set_mode(mode));

    if (mode == WIFI_MODE_AP || mode == WIFI_MODE_APSTA)
        wifi_apply_ap_config();

    if (mode == WIFI_MODE_STA || mode == WIFI_MODE_APSTA) {
        for (int i = 0; i < WIFI_STA_NUM; i++) {
            if (g_config.wifi_sta[i].enable && g_config.wifi_sta[i].wifi_ssid[0]) {
                wifi_config_t sta_cfg = { 0 };
                strncpy((char *)sta_cfg.sta.ssid, g_config.wifi_sta[i].wifi_ssid, sizeof(sta_cfg.sta.ssid) - 1);
                strncpy((char *)sta_cfg.sta.password, g_config.wifi_sta[i].wifi_pass, sizeof(sta_cfg.sta.password) - 1);

                // Advertise PMF capability. A zeroed wifi_config_t leaves
                // pmf_cfg.capable = false, and an AP configured for WPA3 or
                // WPA2 with PMF required will simply refuse such a station -
                // it associates and is immediately dropped, or never gets
                // past the handshake. "capable, not required" is the setting
                // that works against both old and new APs.
                sta_cfg.sta.pmf_cfg.capable = true;
                sta_cfg.sta.pmf_cfg.required = false;

                // Same reasoning as the AP path: the station credentials also
                // come from stored data, and a set that the driver refuses
                // must not take the boot down. Log it and try the next slot,
                // so the access point still comes up either way.
                esp_err_t serr = esp_wifi_set_config(WIFI_IF_STA, &sta_cfg);
                if (serr != ESP_OK) {
                    ESP_LOGE(TAG, "esp_wifi_set_config(STA) rejected slot %d ('%s'): %s - skipping it", i, g_config.wifi_sta[i].wifi_ssid,
                             esp_err_to_name(serr));
                    continue;
                }
                s_staEnabled = true;
                ESP_LOGI(TAG, "STA entry %d selected: SSID '%s'", i, g_config.wifi_sta[i].wifi_ssid);
                break; // first enabled entry; multi-AP failover can be added later
            }
        }

        // Loudly, because this is the other half of "I switched to STA and
        // nothing happened": if the loop above finds nothing, no STA config is
        // handed to the driver, and a bare esp_wifi_connect() would just return
        // ESP_ERR_WIFI_SSID into a discarded return value and fail silently.
        // Every WiFi Client block on the Wireless page has its own "Enable"
        // checkbox, separate from the Mode dropdown, and selecting Station mode
        // without ticking one leaves the station with nothing to connect to.
        if (!s_staEnabled) {
            ESP_LOGE(TAG, "wifi_mode=%u selects a station, but no WiFi Client entry is enabled with an SSID.", (unsigned)g_config.wifi_mode);
            // Dump every slot: "enabled but SSID empty" and "SSID set but not
            // enabled" are different mistakes with different fixes, and the
            // single summary line above cannot tell them apart.
            for (int i = 0; i < WIFI_STA_NUM; i++) {
                ESP_LOGE(TAG, "     slot %d: enable=%s ssid='%s'%s", i, g_config.wifi_sta[i].enable ? "true" : "false", g_config.wifi_sta[i].wifi_ssid,
                         (g_config.wifi_sta[i].enable && !g_config.wifi_sta[i].wifi_ssid[0])   ? "   <-- enabled, but the SSID is EMPTY"
                         : (!g_config.wifi_sta[i].enable && g_config.wifi_sta[i].wifi_ssid[0]) ? "   <-- has an SSID, but 'Enable' is not ticked"
                                                                                               : "");
            }
            ESP_LOGE(TAG, "  -> On the Wireless page, tick 'Enable' in a WiFi Client block and type an SSID, then Save.");
            if (mode == WIFI_MODE_STA) {
                // STA-only with nothing to join means no AP either: the device
                // would be unreachable over the air with no way back short of a
                // serial reflash. Fall back to AP+STA so the web admin stays up.
                ESP_LOGW(TAG, "  -> Falling back to AP+STA so the web admin stays reachable on '%s'.", g_config.wifi_ap_ssid);
                mode = WIFI_MODE_APSTA;
                ESP_ERROR_CHECK(esp_wifi_set_mode(mode));
                wifi_apply_ap_config();
            }
        }
    }

    // Armed by the disconnect handler, fired on the esp_timer task - never on
    // the event loop. Created before esp_wifi_start() so it exists by the time
    // the first event can arrive.
    if (s_staEnabled) {
        const esp_timer_create_args_t targs = {
            .callback = reconnect_timer_cb,
            .name = "wifi_reconnect",
        };
        ESP_ERROR_CHECK(esp_timer_create(&targs, &s_reconnectTimer));
    }

    ESP_ERROR_CHECK(esp_wifi_start());

    // Modem sleep off. The default powers the radio down between DTIM beacons,
    // which suits a sensor that wakes, posts and sleeps again; this station
    // instead holds an APRS-IS socket, an admin web server and, when the
    // Telegram bot is enabled, a TLS long poll, all at once and all of them
    // latency-sensitive. With the radio asleep most of the time, transmits
    // queue behind the next wake-up: sockets report EAGAIN under load and a
    // TLS handshake can exhaust its whole timeout while a plain connection to
    // the same address completes in a few hundred milliseconds.
    //
    // A sleeping radio also misses the periodic WPA2 group key update some
    // access points perform, which disconnects the station with reason 16 and
    // takes every open connection down with it.
    //
    // The cost is receiver current draw, which an always-on gateway on mains
    // power can afford. A battery-powered installation that does not run the
    // bot may prefer WIFI_PS_MIN_MODEM here.
    esp_err_t ps_err = esp_wifi_set_ps(WIFI_PS_NONE);
    if (ps_err != ESP_OK)
        ESP_LOGW(TAG, "Could not disable WiFi modem sleep: %s", esp_err_to_name(ps_err));

    // The station association is started from the WIFI_EVENT_STA_START
    // handler, once the driver reports the station interface is genuinely up,
    // rather than from here. See that handler.

    // The units differ: the config field is dBm, esp_wifi_set_max_tx_power()
    // takes quarter-dBm, hence the x4. Both the form and wireless.json paths
    // clamp the stored value to WIFI_TX_POWER_DBM_MIN..MAX, so the product
    // always lands inside the range the driver accepts and fits an int8_t.
    // Only meaningful once the radio is started.
    int8_t qdbm = (int8_t)(g_config.wifi_power * 4);
    esp_err_t perr = esp_wifi_set_max_tx_power(qdbm);
    if (perr != ESP_OK)
        ESP_LOGW(TAG, "esp_wifi_set_max_tx_power(%d dBm) failed: %s", (int)g_config.wifi_power, esp_err_to_name(perr));

    ESP_LOGI(TAG, "WiFi started in mode %d (AP SSID '%s', STA %s)", (int)mode, g_config.wifi_ap_ssid, s_staEnabled ? "enabled" : "disabled");
}

// Blocks until heap_caps_get_largest_free_block(WEB_SERVER_HEAP_CAPS) reaches
// WEB_SERVER_MIN_LARGEST_FREE_BLOCK or WEB_SERVER_HEAP_WAIT_MAX_MS has
// elapsed, whichever comes first, then starts the web admin server either
// way. Every other service has already made its allocations by the time this
// runs, so a heap that is still too fragmented after the wait is reported and
// the server is started anyway: an admin UI reachable under memory pressure
// is more useful to the operator than no admin UI at all, and refusing to
// start it here would leave the station with no way to diagnose or
// reconfigure itself over the network.
static void web_server_start_when_heap_ready(void) {
    TickType_t start = xTaskGetTickCount();
    uint32_t largestBlock = heap_caps_get_largest_free_block(WEB_SERVER_HEAP_CAPS);

    while (largestBlock < WEB_SERVER_MIN_LARGEST_FREE_BLOCK) {
        TickType_t elapsedTicks = xTaskGetTickCount() - start;
        if (elapsedTicks >= pdMS_TO_TICKS(WEB_SERVER_HEAP_WAIT_MAX_MS)) {
            ESP_LOGW(TAG, "Largest free block still %u bytes after %d ms wait (wanted %u), starting web admin anyway", (unsigned)largestBlock,
                     WEB_SERVER_HEAP_WAIT_MAX_MS, (unsigned)WEB_SERVER_MIN_LARGEST_FREE_BLOCK);
            break;
        }
        vTaskDelay(pdMS_TO_TICKS(WEB_SERVER_HEAP_POLL_INTERVAL_MS));
        largestBlock = heap_caps_get_largest_free_block(WEB_SERVER_HEAP_CAPS);
    }

    web_server_start();
}
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
void app_main(void) {
    ptt_force_idle();

    esp_err_t ret = nvs_flash_init();
    if (ret == ESP_ERR_NVS_NO_FREE_PAGES || ret == ESP_ERR_NVS_NEW_VERSION_FOUND) {
        ESP_ERROR_CHECK(nvs_flash_erase());
        ret = nvs_flash_init();
    }
    ESP_ERROR_CHECK(ret);

    if (!storage_init()) {
        ESP_LOGE(TAG, "LittleFS mount failed - config cannot persist!");
    }

    BaseType_t ok = xTaskCreate(app_task, "app_task", APP_TASK_STACK_SIZE, NULL, APP_TASK_PRIORITY, NULL);
    if (ok != pdPASS) {
        ESP_LOGE(TAG, "Failed to create app_task (out of memory?)");
    }

    // app_main can now return; the system main task frees its stack and
    // FreeRTOS deletes the task automatically (idf.py default behavior).
}

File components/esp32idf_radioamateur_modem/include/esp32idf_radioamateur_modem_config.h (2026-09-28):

/**
 * @file esp32idf_radioamateur_modem_config.h
 *
 * @author Emiliano Augusto Gonzalez ( lu3vea @ gmail . com)
 * @date 2026
 * @copyright GNU General Public License v3
 * @see https://github.com/hiperiondev/esp32idf_APRS
 *
 * @note
 * This is based on other projects:
 *     VP-Digi: https://github.com/sq8vps/vp-digi
 *     ESP32APRS: https://github.com/nakhonthai/ESP32APRS_Audio
 *     LibAPRS: https://github.com/markqvist/LibAPRS
 *
 *     please contact their authors for more information.
 *
 * @brief Compile-time board configuration for the modem: the audio DAC/ADC
 * pins, the optional PTT/LED control pins, the sample-rate/DSP parameters, and
 * the derived values and consistency checks computed from them.
 *
 * Every value that must be adapted to a particular board lives here. All values
 * may be overridden from the build system (for example
 * @c idf.py @c build @c -DMODEM_ADC_GPIO=32, or @c target_compile_definitions
 * in CMakeLists.txt).
 *
 * @note soc/soc_caps.h is included for @c SOC_ADC_DIGI_RESULT_BYTES /
 * @c SOC_ADC_DIGI_DATA_BYTES_PER_CONV, used by the derived-value checks at the
 * bottom of this file.
 */

#ifndef ESP32IDF_RADIOAMATEUR_MODEM_CONFIG_H_
#define ESP32IDF_RADIOAMATEUR_MODEM_CONFIG_H_

#include "soc/soc_caps.h"

/**
 * @brief GPIO used for the modulated audio output (DAC).
 *
 * The ESP32 has two 8-bit DACs, hard-wired to fixed pads and not routable
 * through the GPIO matrix, so only these two pins can ever be used:
 *  - GPIO25 -> DAC channel 1 (DAC_CHAN_0), the default.
 *  - GPIO26 -> DAC channel 2 (DAC_CHAN_1).
 *
 * Any other value produces a compile error further down in this file.
 *
 * @note ESP32-S2 also has DACs (GPIO17/GPIO18). ESP32-S3/C3/C6/H2 have no
 *       DAC at all and would require an external DAC, PWM or sigma-delta
 *       output instead.
 */
#ifndef MODEM_DAC_GPIO
#define MODEM_DAC_GPIO 25
#endif

/**
 * @brief GPIO used for the received audio input (ADC).
 *
 * The receiver uses ADC1 in continuous (DMA) mode. Allowed pins are the
 * eight ADC1 pads of the ESP32:
 *  - GPIO36 -> ADC1_CH0 (labelled SENSOR_VP / VP)
 *  - GPIO37 -> ADC1_CH1 (not bonded out on most modules)
 *  - GPIO38 -> ADC1_CH2 (not bonded out on most modules)
 *  - GPIO39 -> ADC1_CH3 (labelled SENSOR_VN / VN)
 *  - GPIO32 -> ADC1_CH4
 *  - GPIO33 -> ADC1_CH5, the default
 *  - GPIO34 -> ADC1_CH6 (input only, no internal pull-up/down)
 *  - GPIO35 -> ADC1_CH7 (input only, no internal pull-up/down)
 *
 * ADC2 pins (GPIO0/2/4/12..15/25..27) are deliberately NOT supported: ADC2
 * is shared with the Wi-Fi radio and cannot be used by the continuous-mode
 * driver on the ESP32.
 *
 * Any other value produces a compile error further down in this file.
 */
#ifndef MODEM_ADC_GPIO
#define MODEM_ADC_GPIO 33
#endif

/**
 * @brief GPIO used to drive PTT (push-to-talk), or -1 to disable it.
 *
 * This is an internal radiomodem feature and, like ::MODEM_ADC_GPIO /
 * ::MODEM_DAC_GPIO, a fixed, compile-time-only board wiring choice - it is
 * NOT exposed as a runtime/web-admin setting. Any output-capable GPIO may be
 * used (0-19, 21-23, 25-27, 32, 33). GPIO34-39 are input-only and cannot be
 * used. GPIO6-11 (internal SPI flash/PSRAM) are never usable either - see
 * afsk_gpio_is_output_capable(). Not needed for the loopback test.
 *
 * Any other value produces a compile error further down in this file.
 */
#ifndef MODEM_PTT_GPIO
#define MODEM_PTT_GPIO (-1)
#endif

/**
 * @brief Active level of the PTT output.
 * @details 1 = PTT is active-high, 0 = PTT is active-low.
 */
#ifndef MODEM_PTT_ACTIVE_HIGH
#define MODEM_PTT_ACTIVE_HIGH 1
#endif

/**
 * @brief GPIO used to drive the TX status LED, or -1 to disable it. Any
 *        output-capable GPIO may be used.
 */
#ifndef MODEM_LED_TX_GPIO
#define MODEM_LED_TX_GPIO (-1)
#endif

/**
 * @brief GPIO used to drive the RX/DCD status LED, or -1 to disable it. Any
 *        output-capable GPIO may be used.
 */
#ifndef MODEM_LED_RX_GPIO
#define MODEM_LED_RX_GPIO (-1)
#endif

/**
 * @brief Default DAC (transmit) sample rate, in Hz.
 *
 * The modulator's sine lookup table and the baud-rate divider are both
 * derived from this value. 38400 = 32 * 1200, which keeps it an exact
 * multiple of every supported baud rate; keep this property if the value is
 * ever changed.
 *
 * This is the rate the modem starts from. The rate actually programmed is
 * ::modem_config_t::dac_samplerate, selectable at runtime between this value
 * and twice it, and applied by modem_init() while the hardware is stopped.
 * Doubling it moves the DAC reconstruction images an octave further from the
 * audio band, which is worth the extra interrupt rate when the interface
 * between the DAC pin and the transceiver carries no reconstruction low-pass
 * filter.
 */
#ifndef MODEM_DAC_SAMPLERATE
#define MODEM_DAC_SAMPLERATE 38400
#endif
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

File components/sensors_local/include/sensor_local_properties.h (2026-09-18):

/**
 * @file sensor_local_properties.h
 *
 * @author Emiliano Augusto Gonzalez ( lu3vea @ gmail . com)
 * @date 2026
 * @copyright GNU General Public License v3
 * @see https://github.com/hiperiondev/esp32idf_APRS
 *
 * @note
 * This is based on other projects:
 *     VP-Digi: https://github.com/sq8vps/vp-digi
 *     ESP32APRS: https://github.com/nakhonthai/ESP32APRS_Audio
 *     LibAPRS: https://github.com/markqvist/LibAPRS
 *
 *     please contact their authors for more information.
 *
 * @brief Common "properties" contract every local sensor driver must
 *        publish, declaring EXACTLY which APRS Weather/Telemetry
 *        parameters it is able to produce.
 *
 * @details
 * ::sensor_local_driver_t::capabilities (see sensors_local.h) only says
 * *what family* a driver belongs to (Weather and/or Telemetry). It says
 * nothing about *which* of the fields within that family the driver can
 * actually fill in. A BMP280 is a Weather sensor, but it can only ever
 * supply Temperature and Pressure - never Wind, Rain, Humidity, etc. This
 * header closes that gap.
 *
 * Every sensor driver (weather or telemetry) owns exactly one
 * "<sensor>_properties.h" (e.g. bme280_properties.h, wx_example_properties.h,
 * tlm_example_properties.h) declaring a single @c static @c const
 * ::sensor_local_properties_t and pointing
 * ::sensor_local_driver_t::properties at it. This lets any consumer of the
 * registry (chiefly the Weather page's per-field "Channel" picker in
 * page_wx.c) offer only the sensors that are actually capable of a given
 * field/channel, instead of every registered driver regardless of fitness.
 *
 * Two independent bit fields are provided, mirroring the two payload
 * families of weather_telemetry.h:
 *
 *   - ::sensor_local_wx_mask_t: one bit per ::aprs_weather_sensor_id_t
 *     (Wind Direction, Wind Speed, Wind Gust, Temperature, Rain 1h, Rain
 *     24h, Snow, Humidity, Pressure, Luminosity, Flood Height ft, Flood
 *     Height m, ...) - a WEATHER sensor sets exactly the bits it can
 *     produce.
 *
 *   - ::sensor_local_tlm_channel_mask_t: one bit per analog (A1-A5) and digital
 *     (B1-B8) telemetry channel plus flags for which of the four telemetry
 *     metadata message kinds (PARM/UNIT/EQNS/BITS) the driver can supply
 *     default values for - a TELEMETRY sensor sets exactly the analog/
 *     digital channel bits it drives.
 *
 * A driver that is Weather-only leaves @c tlm at all zero (or omits the
 * @c properties pointer's telemetry mask usage entirely); a driver that is
 * Telemetry-only leaves @c wx at all zero. A hybrid driver (rare, but
 * legal per ::sensor_local_data_kind_t) may set bits in both.
 */

#ifndef SENSOR_LOCAL_PROPERTIES_H_
#define SENSOR_LOCAL_PROPERTIES_H_

#include <stdint.h>
#include <stdio.h>

#include "weather_telemetry.h"

/**
 * @brief One bit per mappable APRS Weather Report parameter a WEATHER
 *        sensor driver can produce, mirroring ::aprs_weather_sensor_id_t
 *        (weather_telemetry.h) one-for-one, plus a split of the single
 *        ::APRS_WX_SENSOR_WIND slot into its three independently
 *        mappable web-admin fields (Direction / Speed / Gust) to match
 *        the granularity of the Weather page's per-field "Channel"
 *        column (::wx_field_id_t in app_config.h).
 *
 * @note Bit position intentionally matches ::wx_field_id_t so a mask can
 *       be tested directly with `(mask >> field_id) & 1u` from page_wx.c
 *       without an extra lookup table.
 */
typedef enum {
    SENSOR_LOCAL_WX_WIND_DIRECTION = 1u << 0,   /**< Wind Direction ("ddd/"). */
    SENSOR_LOCAL_WX_WIND_SPEED = 1u << 1,       /**< Wind Speed, sustained ("/sss"). */
    SENSOR_LOCAL_WX_WIND_GUST = 1u << 2,        /**< Wind Gust, peak ("gXXX"). */
    SENSOR_LOCAL_WX_TEMPERATURE = 1u << 3,      /**< Temperature, deg F ("tXXX"). */
    SENSOR_LOCAL_WX_RAIN_1H = 1u << 4,          /**< Rain, last 1 hour ("rXXX"). */
    SENSOR_LOCAL_WX_RAIN_24H = 1u << 5,         /**< Rain, last 24 hours ("pXXX"). */
    SENSOR_LOCAL_WX_RAIN_MIDNIGHT = 1u << 6,    /**< Rain since local midnight ("PXXX"). */
    SENSOR_LOCAL_WX_SNOW = 1u << 7,             /**< Snow, last 24 hours ("sXXX", APRS 1.2). */
    SENSOR_LOCAL_WX_HUMIDITY = 1u << 8,         /**< Relative Humidity ("hXX"). */
    SENSOR_LOCAL_WX_PRESSURE = 1u << 9,         /**< Barometric Pressure ("bXXXXX"). */
    SENSOR_LOCAL_WX_LUMINOSITY = 1u << 10,      /**< Luminosity, solar radiation ("LXXX"/"lXXX", APRS 1.2). */
    SENSOR_LOCAL_WX_FLOOD_HEIGHT_FT = 1u << 11, /**< Flood/water gauge height, feet ("FXXXX.X", APRS 1.2). */
    SENSOR_LOCAL_WX_FLOOD_HEIGHT_M = 1u << 12,  /**< Flood/water gauge height, meters ("fXXXX.X", APRS 1.2). */
    SENSOR_LOCAL_WX_RAIN_RAW = 1u << 13,        /**< Raw tip-bucket rain counter ("#XXXX"). */

    SENSOR_LOCAL_WX_NONE = 0,              /**< No weather parameter (telemetry-only or uninitialised driver). */
    SENSOR_LOCAL_WX_ALL = (1u << 14) - 1u, /**< Convenience: every weather bit currently defined. */
} sensor_local_wx_mask_t;
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

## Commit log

2026-09-18 Promoted to beta
    [APRS_Radio_Interface.kicad_pcb, APRS_Radio_Interface.kicad_sch, partitions.csv]
2026-09-19 webconfig: add ALLOW_SHOW_PASSWORD to keep stored secrets off the wire
2026-09-21 igate: add web switch to fully disable duplicate suppression
2026-09-21 Open the console port without resetting the ESP32 and drive PTT idle at boot
    [main.c]
2026-09-22 modem: tilt-diversity demodulators and configurable RX chain for flat/discriminator input
2026-09-22 modem RX: 48-tap anti-alias decimator, L2 tone magnitudes, shared-correlator multi-slicer set (default); accept UI+P/F, full-length APRS frames, gate FX.25 tag search
2026-09-23 modem: widen twist coverage, tone-band level and gate, quiet reconfiguration
    - Multi-slicer set: 8 demodulators on two tilted prefilters; slicer weights
    derive from each prefilter's realized tilt, stepping 3.5 dB over
    +16..-8.5 dB (speaker) and +9..-15.5 dB (flat).
    - Defaults: 31-tap prefilters and a 300 Hz high-pass.
    - Tone-band level meter (afskGetBandRms); the receive gate follows it.
    - modem_set_modem() rebuilds the receive chain only when it changed; the
    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
2026-09-27 Correct modem and audio test
    [app_config.c, app_config.h, aprs_service.c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]
2026-09-28 modem: 12-slicer multi-slicer set covering flat and de-emphasized twist (±16.5 dB), 4th-order RX high-pass up to 800 Hz, one-pole DC tracker, impulse-blanker crest fix
    [app_config.c, aprs_service.c, esp32idf_radioamateur_modem.h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]

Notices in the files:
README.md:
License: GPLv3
